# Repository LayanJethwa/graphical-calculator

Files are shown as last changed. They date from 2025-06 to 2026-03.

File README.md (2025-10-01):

## Graphical calculator ##

This design is for a graphical calculator that I am making, which will be able to plot graphs on a screen provided in human-readable infix notation.

I decided to make this as a fun maths-based project for my Computer Science NEA.

## Introduction ##

Graphical calculators and software are widely used in advanced mathematics. They are an easy way to visualise and analyse graphs and are useful in a classroom setting as well as to verify solutions to problems. Free digital softwares such as Desmos and Geogebra are used extensively, but they work best on computers, and it is not desirable to have them on phones either in a lesson. Physical graphical calculators are therefore used, created by companies such as Casio and Texas Instruments.

However, these physical calculators are very expensive. The Casio fx-CG50, one of the leading devices in the field, costs £140 from the manufacturer. These calculators are very good, with a multitude of features, but a lot of these features are very rarely used, adding to the price point unnecessarily. Additionally, these calculators function as scientific calculators as well, but people that own them generally also own a scientific calculator anyway that they use mainly for calculations.

I aim to create a physical calculator that is only for plotting graphs. This will be less costly to build and produce, and I will be able to tailor it to the end user. The hardware will be specialised, having a screen with a higher resolution than the CG50, and I will 3D print parts specifically for ergonomics.

## Features ##

- Explicitly defined graphs
    - Polynomials
    - Radicals
    - Exponentials
    - Reciprocals
    - Logarithmic graphs
    - Trigonometric graphs (sin, cos, tan and reciprocals)
    - Parametric graphs
    - Differential equations
    - Indefinite integrals
    - Combinations of the above
    - x = f(y) graphs
- Implicitly defined graphs
    - Circles
    - Ellipses
    - Parabolas
    - Horizontal parabolas
    - Hyperbolas
    - Multiple graphs simultaneously
- Graph manipulation
    - Pan
    - Zoom
    - View window
        - Axis bounds
        - Axis scaling
    - Graph colouring
- Buttons
    - Golden button
    - Degrees-radians ~~rocker switch~~ toggle switch
    - Zoom ~~momentary toggle switch~~ tactile switches
- Other features
    - Auto power-off

## Demo ##

You can see a software demo at the website: https://layanjethwa.github.io/graphical-calculator/code/build/web/

Currently it is not complete and I have only implemented methods for a few functions. As they will be triggered by physical switches on the calculator, they are triggered by keys currently:

| Keyboard key |  Calculator function  |
|:-----|---:|
| SHIFT + =  | + (addition) |
| SHIFT + 9 |  ( (left bracket)  |
| SHIFT + 0 | ) (right bracket) |
| SHIFT + 8 | * (multiplication) |
| q | squared |
| w | cubed |
| x | variable letter x |
| / | divide |
| p | pi |
| l | log |
| s | sin |
| c | cos |
| t | tan |
| r | csc |
| y | sec |
| u | cot |

The syntax of the log function is [base]log([value]), e.g. 2log(x) means log base 2 of x. Implicit multiplication is not currently defined for all functions.

You can use the arrow keys to pan around the graph, n to zoom in, and m to zoom out. When you enter the function, press enter to confirm, and then enter again to go to the graph page. You can also use the arrow keys on the input page to add more graphs to the display.

## Hardware ##

The PCB will be shaped like the calculator, and the switches for the buttons will be mounted to it directly. It will have connectors for the screen, CPU, and battery as well. 

The CPU I will be using is the Raspberry Pi Zero 2 W. It is 65mm x 30mm, so fairly small and will fit nicely in the calculator. It has 512 MB of RAM, and a clock speed of 1GHz, so it will not be able to handle more intensive computations. It has WiFi and Bluetooth connectivity, although I am not planning to use them, as well as a USB 2.0 port, a microSD card slot, a mini HDMI port, and a 40 pin I/O header. I will have to install an operating system on it, probably Raspbian, to run Python code.

The screen I have decided to use is a 3.5 inch LCD screen, intended for a display for a Raspberry Pi. It has a 320x480 pixel resolution, and also features resistive touch control, though I probably will not be utilizing that feature of it. The resolution is higher than the Casio fx-CG50, one of the leading graphical calculators, so it should be more than enough for my purposes. The screen is £24 directly from the manufacturer. The screen connects via ~~HDMI~~ TFT, and is powered by a micro USB connection.

I have decided to use tactile switches with attached shafts, which, as mentioned, will be soldered directly to the PCB. I plan on using the Omron B3F-1050 switches, which I can get from DigiKey, at around 12.5p each for the number I will require. They have dimensions of 6 x 6 mm with a height of 7.3 mm, which should be suitable for my purposes. I can buy keycaps for these switches, or 3D print them myself. I found many sites selling caps - there are some round ones on AliExpress for £2.79 per 100 caps, and also some square ones for £2.47 per 50 caps. I also found a model that I can 3D print, although this is for the larger 12x12x7.3 mm switches, but I can scale it down.

## Pictures ##

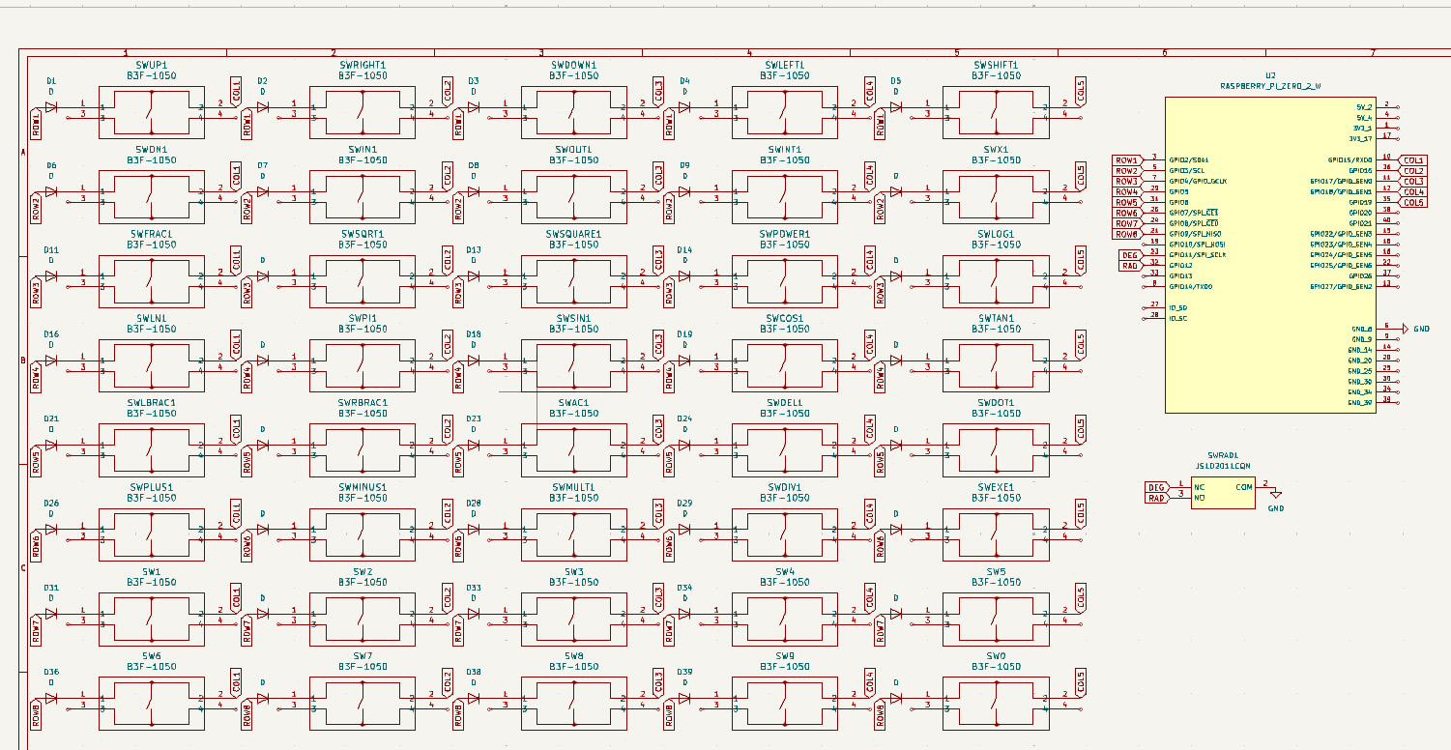
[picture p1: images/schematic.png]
Schematic

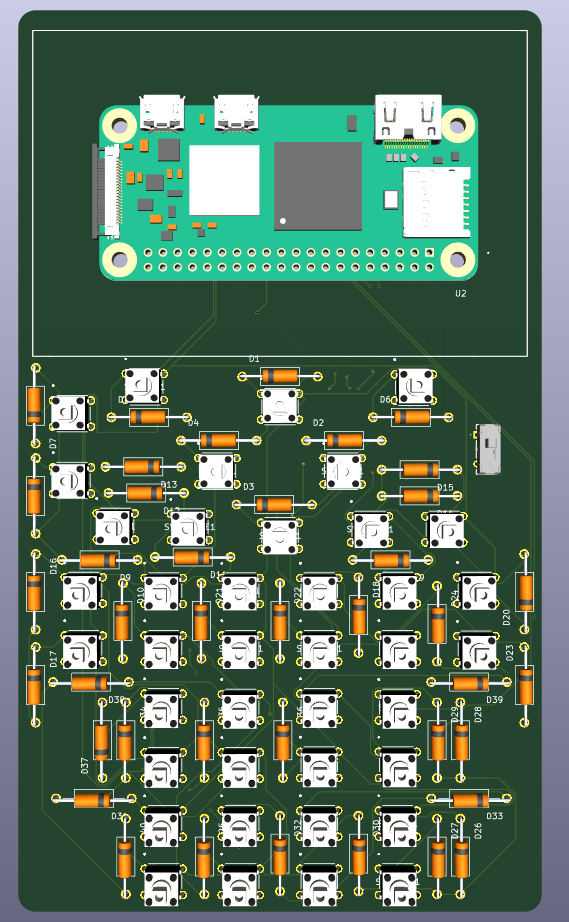
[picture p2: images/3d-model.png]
3D model

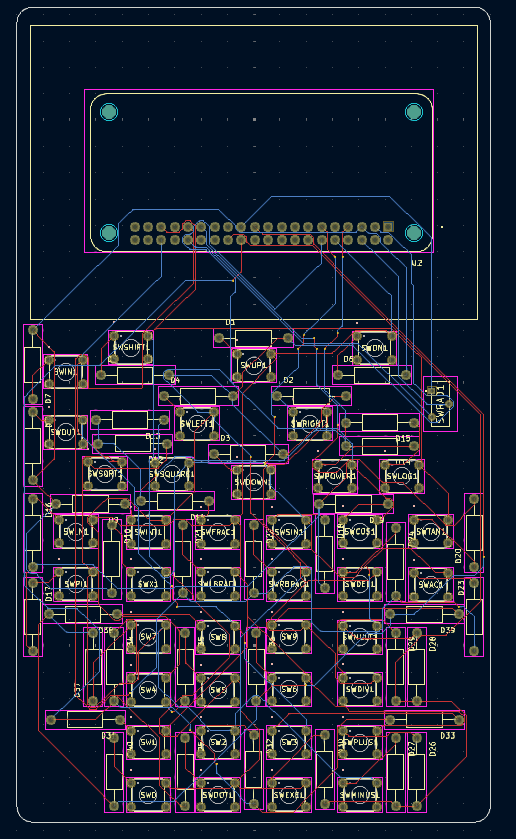
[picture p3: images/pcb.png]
PCB

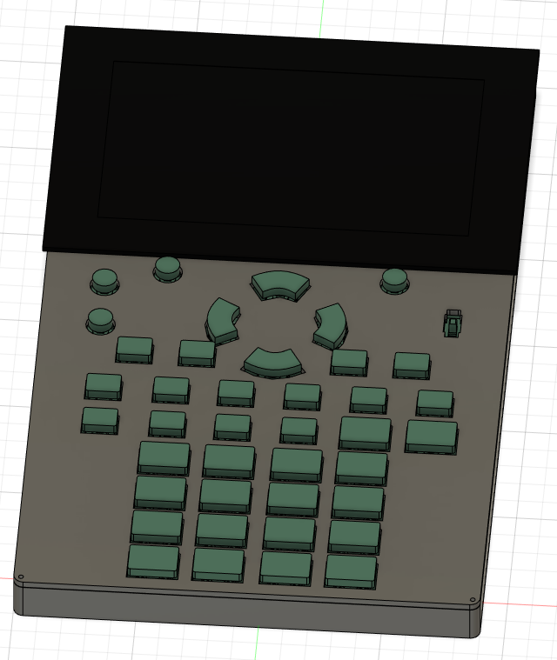
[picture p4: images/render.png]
CAD case


## BOM ##

|Part name|Quantity needed|Lot|Price|Link|
|-|-|-|-|-|
|PCB|1|5|$16.77|https://cart.jlcpcb.com/shopcart/cart/	|
|Raspberry Pi Zero 2W|1|1|$16.25|https://www.aliexpress.com/item/1005008147614202.html|
|Osoyoo 3.5in TFT LCD screen|1|1|$33.32|https://www.aliexpress.com/i/1005006494047405.html	|
|LiPo flat battery 5V 9000mAh|1|1|$11.52|https://www.aliexpress.com/item/1005005621203243.html|
|Omron B3F-1050|40|100|$16.95|https://www.aliexpress.com/item/4000012348941.html|
|JS2011CQN|1|1|$16.77|https://www.mouser.co.uk/ProductDetail/611-JS102011CQN|
|DO-35 1N4148|40|100|$1.02|https://www.aliexpress.com/item/1005004103990376.html|

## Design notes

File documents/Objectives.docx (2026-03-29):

Objectives

1. Create a parser for arbitrary polynomials
  a. Pre-processing
    i. Handle implicit multiplication (regex)
    ii. Write powers with exponentiation operator
  b. Conversion from infix to postfix notation
2. Generate a list of points for the graph
  a. Define interval
  b. Decide frequency of points
  c. Calculate x values through postfix stack
3. Create a mock-up display for testing purposes
  a. Create Pygame display compatible with screen (320x480px)
  b. Draw axes with defined interval
  c. Plot points
  d. Interpolate between points
4. Add translation functions
  a. Add zoom function
    i. Scale axes by factor centred on middle of screen
    ii. Recalculate points with new interval
    iii. Replot and interpolate points
  b. Add move function
    i. Change interval and recalculate points
    ii. Add reset button
5. Extend parser to other Cartesian equations
  a. Radical equations
    i. Parse roots with exponentiation operator
  b. Exponential equations
    i. Define constants (e, pi)
  c. Reciprocal graphs
    i. Parse fractions as division operator
    ii. Handle asymptotes
      1. Draw dashed line OR approximate continuously
  d. Logarithmic equations
    i. Parse logarithms as single character, allow for bases
  e. Trigonometric equations
    i. Parse main functions
      1. Handle tan asymptote
    ii. Parse reciprocal functions
      1. Handle asymptotes
6. Extend parser to parametric equations
  a. Allow for inputs of explicit y(t) and x(t)
  b. Determine bounds for t for given interval
  c. Parse each as Cartesian equations
7. Extend parser to calculus
  a. Differentiation
    i. Calculate x values for interval
    ii. Approximate central difference
    iii. Handle asymptotes (high gradient)
  b. Integration
    i. Calculate x values for interval
    ii. Use trapezium rule to get area of slices
    iii. Divide by strip width to plot y values
    iv. Handle asymptotes (high area)
8. Add support for multiple equations
  a. Add multiple input option with colour key
  b. Plot both graphs (different colours)
9. Testing
  a. Check basic test cases for all types of equation
  b. Check test cases for multiple types combined
  c. Test cases where calculus doesn’t work well
10. Design physical calculator
  a. Make list of buttons from what I was able to implement
  b. Arrange buttons in a layout
  c. Design electronics
    i. Create schematic with battery connected to raspberry pi
    ii. Connect buttons to raspberry pi in schematic
    iii. Connect rotary encoder for zoom OR use touchscreen
      1. Order screen to test code
    iv. Arrange components on PCB
    v. Add solar panel
      1. Connect to solar power manager and rechargeable battery
    vi. Route and wire PCB
  d. CAD design
    i. Design case
    ii. Design buttons
11. Build physical calculator
  a. Create BOM
  b. Order PCB
  c. Order other electronics
  d. 3D print CAD parts
  e. Solder remaining components to PCB
  f. Run program on raspberry pi
    i. Check power supply
    ii. Load and run on boot
    iii. Scale Pygame for the screen
    iv. Change code for touchscreen if required
  g. Assemble the calculator

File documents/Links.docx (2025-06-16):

http://www.lcdwiki.com/3.5inch_RPi_Display

3.5 inch display, touchscreen, 320x480px

https://www.digikey.co.uk/en/products/detail/omron-electronics-inc-emc-div/B3F-1050/11889

Tactile switches

https://www.printables.com/model/367373-tactile-switch-push-button-cap-12x12

Switch keycap round 3d print

https://hackaday.io/project/186263-finch-thumb-keyboard

Someone else’s keyboard, with BOM

https://stfn.pl/blog/09-pico-solar-panels/

Powering rpi pico with solar panel

https://thepihut.com/products/semi-flexible-polycrystalline-silicon-solar-panel-18v-10w

Small solar panel

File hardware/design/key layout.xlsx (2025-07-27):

zoom | shift | arrows |  | on | angle | shift |  | up |  | on
 |  |  |  |  |  |  | left |  | right
 | root | square | power | log
ln | integral | frac | sin | cos | tan
pi | x | ( | ) | del | ac
 | 7 | 8 | 9 | multiply
 | 4 | 5 | 6 | divide
 | 1 | 2 | 3 | plus
 | 0 | dot | exe | minus

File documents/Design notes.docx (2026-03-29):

Design notes for NEA

- High-level overview
  - How system interconnects
  - Flowchart/Hierarchy chart/Data flow diagram/Class or state diagram
  - Include notes explaining diagram
- External API design
  - Explore in detail
    - Example calls
    - Expected responses
    - Data pipeline
    - Error handling
- Key algorithm explanation
  - Choose 2-3 important algorithms to explain
    - Core functionality
    - Unique features
    - Pseudocode/flowchart
    - Trace with example input/output
    - Explain why chosen and how it meets the objective
- Data dictionary
  - Simple table summarizing variables or data fields
    - Name, type, example value, purpose
    - Only do for key algorithms, not for whole code
- Data structures explanation
  - Explain main structures used and why
- File structures and organization explanations
  - Show how code and assets are organized
  - Diagrams
    - Table/chart/screenshot of directory
    - Detailed explanations
- Validation
  - Discuss validation and error handling
  - Focus on user inputs, detailing how data is validated when entered or between functions and models
- UI explanation
  - Show main screens/menus with labels and explanations
    - Explain colour choices/layout
    - Mention how design meets end-user needs
  - Human-computer interaction principles
    - Visibility
    - Affordance - buttons look pressable
    - Feedback
    - Memory load - drop-downs/auto-fill
    - Natural language
    - Consistency
  - Justify against end-user
- Hardware explanation
  - Justify use of hardware and use and integration into product
- Design justifications
  - Link each major choice to user requirements
  - Explain alternatives considered and why rejected
  - Connect to objectives from analysis

To-do:

- Explain files
  - Graph display
  - Helpers incl. launcher.sh
  - Constants
- Data structures/key algorithms/data dictionaries
  - Expression tree
    - UML class diagram
    - Evaluate full flowchart
    - Render algorithm
    - Explanations
    - Go through comments
  - Evaluator
    - Data dictionaries for variables
    - Data structures explanation
  - Parser
    - Data dictionaries for variables
    - Data structures explanation
- File structure
- UI
  - Colour choices, layout
  - End-user needs
  - HCI principles
    - Visibility
    - Affordance - buttons look pressable
    - Feedback
    - Memory load - drop downs/auto fill
    - Natural language
    - Consistency
- Hardware
  - Justify use and integration
- Go through and justify

Technical skills

FULL COMMENTED CODE - comment reasonable amount, explain how each function works, comment to explain why not what

Copy and paste code as appendices

Attribute code for AI gen, borrowed code, etc. - citation method and percentage estimate

Coding style table - simple table explaining skill/technique (validation, OOP etc.), then reference code line numbers/screenshots for proof - follow AQA checklist in spec/firefly

Technical skills table, also list other skills that you are proud of at the bottom if desired

Testing

Clear evidence demonstrating robustness and requirements of solution

Test table - objectives, then prove/disprove rigorously

Normal, boundary and erroneous data

Destructive tests

Comment expected and actual outcome, then thus pass/fail

If fails, fix with suitable evidence where possible

Screen recording of system working, one compiled video, commentary, 2-3 mins, validate outputs

Full evaluation

Consider how well the outcome meets all requirements, fully detailed

How outcome could be improved - detailed consideration

Independent feedback that is useful and realistic, evaluate and discuss

Honest reflection on project success, comparing final product to initial vision, acknowledging strengths and weaknesses

Focus on initial objectives, analysis on how well they were met, reference testing section and user feedback, discuss quality of implementation and note partial achievements (can do in testing and user feedback and just summarize if desired)

How it could be improved - following user feedback - realistic and specific

Feedback obtained and analyzed by 3rd parties

Acting on user feedback - give evidence

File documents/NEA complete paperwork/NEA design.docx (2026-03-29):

Overview

The project uses modularisation and functional decomposition to split the different tasks required. The main areas are the frontend, which involves the display, UI, and handling of user input; and the backend, which involves calculating and plotting the graphs, and processing the user input. The program runs from the file main.py, which mainly handles user input, and then utilizes other modules to link to the backend of the program and build the user interface.

Below is a list of all the different modules used in the program, with the highlighted ones being ones that I have coded myself:

Name | Type | Function | Details
pygame | library | display | Provides display, geometries and text rendering for UI
RPi.GPIO | package | hardware | Interfaces between Raspberry Pi pins and software
os | module | hardware | Used to send the shutdown command through the system shell
time | module | hardware | Used to provide buffer between button presses to avoid CPU stress
traceback | module | backend | Logs error messages
main | module | all | Handles user input and links other modules together
evaluator | module | backend | Creates lambda function from postfix expression and evaluates at given points
parser | module | backend | Creates postfix expression from tokenized infix
expression_tree | module | backend | Implements OOP system for inputting, rendering and evaluating maths expressions
math | module | tools | Provides mathematical functions
constants | module | tools | Stores commonly used variables and values
helpers | module | tools | Provides useful functions not project-specific
input_display | module | display | Handles rendering and moving in input mode
graph_display | module | display | Handles rendering and moving in graph mode

The modules are all generally interconnected, as can be seen by the below diagram (ovals are external libraries/packages and rectangles are part of the project)

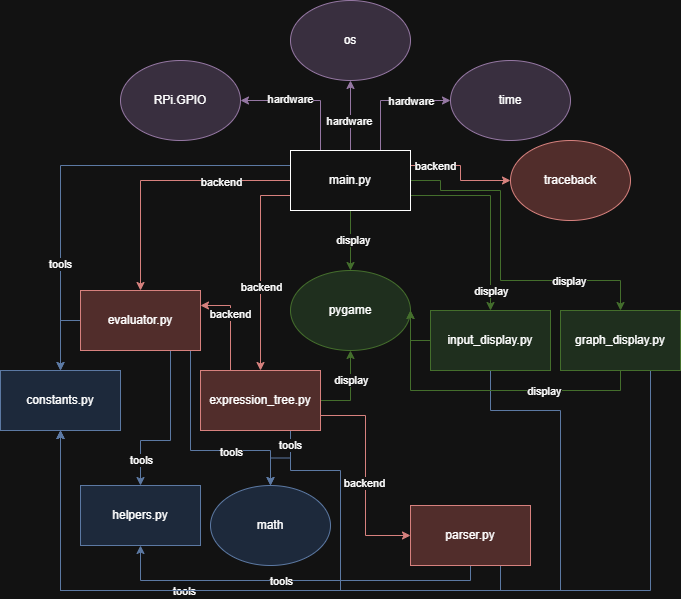
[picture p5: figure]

Main file (main.py)

The main file of the calculator runs based on a game loop of 60 Hz. The operations executed in each loop are triggered whenever the user presses a button, which causes the program to run through a series of conditionals to determine what to do next.

The calculator has two modes - input mode, which allows the user to enter equations to be plotted; and graph mode, which plots the graphs on a set of axes. I will explain each mode in greater detail further on.

At the start of the main file, there is a procedure reset() which initialises the program and is also called in case of an error so that the user can continue to use the calculator even if there is some bug. This is done through a try/except block wrapping the contents of the main loop and is helpful for avoiding the need to validate equations entered - if the parser cannot handle it, it will simply throw an error which will be caught by the block. This means that validation is only necessary once, as opposed to using it in every module. If an error is caught, it is written to a file logs.txt, which is helpful for later debugging.

The main variables initialised are shown below:

Name | Type | Values taken | Purpose
display_mode | String | “input” or “graph” | Sets the mode for which screen to display
functions | List of Expression objects (custom class) | Expression object | Holds objects for each of the 7 functions that can be inputted by the user
cursors | List of Cursor objects (custom class) | Cursor object with parent as corresponding function | Holds cursor objects for each of the 7 functions that can be inputted by the user
view_window | List of strings | String representation of a number | Holds the values for each of the 4 view window options that can be inputted (min and max for x and y)
selected | Integer | Integer between 0 and 10 | Currently selected function or view window field
cursor_active | Boolean | True or False | Whether the cursor is currently active (user is inside field)
shift_mode | Boolean | True or False | Whether the shift modifier is currently active
angle_mode | String | “RAD” or “DEG” | Which unit to use for measuring angles (when plotting trig functions)

The main file also contains a procedure render_graphs(), which, as the name suggests, renders the entered functions as graphs. This is called when switching to graph mode and can be thought of as the link to the “backend” of the program. Below is a high-level flowchart of the procedure:

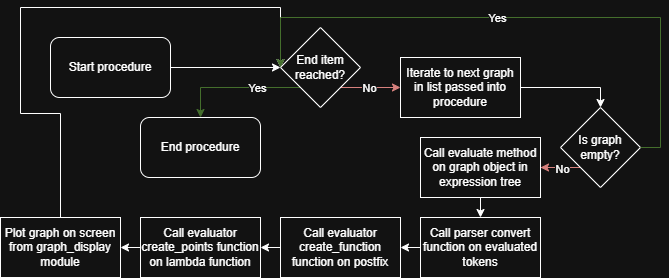
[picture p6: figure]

From the flowchart, we can see how this procedure links together most of the files in the program, effectively abstracting the actual calculations away from the user for the computer to render the inputted graphs.

Below is a flowchart of the workings of the main file:

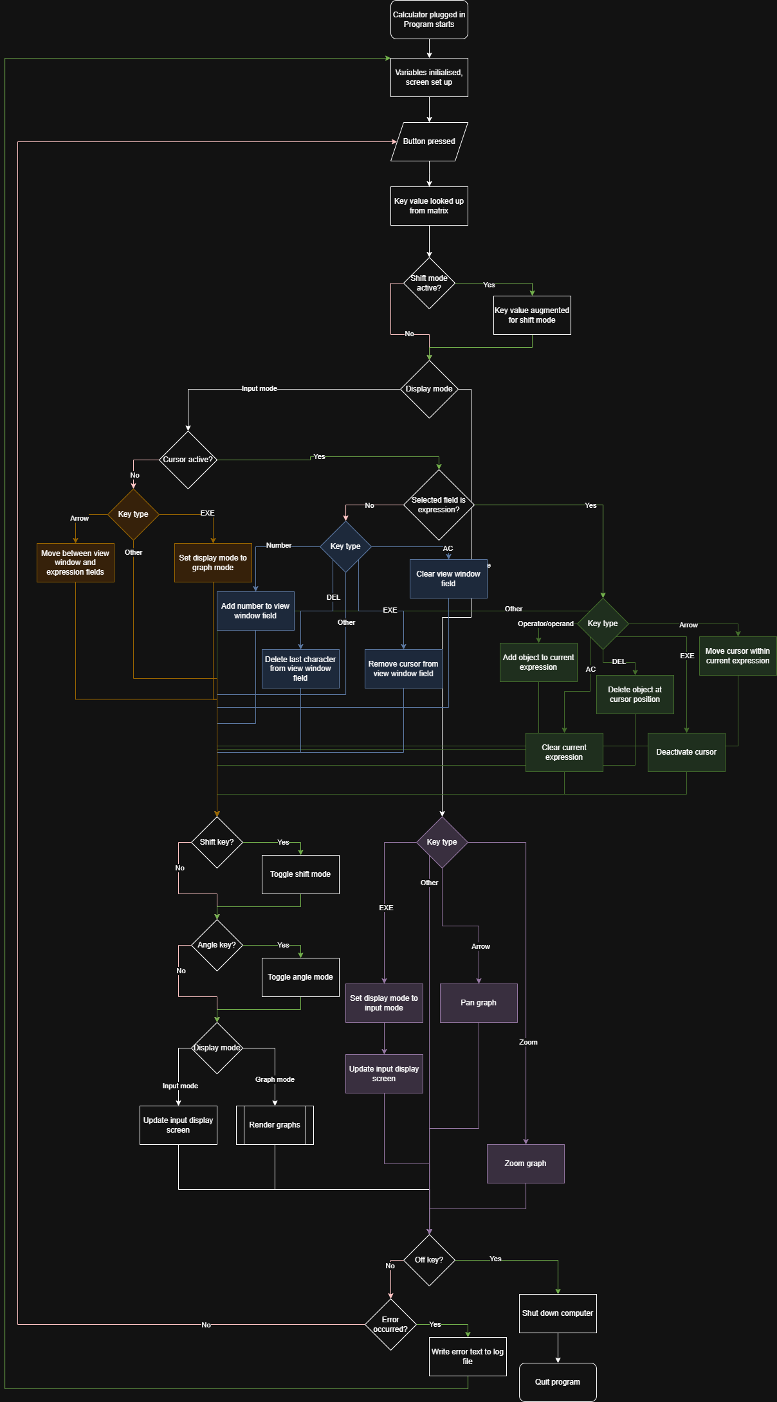
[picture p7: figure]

It can be seen that the program works from a series of conditionals testing the initialised variables to determine the mode of the user, and, if in input mode, whether the cursor is active or not, and then whether the selected field (if there is one) is one of the fields in the view window, or an expression field.

The distinction between the view window fields and the expression fields are primarily due to the difference in the way that they are stored - the view window, being just a number, is simply stored as text, with the cursor represented by a pipe character appended to the end of it. The expression fields were also initially represented in this way, but I have now refactored them to use a custom-built expression tree, allowing for more robust parsing and rendering, as well as allowing things such as nested radicals or fractions.

Next, I will talk briefly about the two modules that help with the actual display of the frontend for both the graph and input modes.

Input display (input_display.py)

The input display module has two functions - update_screen and move. These handle the Pygame rendering of the backend data and are called by the main file periodically to update the display.

The update_screen procedure takes arguments screen, functions, selected, view_window, cursors, cursor_active, shift_mode and angle_mode, and renders each of the functions onto the screen by calling their render method within the expression tree. The procedure also draws the boxes and fields for the data that will be rendered, as well as other graphics such as the colours for each function, and the shift and angle modes.

The move function handles the selection of fields and updates the passed in selected value as well as handling the cursor and appending it to the view window strings if necessary. The model that is used throughout the code is that the main file contains all the variables necessary, and these are then passed through each of the other files as needed.

I have mentioned the view window a few times - this is a set of 4 fields for minimum and maximum x and y values, and the user can input values in them to change the bounds of the axes that the graphs are plotted on.

Graph display (graph_display.py)

The graph display module similarly has functions update_screen and move, but additionally has plot_graph and zoom. The update_screen function simply draws the axes for the graph onto the screen, along with labels for the bounds of the axes.

The move and zoom functions work according to the same concept - the user input changes the bounds of the graph based on what they have done, and then the graph itself is recalculated and plotted with the new bounds. Both functions modify the variables for bounds found in the constants.py module, which also stores things such as the zoom scale factor and the width and height of the screen.

The plot_graph function works by taking the provided mathematical function, which is defined using lambda calculus (a system of functional abstraction defined in many programming languages, which essentially allows functions to be stored in a way similar to variables, allowing manipulation that is not possible with the usual way of defining functions). A list of points is generated at fixed intervals based on a frequency set in the constants.py file, which are x values, and are then fed into the function to give the corresponding y value. If a value cannot be generated (undefined mathematically for example), a None value is created instead. When the points are then plotted on the axes, a line is drawn between the previous and the current point if both are defined, which provides a system of linear interpolation to plot the graphs.

I had previously considered using other types of interpolation, but linear interpolation works well for my needs as it is quick and easy to calculate, and the frequency of points calculated is high enough that linear interpolation gives an approximation of the graph that is near-perfect. As the graph is recalculated at different zoom levels, the interpolation stays with the same frequency, which gives a consistent rendering of each graph.

One barrier I found was that at very high zoom levels, the numbers cannot be stored in binary as floating-point numbers without losing accuracy, as they become incredibly small, and this also puts a lot more strain on the CPU when storing the numbers as well. Unfortunately, there is no viable fix for this to allow infinite zoom levels as the computer simply is not capable of storing numbers with infinite precision. I have therefore capped the maximum zoom in, and similarly the maximum zoom out (again as the numbers get larger more bits are needed to store them which impacts the speed of the program). Additionally, the calculations take more processing power and thus time to do when the numbers become extremely small or large, which also impacts the speed of the program.

Helper files (helpers.py and launcher.sh)

I also have some lightweight helper files which provide key functionality for ease of coding. The helpers.py file firstly contains a function frange, which is a custom implementation of the range function but for floating point numbers, so that instead of having to manually scale the range to the bounds of the graph, I can call this function with the bounds and the frequency I want to generate the list of x values to plot.

The file also contains a class SafeList, which inherits from list, and simply returns a default value if the index is not found. This is helpful for my implementation of a queue and a stack for the parser, as I don’t have to handle edge cases in the parser itself. By moving input validation a layer down to the actual data structure, I don’t have to worry about handling it at the user level, which effectively abstracts it away whilst I am coding.

The launcher.sh file is a shell script that runs on the Raspberry Pi when the system boots up, and simply navigates to the folder which the program is stored in and then runs the main.py file, so that the program starts as soon as the user turns on the calculator. It does take a couple of minutes to boot up the system, but this is unavoidable with the current hardware, and it is unfeasible to keep the Raspberry Pi on all the time as I want the calculator to run off battery power, so leaving it on would drain the battery.

Constants file (constants.py)

The constants file, as referenced previously, contains lots of different constants and variables that need to be accessed by lots of different files within the codebase. It is helpful to have these all in a separate file as it means that nothing is hardcoded, so values such as the frequency of the graph sampling can be changed easily in only one place, which also eliminates redundancies. There are 3 main sections to this file - parsing, graph rendering, and input. I have kept a consistent style in this file with each variable being in all caps, which VS Code formats differently, which helps with readability and ease of development.

The parsing section contains lists that help the parser reference certain types of functions and manages order of operations. There is one list for right-associative operators, which are operators that evaluate from the rightmost one if chained together, such as the exponentiation operator. The only operator in this list currently is negation, as all of the main functions are now evaluated within the expression tree rather than by the parser, but the concept still holds. There is also a list for precedences, which contains the basic operators, and tells the parser which order they should be evaluated in. This comes with an associated procedure to convert the list into a dictionary so that each operator is given a number for precedence.

The graph rendering section contains a series of variables which define the bounds and other associated values for the axes that the graphs are plotted on, as shown below:

Name | Type | Default value | Purpose
DEFAULT_FREQUENCY | Integer | 300 | Number of samples of the function to take
WIDTH | Integer | 480 | Width of the screen in pixels
HEIGHT | Integer | 320 | Height of the screen in pixels
XMIN | Integer (can be float) | -15 | Minimum x bound
XMAX | Integer (can be float) | 15 | Maximum x bound
YMIN | Integer (can be float) | -10 | Minimum y bound
YMAX | Integer (can be float) | 10 | Maximum y bound
XDIFF | Integer (can be float) | 30 | Length of x-axis (XMAX-XMIN)
YDIFF | Integer (can be float) | 20 | Length of y-axis (YMAX-YMIN)
SCALEX | Float | 16.0 | Scales x values to pixels (WIDTH/XDIFF)
SCALEY | Float | 16.0 | Scales y values to pixels (HEIGHT/YDIFF)
X0 | Float | 240.0 | Where x=0 is on the pixel grid (-(XMIN*SCALEX))
Y0 | Float | 160.0 | Where y=0 is on the pixel grid (HEIGHT + (YMIN*SCALEY)
AXIS_LABEL_LENGTH | Integer | 3 | Size of axis labels
ZOOM_SCALE_FACTOR | Integer | 2 | How much to scale the axis by when zoomed
WSCALE | Float | 5/3 | Width scale for hardware screen (screen larger than expected)
HSCALE | Float | 3/2 | Height scale for hardware screen

These variables can all be edited as required to ensure a smooth display on the hardware screen, and are referenced primarily in the graph_display.py file when rendering the graphs. There is a procedure update_bounds which recalculates all of the above variables that are dependent on the bounds variables, so that any updates to the bounds are reflected in the other variables.

The input section of the file contains lists of each of the different types of inputs (unary/binary operators, numbers, symbols, variables, arrows, zoom, trig functions, brackets), which are used in the conditional logic in the main.py file to determine what to do with the user’s input.

It also contains a key matrix for each of the buttons. On the physical hardware, the buttons are implemented in a matrix, so both a row and column have to be triggered for each button (I will explain this in more detail in the hardware section). The constants file therefore contains pin numbers for each of the rows and columns, and then a matrix of values corresponding to each row and column, which is referenced whenever a button press is detected. When testing on my laptop, I instead have a dictionary of keys, which maps Unicode characters from keyboard presses to the key values, so that I can simulate pressing a button on the calculator.

In addition to these 3 sections, I also have defined some RGB tuples for colours used in the rendering, and the mathematical constants e and pi. There is also a list EDIT_TEXT which contains characters that are rendered next to the text in the view window as part of the UI (pipe for cursor and ellipsis).

Expression tree (expression_tree.py)

The main backend of the program is in the object-oriented expression tree. The tree implements every operator and operand that the user can enter, as well as methods to render and evaluate expressions, which are then passed through to the relevant modules, as I will show.

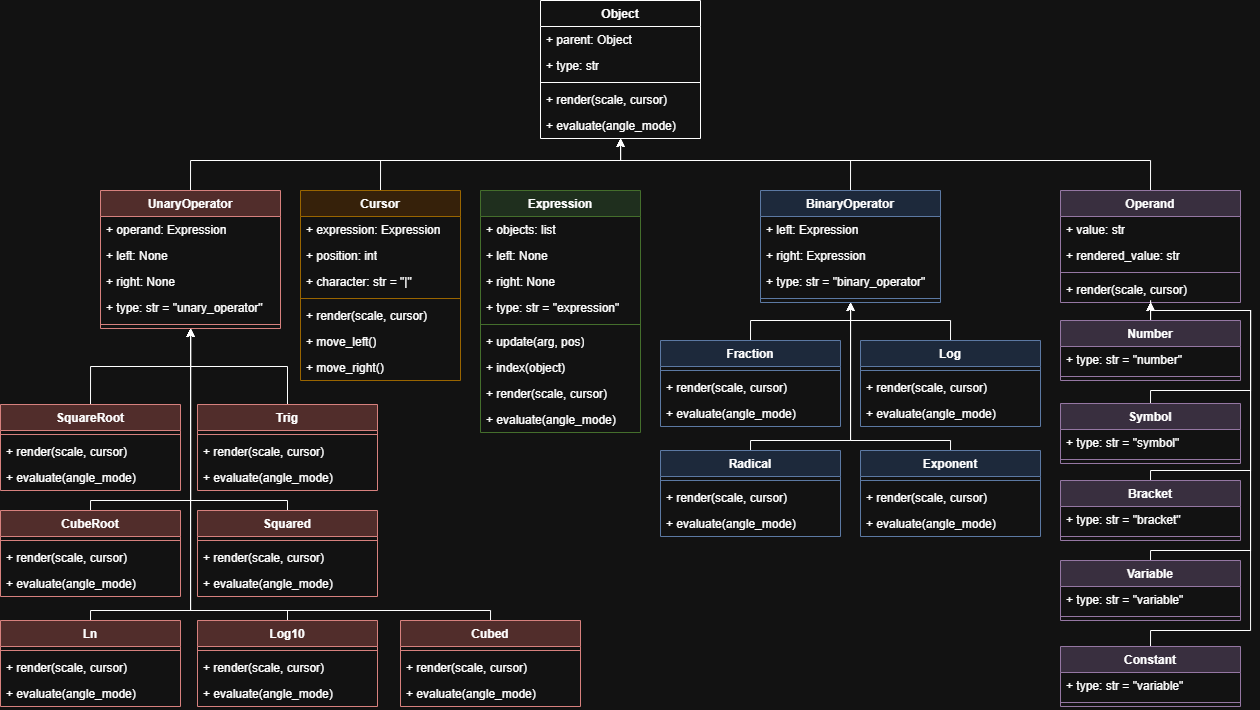
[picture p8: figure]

Below is a UML class diagram for the full expression tree:

It can be seen that the tree is rooted at the object node, which implements the parent and type attributes, and shells for the render and evaluate methods. Other subclasses are then grouped based on type, and the methods are implemented for each of them. Of note are the ways in which operands of functions are represented - every operand is an Expression object (which is in practice just a list of other objects). Binary operators have a left and right attribute, for the two operands which they contain, whereas unary operators have a single operand attribute.

The left and right attributes are implemented but defined as None for unary operators and expressions so that the program can modify the attribute if it exists, but access it regardless - this means that validation is not necessary for operators as the program can tell whether it is a binary operator or not by whether the left attribute is None.

The evaluate and render methods are defined for each object in the tree so that they can be called recursively. I handle the main operation of each method in the Expression class, and call the method recursively for each object in the expression.

Below is a flowchart for the evaluate method as implemented in the expression tree:

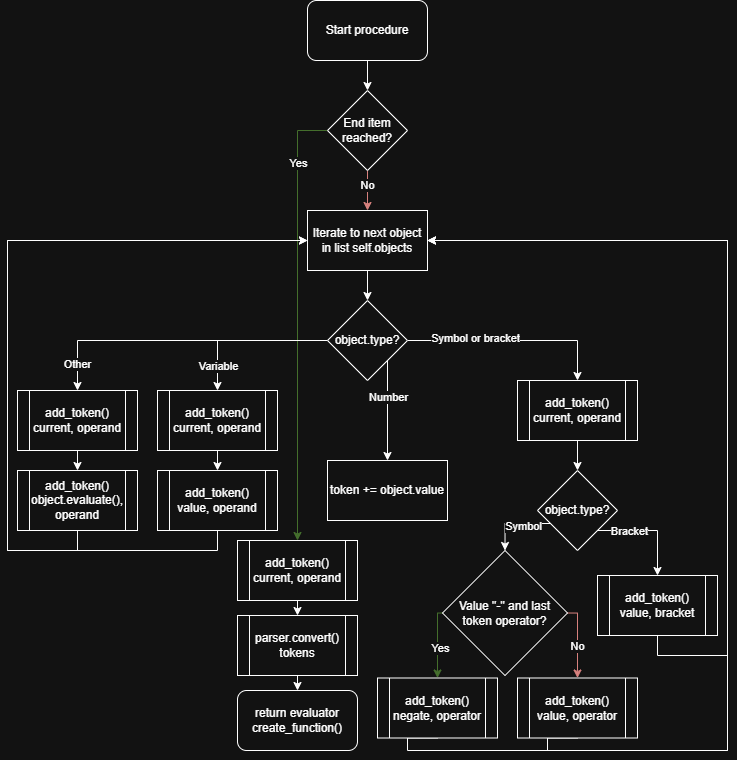
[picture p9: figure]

The add_token() procedure handles implicit multiplication and tags the tokens as they are added, so that in the parsing stage they can be more easily identified. Implicit multiplication is handled by considering each of 3 cases - an operand followed by a left bracket, an operand followed by a variable, or an operand followed by a lambda function (which is the result of calling the evaluate method on a unary or binary operator; essentially where a function would have been written in infix notation). For the purposes of this algorithm, a left bracket is treated as an operator and a right bracket as an operand, and the mathematical constants e and pi are treated as variables.

Unary negation is also handled by the evaluation algorithm, which adds it as a separate operator when tokenising rather than having to determine the type of operator a minus sign is at the parsing stage. This evaluation algorithm outputs a list of tokens, which are then converted by the parser from infix notation to postfix notation, and then evaluated by the evaluator module, which returns a lambda function. Because each component object also returns a lambda function when evaluated, the result of recursively calling the evaluate method is a single lambda function, which different x values can then be inputted into to get the corresponding y values.

The values returned by the functions (unary and binary operators) are mainly using the math module, or mathematical operators, and packed into a lambda function defined in terms of x. I experienced one problem when defining the calculations for radicals - a root of degree n will have n solutions by definition, however some of them may be on the complex plane, which is not useful for plotting real values. The roots are calculated by exponentiating the operand to the power of 1/n, which returns the principal value for each root - this can be a complex number. The solution I found for this is to take the absolute value of the operand in the calculations, and then change the sign afterwards - for example, the cube root of -8 gives 1 ± i√3 and -2, of which -2 is the only one we want, but one of the other two is the principal value - by instead taking the cube root of 8, which gives us the principal value of 2, and then negating it, we can get just the real-valued answer.

The rendering algorithm is less complex, but works recursively as well in a similar way. The render method for each object takes a cursor as a default argument so that if the expression is selected, the cursor can be passed through the function calls and rendered as necessary. The algorithm returns a single Pygame surface, which can then be rendered onto the screen in the correct field. Each object in the expression is rendered onto a new surface, which is then scaled to whatever size it needs to be, which is determined by the scale argument. This means that, for example, if an exponent operator needs rendering, the child expression for the exponent (which is the right child) can be rendered with scale 0.7, and it is then scaled down to match the surface.

Some problems with this approach are if nested objects such as powers or roots become too small on the screen - I have chosen not to fix this problem as it would require either capping the number of nests, which would not be a robust solution, or capping the scaling down at some point and adding a scroll mechanism so that the user can access all parts of the expression, which would not integrate very well with the current screen, and also would be a fair bit of work to implement.

There is a similar problem with the idea of scaling the expressions down, as they inevitably lose resolution in the scaling. I have introduced a dynamic font size for text that is rendered directly with Pygame, which helps to combat this issue, but for characters such as radicals, which I am drawing with Pygame’s geometry, it works better to scale down the object at the small cost of some sharpness than to attempt to draw the geometry as parametrized based on the scale of the object. Additionally, fixing this would require each object to know the overall size relative to the entire expression, not just the parent object, which is an extra variable to track and pass through the function calls and would make the code a lot messier.

Parser (parser.py)

The parser module has a single function, convert(), which takes a tokenized expression in infix notation, and, using the shunting-yard algorithm, converts it to postfix form. As the expression tree handles complex functions, this algorithm only needs to worry about the basic operators. Implicit multiplication and unary negation were also handled previously by inserting operators into the tokenized form where needed, so we do not need to detect these in the parser either. Each token consists of a value and tag pair, which tells the parser the actual value of the token, and what type it is for easy conditional checking.

The shunting-yard algorithm uses a stack to keep the operators on, and a queue to push the operands and operators to, which is returned when the algorithm terminates.

Name | Type | Purpose
out_queue | queue implemented as helpers.SafeList | Objects are pushed to it to create the postfix notation
operator_stack | stack implemented as helpers.SafeList | Operators are pushed and popped to it to move them so that the infix notation can be converted to postfix

We want the expression to be in postfix notation as order of operations is encoded, so it simply has to be evaluated from left to right, with operands stored on a stack and then popped whenever an operator is encountered. This also eliminates the need for brackets, which greatly simplifies the evaluation process.

The algorithm is called from the parser module on the tokens from the evaluate method of the Expression objects in the operator tree, and the result is then passed to the evaluator to return the lambda function that can be plotted on the axes.

Below is a flowchart of my implementation of the algorithm:

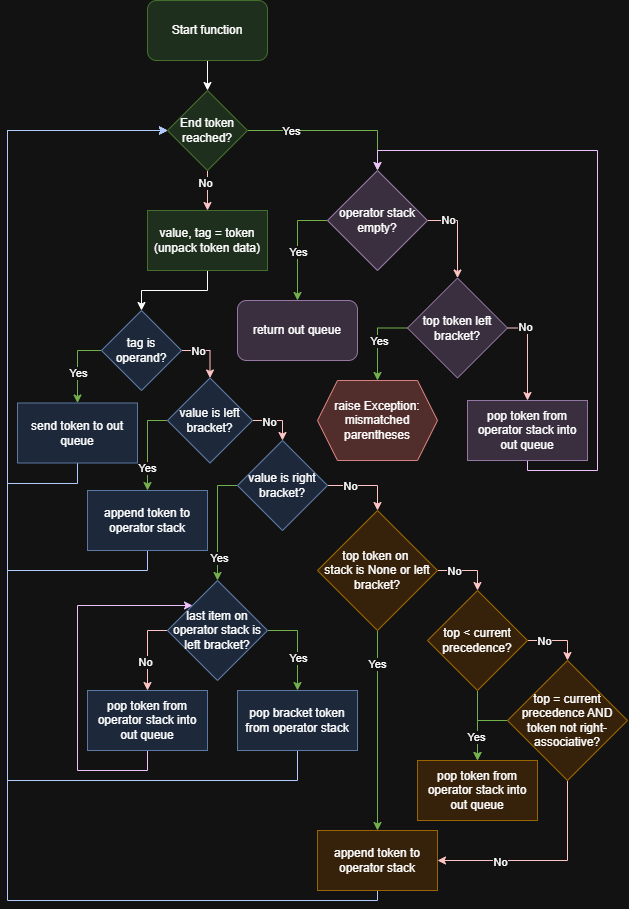
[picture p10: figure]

The module previously included a processing function, which took the expression as a raw string of text, and made heavy use of regular expressions to tokenise it: this was however a solution that was quite difficult to iterate upon and not very readable, and as a result there were numerous bugs and edge cases, and it was not robust. As I later created the expression tree, the need for this pre-processing no longer exists, because operators and operands are stored as objects, and they are tokenised where necessary in the actual expression tree before being passed through to the parser.

Previous versions of the convert() function also included checks for unary and binary functions, and brackets as part of function calls - as the expression tree holds functions as their own objects, they are evaluated previously, so are just treated as operands at the parsing stage.

Evaluator (evaluator.py)

The evaluator module is called directly after the parser, and takes the list of tokens in postfix notation, firstly creating a lambda function from them in create_function(), and then creating a list of (x, y) tuples which are plotted to the screen in create_points().

The evaluator (and expression tree evaluation) utilizes the concept of functional programming, by using first-class functions, whereby functions can be treated as other variables would be. In Python, this is done using lambda calculus. As functions are treated as variables, they can be passed into other functions: for example, if there was a function a(x): return x+2, I could then define a function b(x): return a(x)**2 - this would return whatever the value for a(x) is squared, so it is equivalent to b(x): return (x+2)**2. This is very powerful in my recursive method, as it means that functions can be created individually for each object, and then passed into larger functions to combine the entire expression into one function in the end.

The create_function() method works by iterating through each token, and pushing it to a stack if it is an operand. If it is an operator, it pops the last value (last 2 for binary functions) off the stack, and creates a lambda function with the operation applied to the operand, which is then pushed back onto the stack. This process continues until (if all goes well), the stack contains only 1 item, which is a single lambda function encompassing the entire expression. All the lambda functions are defined in terms of x - I would like to add implicit functions and parametric functions at some point, but I did not have time to add them to the main project.

A stack is useful for this algorithm as the postfix notation works by doing the operation on the previous operand(s), and a stack is a last-in-first-out data structure, so the previous operand will always be the first to be popped from the stack.

Previous versions of this algorithm implemented trigonometric and logarithmic functions as well, but as I have now created the expression tree, these are evaluated before reaching this stage, so there is no need to include them in this module.

After the lambda function is obtained, the create_points() function is called - this firstly generates a list of x-values using the helpers.frange() function, and then calls the function for each x-value, and appends the tuple of (x, y) to a list of points, which is then returned, to be passed through to the graph_display.py module, which will render them on the screen.

File structure

The project is broken down into 2 main folders - code and hardware. The code folder contains all of the software that I have written, as well as some font files as assets. There are slightly different versions of the code files in my actual project folder due to the difference between testing the program on my laptop and running it on the actual hardware, though the changes are minimal and so not useful to look at in detail.

The hardware folder contains 5 main sub-folders - assets, cad, design, pcb and production. These folders contain the files needed for the design of the PCB and the 3D models. The assets folder contains symbols downloaded from the Internet, which allow me to import the specific hardware I am using into the EDA software. The cad folder contains 3D models for the case that I have created myself, and the design folder has a rough layout for the buttons on the calculator. The pcb folder contains the files that the pcb is saved as from the EDA software, and the production folder contains the files needed for the PCB to be fabricated.

Below is a diagram of the file structure - I have coloured folders in orange, assets downloaded from the Internet in red, my code in green, and the hardware files that I have created myself in blue:

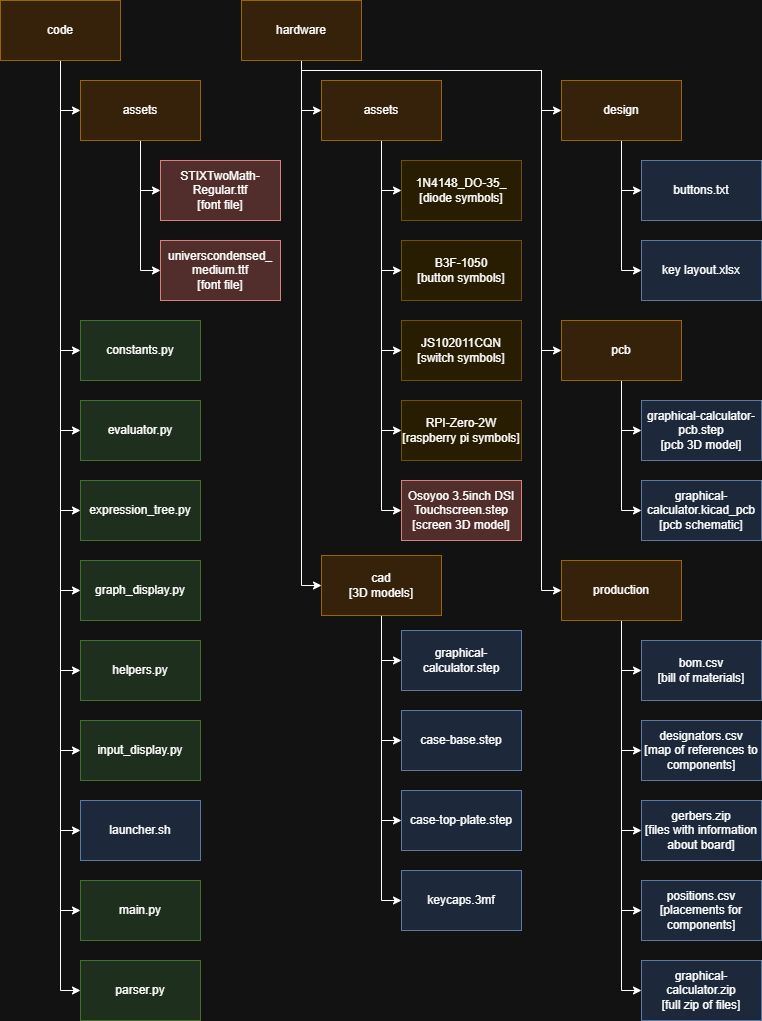
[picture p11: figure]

User interface

The user interface is designed to be quite simple, and easily understandable by the user. I have modelled it off similar interfaces on other graphical calculators, mainly the Casio fx-CG50, as I discussed in my initial analysis. As mentioned above, there are two screens - the input display and the graph display.

Below is a screenshot of the input display:

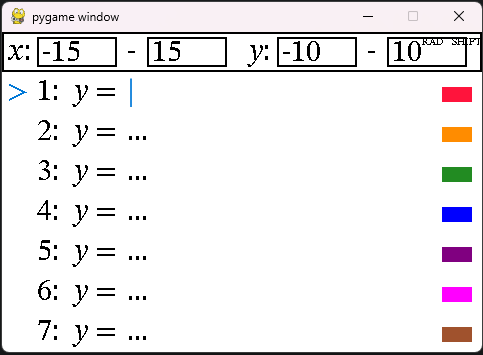
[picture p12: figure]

The angle mode and shift buttons are slightly overlapping with the input fields, but this is only with the resolution on my laptop - on the hardware they both look fine. I have chosen the colours specifically so that they show up well on the physical screen, and they are sufficiently different from each other, so they do not get confused. You can see above there is an indicator for the currently selected line, as well as the cursor. The view window is at the top of the screen, and the aim is that it is fairly intuitive as to what it does.

Due to the indicator and labels for the fields, it should be quite easy for the user to see what to do. The buttons are on the physical hardware, so very little input validation is needed, and as they are physical buttons it should be obvious to the user that they can press them. There is ample feedback when the user presses buttons, with the field updating with the mathematical expression, and the angle mode and shift indicators changing based on the user input. No memory load is needed for the user, as they are only restricted by the physical buttons that can be pressed - otherwise they have freedom to enter whatever expression they want, and it is validated at the evaluation stage.

There are no text prompts for the user, but the language used for labels is standard mathematical language which should be easily understandable to an A-level maths student, my end user. The display is also consistent in styling and input - the same screen is returned to from the graph display mode, and the inputting for the view window and the expressions is the same.

The end user needs to be able to easily input mathematical expressions, and the position and layout of the physical buttons allows for this, as I have tried to make them as similar to already existing calculators as possible.

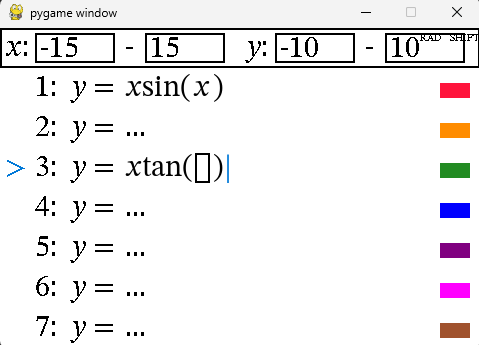
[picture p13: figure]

You can see above how the expressions inputted show an empty box for fields that have not yet been inputted by the user, and how the user can navigate between the different fields. Within each expression, the user can use the left and right buttons, and in the main screen, they can use the up and down buttons, and enter to select - this should hopefully be fairly intuitive.

The graph display screen can be seen below:

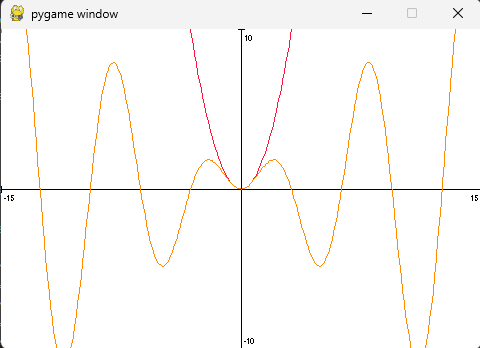
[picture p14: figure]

It is a fairly simplistic minimal design, and allows multiple graphs to be plotted on it at the same time. There are axis labels for the bounds, and the axis is drawn in - apart from that, it is empty, so as to not confuse the user or clutter the screen.

A-level maths students, the end users, will be familiar with graphs, so this screen should make sense to them, and the colours being consistent with the input display screen helps with this. The EXE button can be pressed to return to the input display screen - as the user has already had to press this to plot the graph, which logically makes sense, it should be easy for them to realise that they have to press it again to return. This screen should therefore be easily understandable by the user.

Validation

As discussed, as the calculator is a physical device, the only inputs that the user can enter are the physical buttons, so they are quite heavily constrained. Because of this, the need for input validation is highly reduced.

The main input validation that I have is a try/except block covering the entire game loop, which logs any errors to a text file before resetting the program. This is sufficient to handle the majority of errors that may be encountered. I also have a try/except block around the view window bounds calculations, to catch things such as 0 width ranges resulting in a division by zero error.

In my helpers file, I have a class Safelist, which returns a default value if a value is indexed that does not exist in the list, so I do not have to handle errors for the algorithms that implement this for queues and stacks.

Again, as the user is severely restricted in how they interact with the program, there is no need for further validation.

Hardware

The hardware I have used is primarily a Raspberry Pi Zero 2W, as discussed in my initial analysis. I have found that it works well for my needs, as I have loaded the Raspbian OS on, in which I am able to run Python and Pygame programs. I can SSH into the device to put the code onto it, and I have created a shell script (launcher.sh) to auto-start the program on boot. The buttons are the Omron B3F-1050 switches as discussed in the analysis, which have good tactile feedback and work well. I have 3D printed keycaps for the buttons - a problem here is that the size of the buttons and thus the keycaps means that the text printed on them is quite small, however I believe it is still readable, and I always have the option to write the text out on paper and affix it to the keycap for maximum readability.

I have 3D printed a case, which is not perfect, but I will be iterating on it to enable the design to be more compact. Some challenges I came up against were measuring the calculator for the case, as it is not a perfectly cuboidal object, and also when soldering the board, I initially soldered all 40 switches 90 degrees perpendicular to where they should have been, as, unbeknownst to me, the model for the switch in KiCad had accidentally been turned round by 90 degrees. Thankfully, I had enough extra components to resolder the whole board - I decided to do this on another board rather than attempt to desolder components first as this would have taken longer.

To create the PCB, I had to firstly create a wiring schematic, as seen below:


This involved finding symbols for each of the components on the internet and then connecting them in the program.

After this, I created the PCB model, where I had to arrange the components on the board and then put in the wiring, as below:


Finally, I created a 3D render of the completed PCB, which I then imported into Fusion360 to create a 3D model of the case around it, as well as the keycaps and top plate.


I could then 3D print the case and keycaps to build onto the full calculator.

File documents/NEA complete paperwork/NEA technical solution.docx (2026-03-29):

Coding style table

Below is a table explaining the different coding techniques that I have used in the project:

Skill/technique | Example | Code reference
Meaningful identifier names | Used throughout code, examples in constants file | All but see constants.py for example
Annotation used effectively | Used throughout code, examples in evaluator file | All but see evaluator.py for example
Consistent style throughout | Uses of whitespace consistent with new lines, spaces around operators, function and class naming consistent largely following PEP-8 | All but see expression_tree.py for example
Self-documenting code | All functions and most variables named so as to be easily understandable without much need for comments, especially with class names in expression tree | All but see expression_tree.py for example
Appropriate indentation | Forced by Python | All
Use of constants | Constants file contains mathematical constants and dimensions for the rendering, as well as basics such as colours and key names | constants.py
Managed casting of types | Numbers passed into expression tree as strings, so data is not lost (leading zeroes later rectified, for example), then cast to floats at the evaluate stage | main.py 117-118, evaluator.py 22-25
Minimal use of global variables | Used only in helper functions when variables are not already passed through as parameters in the surrounding code - reset function for error handling in main file and update bounds function for recalculating variable results | main.py 25-42, constants.py 34-44
Good use of local variables | Used throughout code in procedures and functions, with external variables passed in where necessary - see expression tree for recursive function calls which pass variables through the entire call stack | All but see expression_tree.py for example
Modularisation of code | Code is broken down into 8 main files which all interact with each other as per the high-level overview diagrams in the design section | N/A
Well-designed user interface | Input and graph displays, with highlighting around selections and colour changes to make intuitive UI, minimalist look with only necessary detail shown | See input_display.py and graph_display.py
Good exception handling | Generally not needed due to severe restriction on user input by the physical hardware, but all exceptions are caught by the main loop, logged, and the program is then reset | main.py 216-225
Defensive programming | All bad inputs caught by above exception handling, and exceptions raised at a few different points for logging and easy traceback | parser.py 43-47, main.py 216-225, evaluator.py 22-25
Modules (collections of subroutines) - subroutines with common purpose grouped | All code modularised based on function - all functions called at evaluate stage in evaluator.py for example, and helpers.py contains useful tools | All but see evaluator.py, helpers.py for example
Cohesive modules (subroutines) - module code does just one thing | Each module handles a separate part of the program - input_display.py just handles the input display, parser.py just handles the parse stage, etc. | All but see input_display.py, parser.py for example
Loosely coupled module (subroutines) - module code interacts with other parts of the program through its interface only | Each module consists of functions which are called by other modules and return values as necessary, so other modules just pass parameters through | All
Modules (subroutines) with appropriate interfaces | Functions used in each module that can be called by other modules, see specifically expression tree for consistent interface with parse and render functions defined with polymorphism, allowing recursive calls | All but see expression_tree.py for example

Technical skills table

Below is a table outlining the different models and algorithms that I have used in the technical skills of the project:

Model | Algorithm | Example | Code reference
Appropriate choice of simple data types | Simple mathematical operations | Evaluator calculating basic operators using floats | evaluator.py 31-41
Single-dimensional arrays | Linear search | Cursor class move functions searching for parent expression index within grandparent to update position value | expression_tree.py 44-68
Simple control model | Range, list class extension | Helpers file containing self-defined basic tools that aid with control of graph plotting | helpers.py
File structure | Writing to file | Main writes to log file if any errors occur so that I can debug later with full traceback | main.py 216-225
Dictionary | Simple key-value lookup | Precedences are stored in dictionary so that precedence for each operator can be quickly looked up at parse stage | constants.py 3-9
Multi-dimensional array | Key matrix lookup and mapping | Key names stored in 2D array to be consistent with hardware wiring of buttons in key matrix | constants.py 88-95
Complex use of OOP | Dynamic object generation, rendering and parsing | Expression tree stores mathematical expressions as objects, which can be rendered and parsed recursively meaning it is highly robust. Polymorphism and inheritance is widely used. | expression_tree.py
Complex mathematical control model | Recursive algorithms | Recursive parsing and rendering algorithms throughout expression tree class inherited from parent and redefined as necessary | expression_tree.py
Complex control model | Recursive tokenisation algorithm | Expression class in expression tree has a larger implementation for evaluate function which tokenises the expression into a form that can be converted to postfix easily | expression_tree.py, 108-165
Stack and queue | Shunting-yard algorithm to convert infix to postfix | Convert function in parser file uses my own stripped-back implementation of Dijkstra’s shunting-yard algorithm | parser.py
Stack | Postfix evaluator | Evaluator creates lambda function by evaluating postfix expression using a stack | evaluator.py 7-43

Code appendix

Below is my full program code. There are two versions - the one that runs on the physical hardware, which is commented fully, and the one that runs on my laptop for testing purposes, which only has minor changes but still is useful to include for comparison. Any changes have been commented with explanations. I will also include the file button_matrix.py, which is a testing file to check that the hardware is working, and launcher.sh, a small file which runs on startup to boot the program.

Hardware versions

button_matrix_test.py

import RPi.GPIO as GPIO # type: ignore

import time

R1 = 2 # row and column pin numbers

R2 = 3

R3 = 4

R4 = 5

R5 = 6

R6 = 7

R7 = 8

R8 = 9

rows = [R1,R2,R3,R4,R5,R6,R7,R8]

C1 = 15

C2 = 16

C3 = 17

C4 = 18

C5 = 19

cols = [C1,C2,C3,C4,C5]

DEG = 11

RAD = 12

GPIO.cleanup()

GPIO.setwarnings(False)

GPIO.setmode(GPIO.BCM)

for r in rows: # sets up pins to be able to output signals

GPIO.setup(r, GPIO.OUT)

GPIO.output(r, GPIO.LOW)

for c in cols: # buttons in matrix so both row and col are activated for each button press

GPIO.setup(c, GPIO.IN, pull_up_down=GPIO.PUD_DOWN)

GPIO.setup(DEG, GPIO.IN, pull_up_down=GPIO.PUD_UP)

GPIO.setup(RAD, GPIO.IN, pull_up_down=GPIO.PUD_UP)

def detectRow(row, chars): # checks for button presses

for r in rows:

GPIO.output(r, GPIO.LOW)

GPIO.output(row, GPIO.HIGH)

time.sleep(0.01)

for c in range(len(cols)):

if GPIO.input(cols[c]) == GPIO.HIGH:

print(chars[c])

time.sleep(0.2)

GPIO.output(row, GPIO.LOW)

while True: # check whether all the buttons are working

detectRow(R1, ["up", "right", "down", "left", "shift"])

detectRow(R2, ["on", "zoom in", "zoom out", "integral", "x"])

detectRow(R3, ["fraction", "sqrt", "square", "power", "log"])

detectRow(R4, ["ln", "pi", "sin", "cos", "tan"])

detectRow(R5, ["(", ")", "AC", "DEL", "."])

detectRow(R6, ["+", "-", "*", "/", "EXE"])

detectRow(R7, [1,2,3,4,5])

detectRow(R8, [6,7,8,9,0])

print(GPIO.input(DEG) == GPIO.LOW)

constants.py

RIGHT_ASSOCIATIVE = ['NEG'] # right-associative operators for precedence in parsing

PRECEDENCES_LIST = [['NEG'],['/','*'],['+','-']] # list of precedence (BIDMAS) for parsing

PRECEDENCES = {None:100000}

def precedences_setup(): # converts precedences list into a dictionary

for index in range(len(PRECEDENCES_LIST)):

for operator in PRECEDENCES_LIST[index]:

PRECEDENCES[operator] = index

DEFAULT_FREQUENCY = 300

WIDTH = 800

HEIGHT = 480

WSCALE = 5/3 # multipliers from 480x320, specifically for hardware scaling - screen bigger than expected

HSCALE = 3/2

XMIN = -15 # screen bounds - variable

XMAX = 15

YMIN = -10

YMAX = 10

XDIFF = XMAX-XMIN # helpful calculation results for placement of objects on the screen

YDIFF = YMAX-YMIN

SCALEX = WIDTH/(XDIFF)

SCALEY = HEIGHT/(YDIFF)

X0 = -(XMIN*SCALEX)

Y0 = HEIGHT + (YMIN*SCALEY)

def update_bounds():

global XDIFF, YDIFF, SCALEX, SCALEY, X0, Y0

XDIFF = XMAX-XMIN

YDIFF = YMAX-YMIN

SCALEX = WIDTH/(XDIFF)

SCALEY = HEIGHT/(YDIFF)

X0 = -(XMIN*SCALEX)

Y0 = HEIGHT + (YMIN*SCALEY)

AXIS_LABEL_LENGTH = 3

ZOOM_SCALE_FACTOR = 2

BLACK = (0,0,0)

WHITE = (255,255,255)

BLUE = (0,120,215)

COLOURS = [(255,20,60), #red

(255,140,0), #orange

(34,139,34), #green

(0,0,255), #blue

(128,0,128), #purple

(255,0,255), #magenta

(160,82,45)] #brown

EDIT_TEXT = ['...','|'] # which to display in front of view window text (ellipsis if empty, cursor if selected)

E = 2.718281828459045235360287471352

PI = 3.141592653589793238462643383279

R1 = 2 # rows and columns for hardware pins

R2 = 3

R3 = 4

R4 = 5

R5 = 6

R6 = 7

R7 = 8

R8 = 9

ROWS = [R1,R2,R3,R4,R5,R6,R7,R8]

C1 = 15

C2 = 16

C3 = 17

C4 = 18

C5 = 19

COLS = [C1,C2,C3,C4,C5]

KEY_MATRIX = [["UP", "RIGHT", "DOWN", "LEFT", "SHIFT"], # integral is the only key not implemented

["ANGLE", "ZOOM_IN", "ZOOM_OUT", "integral", "x"], # matrix maps to rows and columns of hardware pins

["FRACTION", ["SQRT", "CBRT"], ["SQUARED", "CUBED"], ["EXPONENT", "RADICAL"], "LOG"], # sub array gives normal and shift key

[["LN", "LOG10"], ["PI", "E"], ["SIN", "CSC"], ["COS", "SEC"], ["TAN", "COT"]],

["(", ")", ["AC", "OFF"], "DEL", "."],

["+", "-", "*", "/", "EXE"],

['1','2','3','4','5'],

['6','7','8','9','0']]

BINARY_OPERATORS = ['RADICAL', 'FRACTION', 'LOG', 'EXPONENT'] # for deciding which object to create when a key is input

UNARY_OPERATORS = ['SQRT', 'CBRT', 'SIN', 'COS', 'TAN', 'CSC', 'SEC', 'COT', 'LN', 'LOG10', 'SQUARED', 'CUBED']

NUMBERS = '0123456789.'

SYMBOLS = "+-*/"

VARIABLES = ['x', 'PI', 'E']

ARROWS = ['LEFT', 'RIGHT', 'UP', 'DOWN']

ZOOM = ['ZOOM_IN', 'ZOOM_OUT']

TRIG = ['SIN', 'COS', 'TAN', 'CSC', 'SEC', 'COT']

BRACKETS = ['(', ')']

evaluator.py

import constants

import helpers

import math

def create_function(postfix): # creates lambda function from postfix representation of expression

stack = []

for token in postfix:

value, tag = token

if tag == "operand": # push all operands directly to the stack

if value == 'x':

stack.append(lambda x: x)

elif value == "PI":

stack.append(lambda x: math.pi)

elif value == "E":

stack.append(lambda x: math.e)

elif callable(value):

stack.append(value)

else:

try:

stack.append(lambda x, v=float(value): v)

except:

raise Exception("Invalid string for a number")

elif value == "NEG": # only unary function (others are handled by expression tree)

a = stack.pop()

stack.append(lambda x, a=a: -a(x))

else: # binary functions - pops top two values from stack to operate on and pushes result back to stack

b = stack.pop()

a = stack.pop()

if token[0] == '+':

stack.append(lambda x, a=a, b=b: a(x) + b(x))

elif token[0] == '-':

stack.append(lambda x, a=a, b=b: a(x) - b(x))

elif token[0] == '*':

stack.append(lambda x, a=a, b=b: a(x) * b(x))

elif token[0] == '/':

stack.append(lambda x, a=a, b=b: a(x) / b(x))

return stack[0]

def create_points(function, frequency=constants.DEFAULT_FREQUENCY): # creates list of (x, y) coordinates by evaluating the expression at evenly spaced x values

points = []

for x in helpers.frange(constants.XMIN*frequency, (constants.XMAX*frequency)+frequency, constants.XDIFF):

try:

if isinstance(function(x/frequency), complex):

points.append((x/frequency, None))

else:

points.append((x/frequency, function(x/frequency)))

except:

points.append((x/frequency, None))

return points

def evaluate(postfix, frequency=constants.DEFAULT_FREQUENCY): # packages both functions together

return create_points(create_function(postfix), frequency)

expression_tree.py

import pygame

pygame.init()

fonts = {30: pygame.font.Font('/home/lrsje/graphical-calculator/assets/STIXTwoMath-Regular.ttf', 30)}

def get_font(size): # dynamic font sizing for better resolution with scaling

size = int(size)

if fonts.get(size):

return fonts.get(size)

else:

fonts[size] = pygame.font.Font('/home/lrsje/graphical-calculator/assets/STIXTwoMath-Regular.ttf', size)

return fonts[size]

import math

import constants

import evaluator

import parser

class Object: # base object class, implements shell methods with polymorphism

def __init__(self):

self.parent = None

self.type = None

def render(self, scale=1, cursor=None):

pass

def evaluate(self, angle_mode="RAD"):

pass

class Cursor(Object): # represents cursor as an object referencing parent and position within parent

def __init__(self, parent):

super().__init__()

self.expression = parent # parent will always be an Expression

self.position = 0

self.character = "|"

def render(self, scale=1, cursor=None):

pixel_size = 30*scale

surface = get_font(pixel_size).render(self.character, True, constants.BLUE)

return pygame.transform.smoothscale(surface, tuple(i*scale for i in surface.get_size()))

def move_left(self): # handles cursor moving

if self.position > 0: # three possibilities - cursor moving within expression, cursor moving to other expression of a binary operator, or cursor moving up a level

self.position -= 1

elif self.expression == self.expression.parent.right: # all operators have right and left attributes so no error handling needed but unary operators implement as None

self.expression = self.expression.parent.left

self.position = 0

else:

try:

self.position = self.expression.parent.parent.index(self.expression.parent)

except:

self.position = 0 # literal edge case

self.expression = self.expression.parent.parent

def move_right(self):

if self.position < len(self.expression.objects):

self.position += 1

elif self.expression == self.expression.parent.left:

self.expression = self.expression.parent.right

self.position = 0

else:

try:

self.position = self.expression.parent.parent.index(self.expression.parent) + 1

except:

self.position = 0 # wrap cursor

self.expression = self.expression.parent.parent

class Expression(Object): # main class - list of objects

def __init__(self, parent=None):

super().__init__()

self.objects = []

self.parent = parent

self.left = None

self.right = None

self.type = "expression"

def update(self, arg, pos=-1): # to add or remove objects

if arg == "DEL":

if pos != 0:

self.objects.pop(pos-1)

else:

self.objects.insert(pos, arg)

arg.parent = self

def index(self, object):

return self.objects.index(object)

def render(self, scale=1, cursor=Cursor(None)): # recursively render each object within with scaling and cursor passed through

surface = pygame.Surface((0,0), pygame.SRCALPHA)

render_objects = self.objects.copy()

if cursor.expression == self:

render_objects.insert(cursor.position, cursor)

for object in render_objects:

rendered = object.render(scale=scale, cursor=cursor)

new_surface = pygame.Surface((surface.get_width() + rendered.get_width(), max(surface.get_height(), rendered.get_height())), pygame.SRCALPHA)

new_surface.blit(surface, (0,0))

new_surface.blit(rendered, (surface.get_width(),(new_surface.get_height()-rendered.get_height())/2))

surface = new_surface

if surface.get_size() == (0,0):

surface = pygame.Surface((15,30), pygame.SRCALPHA)

pygame.draw.rect(surface, constants.BLACK, pygame.Rect(0,0,15,30), 2)

return pygame.transform.smoothscale(surface, tuple(i*scale for i in surface.get_size()))

def evaluate(self, angle_mode="RAD"): # recursively create list of infix tokens, passing through angle mode for trig functions

tokens = []

last_type = "operator"

token = ""

def add_token(value, tag): # stores current token in list

nonlocal last_type # references last_type variable in parent function without making it global

if last_type == "operand" and value == "(": # handles implicit multiplication - 3 cases

tokens.append(("*", "operator"))

elif last_type == "operand" and value in constants.VARIABLES:

tokens.append(("*", "operator"))

elif last_type == "operand" and callable(value):

tokens.append(("*", "operator"))

tokens.append((value, tag))

if value == "(": # brackets treated like this for parsing stage with unary negation

last_type = "operator"

elif value == ")":

last_type = "operand"

else:

last_type = tag

for object in self.objects:

if object.type == "number":

token += object.value

elif object.type == "symbol" or object.type == "bracket":

if token != "":

add_token(token, "operand")

token = ""

if object.type == "symbol":

if object.value == "-" and last_type == "operator":

add_token("NEG", "operator")

else:

add_token(object.value, "operator")

elif object.type == "bracket":

add_token(object.value, "bracket")

elif object.type == "variable":

if token != "":

add_token(token, "operand")

token = ""

add_token(object.value, "operand")

else:

if token != "":

add_token(token, "operand")

token = ""

add_token(object.evaluate(angle_mode), "operand")

if token != "":

add_token(token, "operand")

postfix = parser.convert(tokens) # converts to postfix

return evaluator.create_function(postfix) # returns lambda function

class BinaryOperator(Object): # binary operators - left and right expressions implemented

def __init__(self):

super().__init__()

self.left = Expression(parent=self)

self.right = Expression(parent=self)

self.type = "binary_operator"

class Fraction(BinaryOperator):

def __init__(self):

super().__init__()

def render(self, scale=1, cursor=Cursor(None)):

numerator = self.left.render(scale=0.7, cursor=cursor)

denominator = self.right.render(scale=0.7, cursor=cursor)

width = max(numerator.get_width(), denominator.get_width())+5

surface = pygame.Surface((width, numerator.get_height()+5+denominator.get_height()), pygame.SRCALPHA)

pygame.draw.line(surface, constants.BLACK, (0, surface.get_height()/2), (surface.get_width(), surface.get_height()/2))

surface.blit(numerator, (2.5+((width-numerator.get_width())/2), 0)) # centered

surface.blit(denominator, (2.5+((width-denominator.get_width())/2), 2.5+surface.get_height()/2))

return pygame.transform.smoothscale(surface, tuple(i*scale for i in surface.get_size()))

def evaluate(self, angle_mode="RAD"):

return lambda x, a=self.left.evaluate(angle_mode), b=self.right.evaluate(angle_mode): a(x) / b(x)

class Radical(BinaryOperator):

def __init__(self):

super().__init__()

def render(self, scale=1, cursor=Cursor(None)):

operator = self.left.render(scale=0.7, cursor=cursor)

operand = self.right.render(scale=0.95, cursor=cursor)

surface = pygame.Surface((operand.get_width()+10+operator.get_width(), operand.get_height()+10), pygame.SRCALPHA)

pygame.draw.lines(surface, constants.BLACK, False, [(operator.get_width()-5, surface.get_height()-10), (operator.get_width(), surface.get_height()), (operator.get_width()+5, 5), (surface.get_width(), 5)], width=2)

surface.blit(operand, (operator.get_width()+5, 10))

surface.blit(operator, (0, 0))

return pygame.transform.smoothscale(surface, tuple(i*scale for i in surface.get_size()))

def evaluate(self, angle_mode="RAD"):

return lambda x, a=self.left.evaluate(angle_mode), b=self.right.evaluate(angle_mode): math.copysign(abs(b(x)) ** (1/a(x)), b(x)) # problem with principal roots of negative numbers being complex - for non-integer powers, it takes the principal root of the positive which is always real, then negates it (e.g. cube root of 27 is 3, so we want -3 for cube root of -27, which is represented as -(27**(1/3)) otherwise we get a complex result

class Log(BinaryOperator):

def __init__(self):

super().__init__()

def render(self, scale=1, cursor=Cursor(None)):

base = self.left.render(scale=0.7, cursor=cursor)

base = pygame.transform.smoothscale(base, tuple(i*scale for i in base.get_size()))

operand = self.right.render(cursor=cursor)

operand = pygame.transform.smoothscale(operand, tuple(i*scale for i in operand.get_size()))

pixel_size = 30*scale

font = get_font(pixel_size)

text1 = font.render("log", True, constants.BLACK)

text2 = font.render("(", True, constants.BLACK)

text3 = font.render(")", True, constants.BLACK)

surface = pygame.Surface((text1.get_width()+base.get_width()+text2.get_width()+operand.get_width()+text3.get_width()+5, text1.get_height()+base.get_height()), pygame.SRCALPHA)

surface.blit(text1, (0, 0))

surface.blit(base, (text1.get_width(), text1.get_height()))

surface.blit(text2, (text1.get_width()+base.get_width(), 0))

surface.blit(operand, (text1.get_width()+base.get_width()+text2.get_width()+2.5, 0))

surface.blit(text3, (text1.get_width()+base.get_width()+text2.get_width()+operand.get_width()+5, 0))

return surface

def evaluate(self, angle_mode="RAD"):

return lambda x, a=self.left.evaluate(angle_mode), b=self.right.evaluate(angle_mode): math.log(b(x), a(x))

class Exponent(BinaryOperator):

def __init__(self):

super().__init__()

def render(self, scale=1, cursor=Cursor(None)):

operand = self.left.render(cursor=cursor)

operator = self.right.render(scale=0.7, cursor=cursor)

surface = pygame.Surface((operand.get_width()+operator.get_width(), operand.get_height()), pygame.SRCALPHA)

surface.blit(operand, (0, 2.5))

surface.blit(operator, (operand.get_width(), 0))

return pygame.transform.smoothscale(surface, tuple(i*scale for i in surface.get_size()))

def evaluate(self, angle_mode="RAD"):

return lambda x, a=self.left.evaluate(angle_mode), b=self.right.evaluate(angle_mode): a(x)**b(x)

class UnaryOperator(Object): # unary operators - left and right operators implemented as None

def __init__(self):

super().__init__()

self.operand = Expression(parent=self)

self.left = None

self.right = None

self.type = "unary_operator"

class SquareRoot(UnaryOperator):

def __init__(self):

super().__init__()

def render(self, scale=1, cursor=Cursor(None)):

operand = self.operand.render(scale=0.95, cursor=cursor)

surface = pygame.Surface((operand.get_width()+15, operand.get_height()+5), pygame.SRCALPHA)

pygame.draw.lines(surface, constants.BLACK, False, [(0, surface.get_height()-10), (5, surface.get_height()), (10, 0), (surface.get_width(), 0)], width=2)

surface.blit(operand, (10, 5))

return pygame.transform.smoothscale(surface, tuple(i*scale for i in surface.get_size()))

def evaluate(self, angle_mode="RAD"):

return lambda x, a=self.operand.evaluate(angle_mode): math.sqrt(a(x))

class CubeRoot(UnaryOperator):

def __init__(self):

super().__init__()

def render(self, scale=1, cursor=Cursor(None)):

operator = Number(3).render(scale=0.7, cursor=cursor)

operand = self.operand.render(scale=0.95, cursor=cursor)

surface = pygame.Surface((operand.get_width()+10+operator.get_width(), operand.get_height()+10), pygame.SRCALPHA)

pygame.draw.lines(surface, constants.BLACK, False, [(operator.get_width()-5, surface.get_height()-10), (operator.get_width(), surface.get_height()), (operator.get_width()+5, 5), (surface.get_width(), 5)], width=2)

surface.blit(operand, (operator.get_width()+5, 10))

surface.blit(operator, (0, 0))

return pygame.transform.smoothscale(surface, tuple(i*scale for i in surface.get_size()))

def evaluate(self, angle_mode="RAD"):

return lambda x, a=self.operand.evaluate(angle_mode): math.copysign(abs(a(x)) ** (1/3), a(x))

class Trig(UnaryOperator):

def __init__(self, function):

super().__init__()

self.type = function

def render(self, scale=1, cursor=Cursor(None)):

operand = self.operand.render(cursor=cursor)

operand = pygame.transform.smoothscale(operand, tuple(i*scale for i in operand.get_size()))

pixel_size = 30*scale

font = get_font(pixel_size)

text1 = font.render(f"{self.type.lower()}(", True, constants.BLACK)

text2 = font.render(")", True, constants.BLACK)

surface = pygame.Surface((text1.get_width()+5+text2.get_width()+operand.get_width(), max(operand.get_height(), text1.get_height())), pygame.SRCALPHA)

surface.blit(text1, (0, 0))

surface.blit(operand, (text1.get_width()+2.5, 0))

surface.blit(text2, (text1.get_width()+operand.get_width()+5, 0))

return surface

def evaluate(self, angle_mode="RAD"): # only evaluate call that uses angle mode but it still needs to be passed through the call stack

if angle_mode == "RAD":

if self.type == "SIN":

return lambda x, a=self.operand.evaluate(angle_mode): math.sin(a(x))

elif self.type == "COS":

return lambda x, a=self.operand.evaluate(angle_mode): math.cos(a(x))

elif self.type == "TAN":

return lambda x, a=self.operand.evaluate(angle_mode): math.tan(a(x))

elif self.type == "CSC":

return lambda x, a=self.operand.evaluate(angle_mode): 1/math.sin(a(x))

elif self.type == "SEC":

return lambda x, a=self.operand.evaluate(angle_mode): 1/math.cos(a(x))

elif self.type == "COT":

return lambda x, a=self.operand.evaluate(angle_mode): 1/math.tan(a(x))

elif angle_mode == "DEG":

if self.type == "SIN":

return lambda x, a=self.operand.evaluate(angle_mode): math.sin(math.radians(a(x)))

elif self.type == "COS":

return lambda x, a=self.operand.evaluate(angle_mode): math.cos(math.radians(a(x)))

elif self.type == "TAN":

return lambda x, a=self.operand.evaluate(angle_mode): math.tan(math.radians(a(x)))

elif self.type == "CSC":

return lambda x, a=self.operand.evaluate(angle_mode): 1/math.sin(math.radians(a(x)))

elif self.type == "SEC":

return lambda x, a=self.operand.evaluate(angle_mode): 1/math.cos(math.radians(a(x)))

elif self.type == "COT":

return lambda x, a=self.operand.evaluate(angle_mode): 1/math.tan(math.radians(a(x)))

class Ln(UnaryOperator):

def __init__(self):

super().__init__()

def render(self, scale=1, cursor=Cursor(None)):

operand = self.operand.render(cursor=cursor)

operand = pygame.transform.smoothscale(operand, tuple(i*scale for i in operand.get_size()))

pixel_size = 30*scale

font = get_font(pixel_size)

text1 = font.render("ln(", True, constants.BLACK)

text2 = font.render(")", True, constants.BLACK)

surface = pygame.Surface((text1.get_width()+5+text2.get_width()+operand.get_width(), max(operand.get_height(), text1.get_height())), pygame.SRCALPHA)

surface.blit(text1, (0, 0))

surface.blit(operand, (text1.get_width()+2.5, 0))

surface.blit(text2, (text1.get_width()+operand.get_width()+5, 0))

return surface

def evaluate(self, angle_mode="RAD"):

return lambda x, a=self.operand.evaluate(angle_mode): math.log(a(x))

class Log10(UnaryOperator):

def __init__(self):

super().__init__()

def render(self, scale=1, cursor=Cursor(None)):

operand = self.operand.render(cursor=cursor)

operand = pygame.transform.smoothscale(operand, tuple(i*scale for i in operand.get_size()))

pixel_size = 30*scale

font = get_font(pixel_size)

text1 = font.render("log(", True, constants.BLACK)

text2 = font.render(")", True, constants.BLACK)

surface = pygame.Surface((text1.get_width()+5+text2.get_width()+operand.get_width(), max(operand.get_height(), text1.get_height())), pygame.SRCALPHA)

surface.blit(text1, (0, 0))

surface.blit(operand, (text1.get_width()+2.5, 0))

surface.blit(text2, (text1.get_width()+operand.get_width()+5, 0))

return surface

def evaluate(self, angle_mode="RAD"):

return lambda x, a=self.operand.evaluate(angle_mode): math.log10(a(x))

class Squared(UnaryOperator):

def __init__(self):

super().__init__()

def render(self, scale=1, cursor=Cursor(None)):

operand = self.operand.render(cursor=cursor)

operator = Number(2).render(scale=0.7, cursor=cursor)

surface = pygame.Surface((operand.get_width()+operator.get_width(), operand.get_height()), pygame.SRCALPHA)

surface.blit(operand, (0, 2.5)) # slight offset

surface.blit(operator, (operand.get_width(), 0))

return pygame.transform.smoothscale(surface, tuple(i*scale for i in surface.get_size()))

def evaluate(self, angle_mode="RAD"):

return lambda x, a=self.operand.evaluate(angle_mode): a(x) ** 2

class Cubed(UnaryOperator):

def __init__(self):

super().__init__()

def render(self, scale=1, cursor=Cursor(None)):

operand = self.operand.render(cursor=cursor)

operator = Number(3).render(scale=0.7, cursor=cursor)

surface = pygame.Surface((operand.get_width()+operator.get_width(), operand.get_height()), pygame.SRCALPHA)

surface.blit(operand, (0, 2.5))

surface.blit(operator, (operand.get_width(), 0))

return pygame.transform.smoothscale(surface, tuple(i*scale for i in surface.get_size()))

def evaluate(self, angle_mode="RAD"):

return lambda x, a=self.operand.evaluate(angle_mode): a(x) ** 3

class Operand(Object): # not just operands, also includes single character operators

def __init__(self, value):

super().__init__()

self.value = str(value)

self.rendered_value = self.value

def render(self, scale=1, cursor=Cursor(None)): # cursor default arg so that it can be passed through all the render operations without distinguishing type

pixel_size = 30*scale # dynamic font size instead of smoothscale after gives better resolution

font = get_font(pixel_size)

surface = font.render(self.rendered_value, True, constants.BLACK)

return surface

class Number(Operand):

def __init__(self, value):

super().__init__(value)

self.type = "number"

class Symbol(Operand):

def __init__(self, value):

super().__init__(value)

self.type = "symbol"

if self.value == "*": # rendered value is what is shown on the screen, but the value in the parser is kept as the actual value

self.rendered_value = "x"

elif self.value == "/":

self.rendered_value = "÷"

class Bracket(Operand):

def __init__(self, value):

super().__init__(value)

self.type = "bracket"

class Variable(Operand):

def __init__(self, value):

super().__init__(value)

self.type = "variable"

if self.value == "x":

self.rendered_value = "x"

class Constant(Operand):

def __init__(self, value):

super().__init__(value)

self.type = "variable" # treated as variables by evaluator

if self.value == "PI":

self.rendered_value = "π"

elif self.value == "E":

self.rendered_value = "e"

graph_display.py

import pygame

import constants

label_font = pygame.font.Font('/home/lrsje/graphical-calculator/assets/universcondensed_medium.ttf', constants.AXIS_LABEL_LENGTH*3)

def update_screen(screen):

screen.fill(constants.WHITE)

pygame.draw.line(screen, constants.BLACK, (0,constants.Y0), (constants.WIDTH,constants.Y0))

pygame.draw.line(screen, constants.BLACK, (constants.X0,0), (constants.X0,constants.HEIGHT)) # draws axes

pygame.draw.line(screen, constants.BLACK, (0,constants.Y0-constants.AXIS_LABEL_LENGTH), (0,constants.Y0+constants.AXIS_LABEL_LENGTH)) # draws axis label ticks

pygame.draw.line(screen, constants.BLACK, (constants.WIDTH-1,constants.Y0-constants.AXIS_LABEL_LENGTH), (constants.WIDTH-1,constants.Y0+constants.AXIS_LABEL_LENGTH))

pygame.draw.line(screen, constants.BLACK, (constants.X0-constants.AXIS_LABEL_LENGTH,0), (constants.X0+constants.AXIS_LABEL_LENGTH,0))

pygame.draw.line(screen, constants.BLACK, (constants.X0-constants.AXIS_LABEL_LENGTH,constants.HEIGHT-1), (constants.X0+constants.AXIS_LABEL_LENGTH,constants.HEIGHT-1))

screen.blit(label_font.render(str(constants.XMIN), False, constants.BLACK), (constants.AXIS_LABEL_LENGTH,constants.Y0+constants.AXIS_LABEL_LENGTH)) # draws axis label numbers

screen.blit(label_font.render(str(constants.XMAX), False, constants.BLACK), (constants.WIDTH-label_font.size(str(constants.XMAX))[0]-constants.AXIS_LABEL_LENGTH,constants.Y0+constants.AXIS_LABEL_LENGTH))

screen.blit(label_font.render(str(constants.YMIN), False, constants.BLACK), (constants.X0+constants.AXIS_LABEL_LENGTH,constants.HEIGHT-label_font.size(str(constants.YMIN))[1]-constants.AXIS_LABEL_LENGTH))

screen.blit(label_font.render(str(constants.YMAX), False, constants.BLACK), (constants.X0+constants.AXIS_LABEL_LENGTH,constants.AXIS_LABEL_LENGTH))

def plot_graph(screen, points, colour): # plots points on screen and interpolates between them

previous_point = ()

for point in points:

if point[1] == None:

previous_point = None

else: # maths coordinates vs computer coordinates - (0,0) is top left for the computer and y direction is reversed, but origin can be anywhere on the screen or off due to the moving and view window so the graph needs to be transformed appropriately

current_point = ((point[0]*constants.SCALEX)-(constants.XMIN*constants.SCALEX),

constants.HEIGHT - ((point[1]*constants.SCALEY)-(constants.YMIN*constants.SCALEY)))

if previous_point:

pygame.draw.line(screen, colour, previous_point, current_point)

previous_point = current_point

def move(direction): # allows panning around graph, points updated and re-rendered according to new bounds each time

if direction == 'UP':

constants.YMAX += (constants.YDIFF/5)

constants.YMIN += (constants.YDIFF/5)

elif direction == 'DOWN':

constants.YMAX -= (constants.YDIFF/5)

constants.YMIN -= (constants.YDIFF/5)

elif direction == 'LEFT':

constants.XMAX -= (constants.XDIFF/5)

constants.XMIN -= (constants.XDIFF/5)

elif direction == 'RIGHT':

constants.XMAX += (constants.XDIFF/5)

constants.XMIN += (constants.XDIFF/5)

constants.update_bounds()

def zoom(direction): # allows zooming in and out of graph, centered on the center of the screen, points updated and re-rendered according to new bounds each time

if direction == 'IN' and constants.XMAX > 0.001: # bounds so that calculations do not get too intensive on CPU (for zooming out, eventually we would reach significant floating point errors so the graph would not render accurately anyway)

constants.XMAX /= constants.ZOOM_SCALE_FACTOR

constants.XMIN /= constants.ZOOM_SCALE_FACTOR

constants.YMAX /= constants.ZOOM_SCALE_FACTOR

constants.YMIN /= constants.ZOOM_SCALE_FACTOR

elif direction == 'OUT' and constants.XMAX < 1000000:

constants.XMAX *= constants.ZOOM_SCALE_FACTOR

constants.XMIN *= constants.ZOOM_SCALE_FACTOR

constants.YMAX *= constants.ZOOM_SCALE_FACTOR

constants.YMIN *= constants.ZOOM_SCALE_FACTOR

constants.update_bounds()

helpers.py

def frange(start, stop, step): # implements range for floating point numbers

res, n = start, 1

while res < stop:

yield res

res = start + n * step

n += 1

class SafeList(list): # extension of list data structure with default value for error handling

def get(self, index, default=None):

try:

return self[index]

except IndexError:

return default

input_display.py

import pygame

import constants

font = pygame.font.Font('/home/lrsje/graphical-calculator/assets/STIXTwoMath-Regular.ttf', 30)

small_font = pygame.font.Font('/home/lrsje/graphical-calculator/assets/STIXTwoMath-Regular.ttf', 10)

def update_screen(screen, functions, selected, view_window, cursors, cursor_active, shift_mode, angle_mode):

screen.fill(constants.WHITE) # render view window input fields

pygame.draw.rect(screen, constants.BLACK, pygame.Rect(0,0,constants.WIDTH, 40),2)

colour = constants.BLACK

screen.blit(font.render('x:', False, constants.BLACK), (5*constants.WSCALE,5))

if selected == 7:

colour = constants.BLUE

pygame.draw.rect(screen, colour, pygame.Rect(35*constants.WSCALE,5,80,30),2)

screen.blit(font.render(view_window[0], False, constants.BLACK), (40*constants.WSCALE,6))

colour = constants.BLACK

screen.blit(font.render('-', False, constants.BLACK), (35*constants.WSCALE+90,5))

if selected == 8:

colour = constants.BLUE

pygame.draw.rect(screen, colour, pygame.Rect(35*constants.WSCALE+110,5,80,30),2)

screen.blit(font.render(view_window[1], False, constants.BLACK), (35*constants.WSCALE+115,6))

colour = constants.BLACK

screen.blit(font.render('y:', False, constants.BLACK), (245*constants.WSCALE,5))

if selected == 9:

colour = constants.BLUE

pygame.draw.rect(screen, colour, pygame.Rect(275*constants.WSCALE,5,80,30),2)

screen.blit(font.render(view_window[2], False, constants.BLACK), (280*constants.WSCALE,6))

colour = constants.BLACK

screen.blit(font.render('-', False, constants.BLACK), (275*constants.WSCALE+90,5))

if selected == 10:

colour = constants.BLUE

pygame.draw.rect(screen, colour, pygame.Rect(275*constants.WSCALE+110,5,80,30),2)

screen.blit(font.render(view_window[3], False, constants.BLACK), (275*constants.WSCALE+115,6))

for line in range(7): # render each line

screen.blit(font.render(f'{line+1}: y =', False, constants.BLACK), (35*constants.WSCALE,45*constants.HSCALE+line*40*constants.HSCALE))

if selected == line:

screen.blit(font.render('>', False, constants.BLUE), (5*constants.WSCALE,45*constants.HSCALE+line*40*constants.HSCALE))

if cursor_active:

surface = functions[line].render(cursor=cursors[selected]) # calls render method in expression tree

else:

surface = functions[line].render()

surface = pygame.transform.smoothscale(surface, (surface.get_width()*constants.WSCALE, surface.get_height()*constants.HSCALE))

screen.blit(surface, (35*constants.WSCALE+90,45*constants.HSCALE+line*40*constants.HSCALE))

elif not functions[line].objects:

screen.blit(font.render('...', False, constants.BLACK), (35*constants.WSCALE+90,45*constants.HSCALE+line*40*constants.HSCALE))

else:

surface = functions[line].render()

surface = pygame.transform.smoothscale(surface, (surface.get_width()*constants.WSCALE, surface.get_height()*constants.HSCALE))

screen.blit(surface, (35*constants.WSCALE+90,45*constants.HSCALE+line*40*constants.HSCALE))

pygame.draw.rect(screen, constants.COLOURS[line], pygame.Rect(440*constants.WSCALE,55*constants.HSCALE+line*40*constants.HSCALE,30,15)) # colour indicators for each graph line

if shift_mode: # render indicators for shift and angle modes

screen.blit(small_font.render("SHIFT", False, constants.BLACK), (450*constants.WSCALE, 5))

screen.blit(small_font.render(angle_mode, False, constants.BLACK), (420*constants.WSCALE, 5))

def move(direction, functions, cursors, selected, cursor_active, view_window): # move within input display screen

if direction == 'UP':

if selected == 0:

selected = 7

view_window[selected-7] += '|'

cursor_active = True

elif 0 < selected < 7:

selected -= 1

cursors[selected].expression = functions[selected]

cursors[selected].position = len(functions[selected].objects)

cursor_active = True

elif direction == 'DOWN':

if selected < 7:

selected += 1

cursors[selected].expression = functions[selected]

cursors[selected].position = len(functions[selected].objects)

cursor_active = True

elif selected >= 7:

selected = 0

cursors[selected].expression = functions[selected]

cursors[selected].position = len(functions[selected].objects)

cursor_active = True

elif direction == 'LEFT':

if selected > 7:

selected -= 1

view_window[selected-7] += '|'

cursor_active = True

elif direction == 'RIGHT':

if 7 <= selected < 10:

selected += 1

view_window[selected-7] += '|'

cursor_active = True

return selected, cursor_active, view_window

launcher.sh

cd / # move to directory and run file on boot

cd home/lrsje/graphical-calculator

sudo python main.py

unclutter -idle 0.01

cd /

main.py

import pygame

import RPi.GPIO as GPIO # type: ignore

import time

import os

import traceback

import constants

import evaluator

import expression_tree

constants.precedences_setup()

GPIO.cleanup() # set up button matrix pins

GPIO.setwarnings(False)

GPIO.setmode(GPIO.BCM)

for r in constants.ROWS:

GPIO.setup(r, GPIO.OUT)

GPIO.output(r, GPIO.LOW)

for c in constants.COLS:

GPIO.setup(c, GPIO.IN, pull_up_down=GPIO.PUD_DOWN)

def reset(): # handles exceptions on hardware so it doesnt just shut down

global display_mode, functions, cursors, view_window, selected, cursor_active, shift_mode, angle_mode

display_mode = "input"

functions = [expression_tree.Expression() for _ in range(7)]

for function in functions:

function.parent = function

cursors = [expression_tree.Cursor(functions[_]) for _ in range(7)]

view_window = [str(i) for i in [constants.XMIN, constants.XMAX, constants.YMIN, constants.YMAX]]

selected = 0

cursor_active = True

shift_mode = False

angle_mode = "RAD"

for r in constants.ROWS:

GPIO.output(r, GPIO.LOW)

reset()

pygame.init()

screen = pygame.display.set_mode((constants.WIDTH, constants.HEIGHT), pygame.FULLSCREEN) # fullscreen for hardware

running = True

clock = pygame.time.Clock() # reduces stress on hardware by capping framerate at 60 FPS

import input_display

import graph_display

def render_graphs(graphs): # evaluates each graph in the list and plots on axes

for index in range(len(graphs)):

graph = graphs[index]

if graph.objects:

evaluated = graph.evaluate(angle_mode)

points = evaluator.create_points(evaluated)

graph_display.plot_graph(screen, points, constants.COLOURS[index])

input_display.update_screen(screen, functions, selected, view_window, cursors, cursor_active, shift_mode, angle_mode)

pygame.display.update()

while running:

try: # handle exceptions

for event in pygame.event.get():

if event.type == pygame.QUIT or (event.type == pygame.KEYDOWN and event.key == pygame.K_TAB): # keyboard override for testing

running = False

pygame.quit()

for r in range(len(constants.ROWS)): # detect button presses

GPIO.output(constants.ROWS[r], GPIO.HIGH)

for c in range(len(constants.COLS)):

if GPIO.input(constants.COLS[c]) == GPIO.HIGH:

key = constants.KEY_MATRIX[r][c]

if type(key) == list:

key = key[shift_mode]

if key != "SHIFT":

shift_mode = False

if display_mode == "input": # handle inputs - creates objects based on inputted key

if cursor_active == True:

if selected < 7:

if key in constants.BINARY_OPERATORS:

if key == "RADICAL":

operator = expression_tree.Radical()

elif key == "FRACTION":

operator = expression_tree.Fraction()

elif key == "LOG":

operator = expression_tree.Log()

elif key == "EXPONENT":

operator = expression_tree.Exponent()

cursors[selected].expression.update(operator, cursors[selected].position)

cursors[selected].expression = operator.left

cursors[selected].position = 0

elif key in constants.UNARY_OPERATORS:

if key == "SQRT":

operator = expression_tree.SquareRoot()

elif key == "CBRT":

operator = expression_tree.CubeRoot()

elif key in constants.TRIG:

operator = expression_tree.Trig(key)

elif key == "LN":

operator = expression_tree.Ln()

elif key == "LOG10":

operator = expression_tree.Log10()

elif key == "SQUARED":

operator = expression_tree.Squared()

elif key == "CUBED":

operator = expression_tree.Cubed()

cursors[selected].expression.update(operator, cursors[selected].position)

cursors[selected].expression = operator.operand

cursors[selected].position = 0

elif key in constants.NUMBERS:

cursors[selected].expression.update(expression_tree.Number(key), cursors[selected].position)

cursors[selected].position += 1

elif key in constants.SYMBOLS:

cursors[selected].expression.update(expression_tree.Symbol(key), cursors[selected].position)

cursors[selected].position += 1

elif key in constants.VARIABLES:

if key == "x":

cursors[selected].expression.update(expression_tree.Variable(key), cursors[selected].position)

else:

cursors[selected].expression.update(expression_tree.Constant(key), cursors[selected].position)

cursors[selected].position += 1

elif key in constants.BRACKETS:

cursors[selected].expression.update(expression_tree.Bracket(key), cursors[selected].position)

cursors[selected].position += 1

elif key in constants.ARROWS:

if key == "LEFT":

cursors[selected].move_left()

elif key == "RIGHT":

cursors[selected].move_right()

elif key == "DEL":

if cursors[selected].position > 0:

cursors[selected].expression.update("DEL", cursors[selected].position)

cursors[selected].position -= 1

elif key == "EXE":

cursor_active = False

elif key == "AC":

function = expression_tree.Expression()

function.parent = function

functions[selected] = function

cursors[selected] = expression_tree.Cursor(function)

else: # handles input for view window

if key in constants.NUMBERS:

view_window[selected-7] = view_window[selected-7].replace('|',key+'|')

elif key == "DEL":

view_window[selected-7] = view_window[selected-7][0:-2]+'|'

elif key == "EXE":

view_window[selected-7] = view_window[selected-7][0:-1]

constants.XMIN, constants.XMAX, constants.YMIN, constants.YMAX = [float(i) for i in view_window]

constants.update_bounds()

cursor_active = False

elif key == "AC":

view_window[selected-7] = '|'

elif cursor_active == False: # move within input display or switch to graph mode

if key in constants.ARROWS:

selected, cursor_active, view_window = input_display.move(key, functions, cursors, selected, cursor_active, view_window)

elif key == 'EXE':

display_mode = "graph"

if key == 'SHIFT':

shift_mode = not shift_mode

if key == "ANGLE":

if angle_mode == "RAD":

angle_mode = "DEG"

else:

angle_mode = "RAD"

if display_mode == 'input': # updates screen

input_display.update_screen(screen, functions, selected, view_window, cursors, cursor_active, shift_mode, angle_mode)

pygame.display.update()

elif display_mode == 'graph':

graph_display.update_screen(screen)

render_graphs(functions)

pygame.display.update()

elif display_mode == "graph": # handles pan, zoom and return to input mode when in graph mode

if key == 'EXE':

display_mode = 'input'

input_display.update_screen(screen, functions, selected, view_window, cursors, cursor_active, shift_mode, angle_mode)

pygame.display.update()

elif key in constants.ARROWS or key in constants.ZOOM:

if key in constants.ARROWS:

graph_display.move(key)

elif key == "ZOOM_IN":

graph_display.zoom('IN')

elif key == "ZOOM_OUT":

graph_display.zoom('OUT')

graph_display.update_screen(screen)

render_graphs(functions)

pygame.display.update()

if key == "OFF": # end program for hardware and shut down raspberry pi

os.system("sudo shutdown -h now")

GPIO.cleanup()

running = False

pygame.quit()

time.sleep(0.2) # so key matrix doesn't put heavy stress on CPU

GPIO.output(constants.ROWS[r], GPIO.LOW)

except Exception as e: # handle exceptions with logfile as can't see terminal output on hardware

error_text = traceback.format_exc()

print(error_text)

with open("logs.txt", "a") as logfile:

logfile.write(error_text)

logfile.write("\n")

logfile.close()

reset()

input_display.update_screen(screen, functions, selected, view_window, cursors, cursor_active, shift_mode, angle_mode)

pygame.display.update()

clock.tick(60)

parser.py

import constants

import helpers

def convert(processed_infix): # converts tokenized infix expression to postfix (RPN) so it can be evaluated using a stack-based system

out_queue = helpers.SafeList()

operator_stack = helpers.SafeList()

def send(): # uses shunting yard algorithm

out_queue.append(operator_stack.pop())

for token in processed_infix:

value, tag = token

if tag == "operand":

out_queue.append(token)

elif value == "(":

operator_stack.append(token)

elif value == ")":

while operator_stack.get(-1)[0] != "(":

send()

operator_stack.pop()

else:

while True:

top = operator_stack.get(-1)

if top is None:

break

elif top[0] == "(":

break

top_prec = constants.PRECEDENCES.get(top[0], 0)

cur_prec = constants.PRECEDENCES.get(value, 0)

if (top_prec < cur_prec) or (top_prec == cur_prec and value not in constants.RIGHT_ASSOCIATIVE):

send()

else:

break

operator_stack.append(token)

while len(operator_stack) != 0:

if operator_stack[-1][0] == '(':

raise Exception("Mismatched parentheses") # logged and program reset upon erroring - useful for testing

else:

send()

return out_queue

Laptop versions

constants.py

from collections import defaultdict

RIGHT_ASSOCIATIVE = ['NEG']

PRECEDENCES_LIST = [['NEG'],['/','*'],['+','-']]

PRECEDENCES = {None:100000}

def precedences_setup():

for index in range(len(PRECEDENCES_LIST)):

for operator in PRECEDENCES_LIST[index]:

PRECEDENCES[operator] = index

DEFAULT_FREQUENCY = 300

WIDTH = 480

HEIGHT = 320

XMIN = -15

XMAX = 15

YMIN = -10

YMAX = 10

XDIFF = XMAX-XMIN

YDIFF = YMAX-YMIN

SCALEX = WIDTH/(XDIFF)

SCALEY = HEIGHT/(YDIFF)

X0 = -(XMIN*SCALEX)

Y0 = HEIGHT + (YMIN*SCALEY)

def update_bounds():

global XDIFF, YDIFF, SCALEX, SCALEY, X0, Y0

XDIFF = XMAX-XMIN

YDIFF = YMAX-YMIN

SCALEX = WIDTH/(XDIFF)

SCALEY = HEIGHT/(YDIFF)

X0 = -(XMIN*SCALEX)

Y0 = HEIGHT + (YMIN*SCALEY)

AXIS_LABEL_LENGTH = 3

ZOOM_SCALE_FACTOR = 2

BLACK = (0,0,0)

WHITE = (255,255,255)

BLUE = (0,120,215)

COLOURS = [(255,20,60), #red

(255,140,0), #orange

(34,139,34), #green

(0,0,255), #blue

(128,0,128), #purple

(255,0,255), #magenta

(160,82,45)] #brown

EDIT_TEXT = ['...','|']

E = 2.718281828459045235360287471352

PI = 3.141592653589793238462643383279
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

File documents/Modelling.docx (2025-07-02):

Modelling

To create a graphical calculator, the focus will be the software. I will be coding it in Python, relying very little on external libraries (such as NumPy, SciPy etc.). The project needs three general algorithms, as well as some more specific ones for computing the different mathematical functions. The main algorithms needed are explained below.

The aim of the project is to be able to plot graphs of explicit (defined in terms of a single variable):

- Polynomials
- Radicals
- Exponentials
- Reciprocals
- Logarithmic graphs
- Trigonometric graphs (sin, cos, tan and reciprocals)
- Parametric graphs
- Differential equations
- Indefinite integrals
- Combinations of the above

Firstly, I need to create a parser.

The parser needs to be able to take an input of a human-readable function (with some constraints - all functions will be explicitly defined, that is, in terms of a single variable, and correct mathematical syntax is required)

The algorithm I will use will convert the entered function from infix to postfix notation, having pre-processed some operators and implicit multiplication using regular expressions. Infix notation is the regular notation in which calculations are generally written by humans, following the rules of BIDMAS to determine order of operation. [1]

Postfix notation, which is also referred to as Reverse Polish notation, is where operators follow the operands, rather than when they precede the operands as in infix notation. Due to this, it allows the expression to be evaluated left to right, rather than having to consider the order of operations. This is done using a stack, which is useful for processing expressions automatically. It also removes the need for parentheses. [2]

To convert from infix to postfix notation, I will use an algorithm developed by Dijkstra, known as the shunting yard algorithm. The way this algorithm works is that the expression is iterated through from left to right. There is an output queue and an operator stack, where tokens in the expression are added to when encountered, following set rules. [3]

Associativity is also a factor in the algorithm. Left-associative operators, such as the multiply operator, are where operations can be grouped from left to right. This is in contrast with right-associative operators, such as exponentiation, where operations are grouped from right to left.

Whenever a number is encountered, it is pushed to an output queue. If a function, such as the sine function, is encountered, it is pushed to the operator stack. If an operator (x) is encountered, the algorithm iterates through each operator currently in the stack (y). If y is not a left parenthesis and has greater precedence than x or has the same precedence with x being left-associative, then y is popped from the stack to the output. When y is not popped, the iteration stops, and x is then pushed onto the stack.

There are more detailed rules based on functions that take multiple inputs, and parentheses that comprise functions, but these are not important to the base parsing function that I will implement. Once there are no tokens left to iterate through, all the operators on the stack are popped to the output queue.

Below is a graphical illustration of the shunting yard algorithm for basic operators: [4]

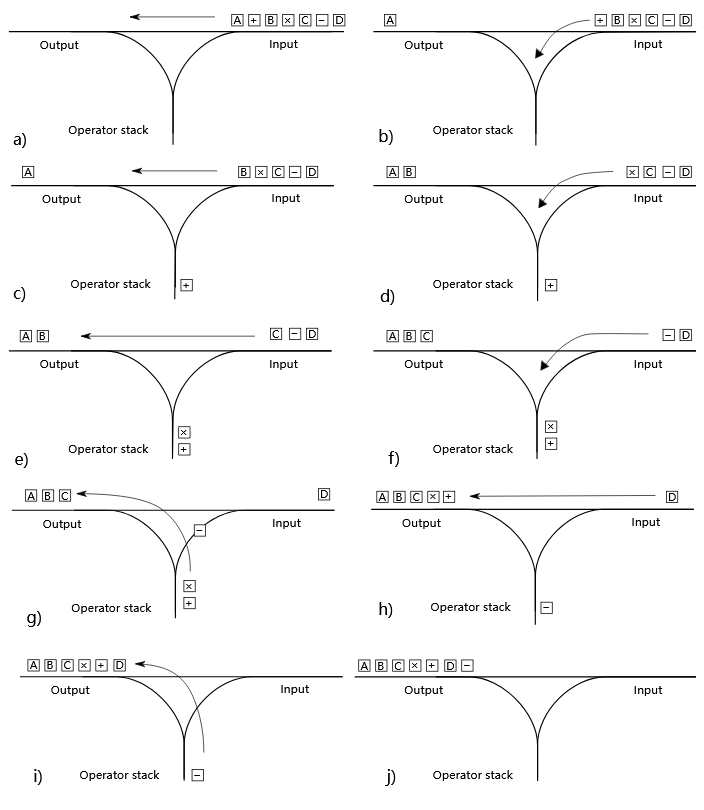
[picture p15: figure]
Shunting-Yard Algorithm | Encyclopedia MDPI

We can see how the tokens are processed from left to right, and the operators are pushed and popped from the stack as needed. In this example, the letters represent numbers, so are pushed to the output when encountered. The other operators are treated according to the BIDMAS order of operations. An explanation of this example is as follows:

  a. The number A is pushed to the output.
  b. The operator + is pushed to the stack.
  c. The number B is pushed to the output.
  d. The operator x is pushed to the stack. As the + operator has lower precedence, it is not popped from the stack.
  e. The number C is pushed to the output.
  f. The operator - is pushed to the stack. The x operator has a higher precedence so is popped to the output. The + operator has the same precedence and the - operator is left-associative, so it too is popped from the stack.
  g. The number D is pushed to the output.
  h. The operator - is popped from the stack to the output as there are no more tokens to process.

I also need to do some pre-processing as mentioned above to convert the inputted expression into a form suitable for processing with this algorithm. Firstly, I will need to write out operators explicitly. For some operators, such as exponentiation, it will only render a superscript on the user interface, but in the backend, it will use the carat operator, so I will not need to process it further. The main operation to process is implicit multiplication, that is, AB as opposed to A*B or AxB. I will do this using regular expressions (regex). I can search for valid combinations of two letters next to each other, or a number to the immediate left of a letter and appropriately insert the multiplication operator.

Next, I will need to create a plotter.

The plotter algorithm will firstly define a set interval for the function to be evaluated across, and then it will evaluate the function at specific points. It will then use a method of interpolation to join up the curve between the evaluated points, hopefully producing a smooth render, thus converting the vector graphics of the curve into a bitmap format for pixel display in Pygame.

I have done some research on how best to define the interval. I was initially thinking to calculate a number of turning points of the function, and to define the interval so all the turning points lie within it, and also thought to scale the axes appropriately, for example, the sine function in degrees would need to have a larger scale on the x axis. However, after my research into current systems, which I talked about earlier, I realised that this was unnecessary. The majority of graphical calculators, both online and physical devices, have fixed axes, that every graph is plotted to, with features for users to pan and zoom the graph themselves. As I am intending to include these features anyway, it would be a waste of time to try and create an elaborate algorithm to automatically scale the graphs, given the number of edge cases I would have to consider.

As I will discuss later in the hardware section, I have decided on a screen that is 320x480 pixels. I will therefore evaluate points appropriately, at a frequency of x values that will produce a smooth curve through interpolation. I will test out various methods of interpolation with different amounts of values until I find a sweet spot that minimizes computational intensity whilst maximising the smoothness of the function.

I have researched a few different interpolation methods [5] and decided that I will firstly try linear interpolation [6]. This is where each point is joined to the next by a straight-line segment. This method draws a line between the two points, by finding the gradient between the points and then drawing the line. Pygame has a line draw function, which takes a start and end point, so I will use this for my implementation.

There are other types of interpolation [7], such as polynomial [8] and spline [9] interpolation. These will produce a smoother curve, but at the cost of processing power, and will take longer to implement. For this reason, I am intending to compute more points on the curve and then use linear interpolation, rather than computing less points but using a different type of interpolation. Hopefully, this should produce an adequately smooth curve [10].

Next, I will need a translator.

This will be a set of functions that can pan and zoom the graph on the screen. I will have a set of 4 arrow buttons on the calculator, as well as either two zoom buttons or a two-way rocker switch with the same function. I will decide which one to use based on the available space on the calculator. There will also be some sort of home button, which will reset the pan and zoom to the defaults. I will describe these buttons in more detail in the hardware section.
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

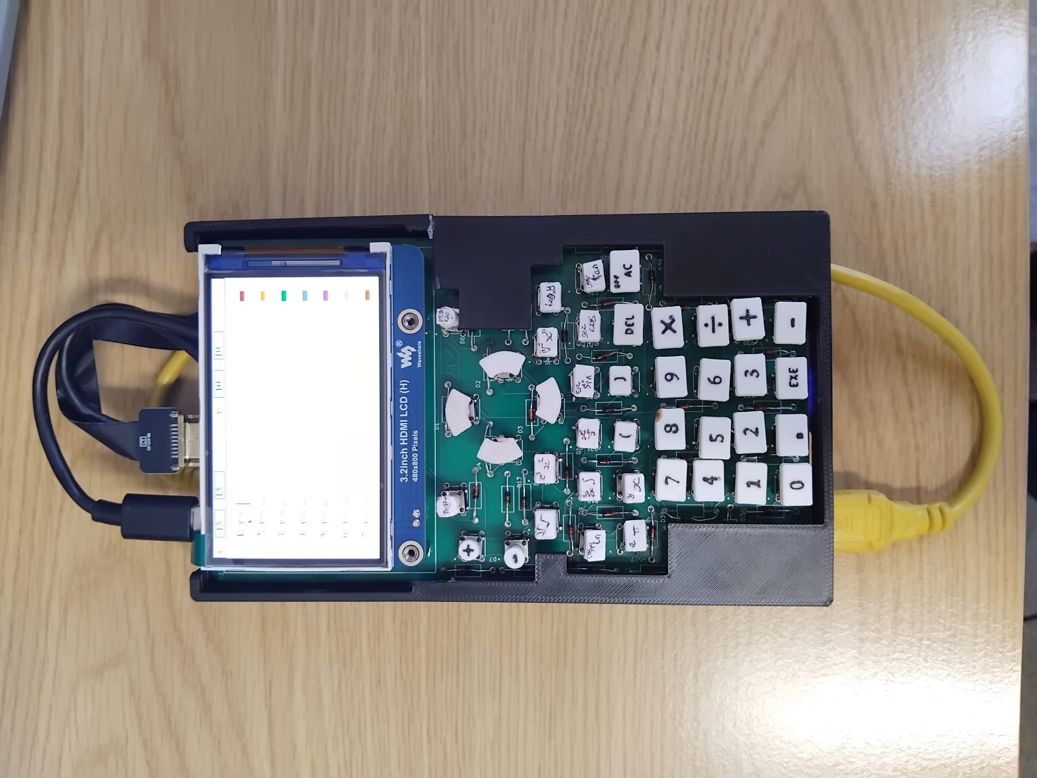
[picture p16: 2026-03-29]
documents/Media/Full hardware.jpeg

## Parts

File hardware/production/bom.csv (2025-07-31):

Designator | Footprint | Quantity | Value | LCSC Part #
D1, D10, D11, D12, D13, D14, D15, D16, D17, D18, D19, D2, D20, D21, D22, D23, D24, D25, D26, D27, D28, D29, D3, D30, D31, D32, D33, D34, D35, D36, D37, D38, D39, D4, D40, D5, D6, D7, D8, D9 | DIOAD1300W80L670D310 | 40 | D
SW0, SW1, SW2, SW3, SW4, SW5, SW6, SW7, SW8, SW9, SWAC1, SWCOS1, SWDEL1, SWDIV1, SWDOT1, SWDOWN1, SWEXE1, SWFRAC1, SWIN1, SWINT1, SWLBRAC1, SWLEFT1, SWLN1, SWLOG1, SWMINUS1, SWMULT1, SWON1, SWOUT1, SWPI1, SWPLUS1, SWPOWER1, SWRBRAC1, SWRIGHT1, SWSHIFT1, SWSIN1, SWSQRT1, SWSQUARE1, SWTAN1, SWUP1, SWX1 | SW_B3F-1050_OMR | 40 | B3F-1050
SWRAD1 | JS102011CQN | 1 | JS102011CQN
U2 | MODULE_RASPBERRY_PI_ZERO_2_W | 1 | RASPBERRY_PI_ZERO_2_W

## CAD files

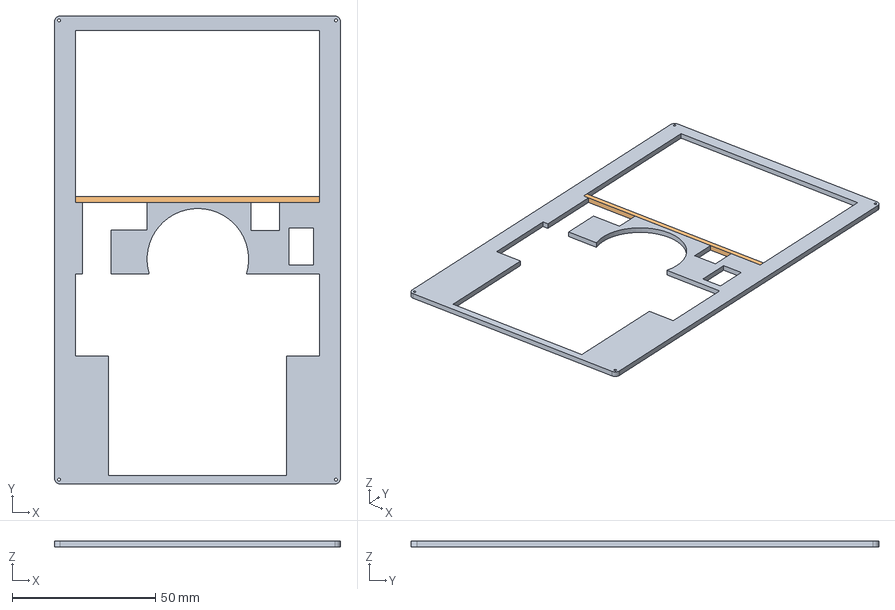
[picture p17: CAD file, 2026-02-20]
hardware/cad/to print/top-plate-full-gaps.step
99.8 x 163.2 x 2.00 mm

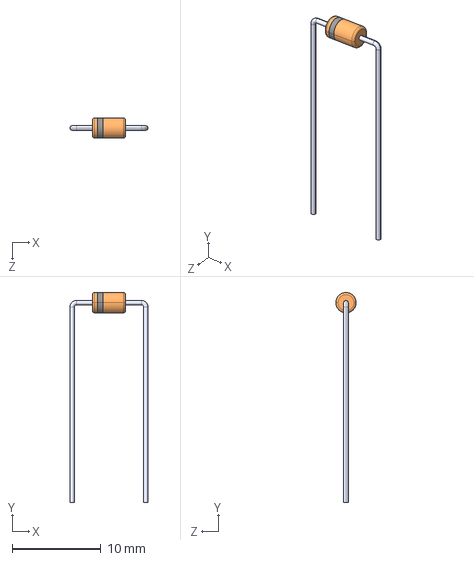
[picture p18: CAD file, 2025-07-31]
hardware/assets/1N4148 _DO-35_/1N4148 _DO-35_.step
8.80 x 23.6 x 2.29 mm

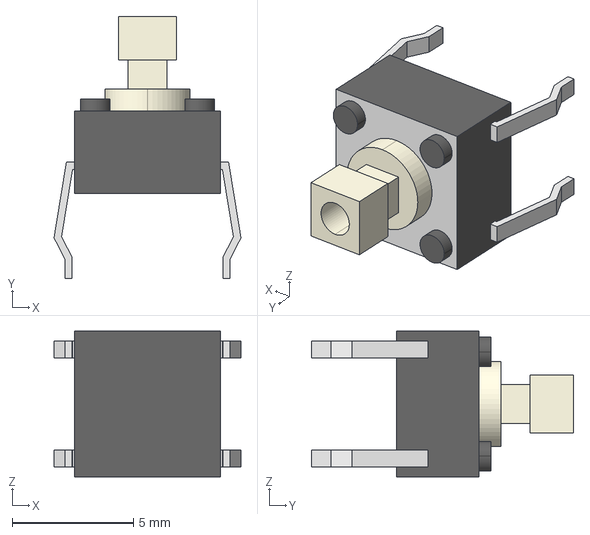
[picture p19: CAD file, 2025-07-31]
hardware/assets/B3F-1050/b3f-1050.stp
7.70 x 10.8 x 6.00 mm

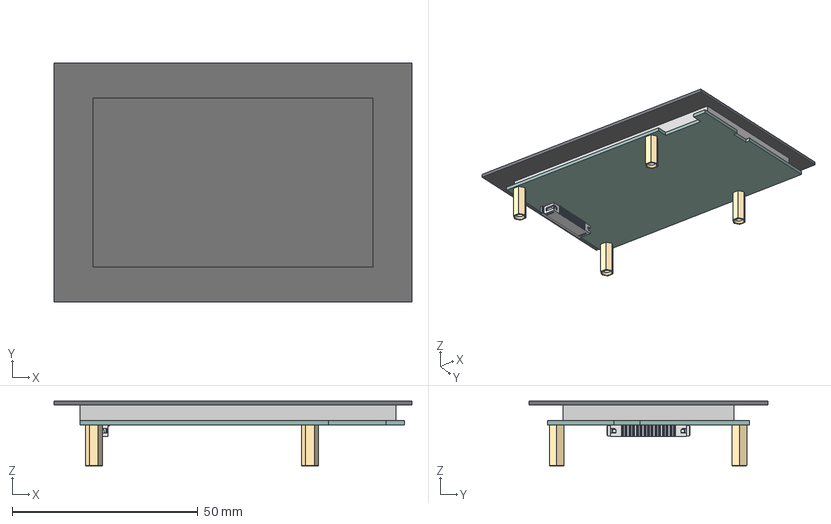
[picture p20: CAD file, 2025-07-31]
hardware/assets/Osoyoo 3.5inch DSI Touchscreen.step
96.5 x 64.5 x 17.5 mm
DSI connector
Glas
PCB
Display
Spacer x 4

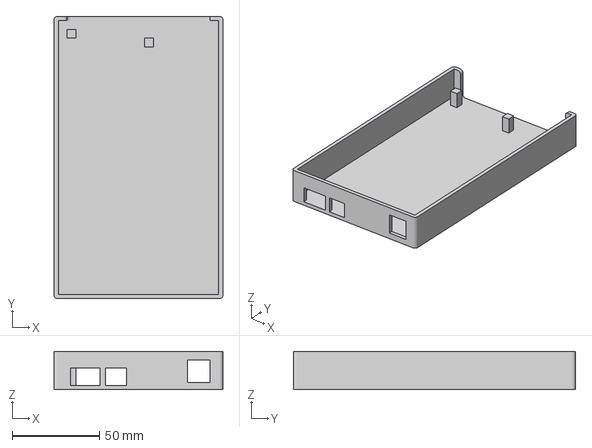
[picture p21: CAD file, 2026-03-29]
hardware/cad/to print/case-new.3mf
97.0 x 162.0 x 22.0 mm

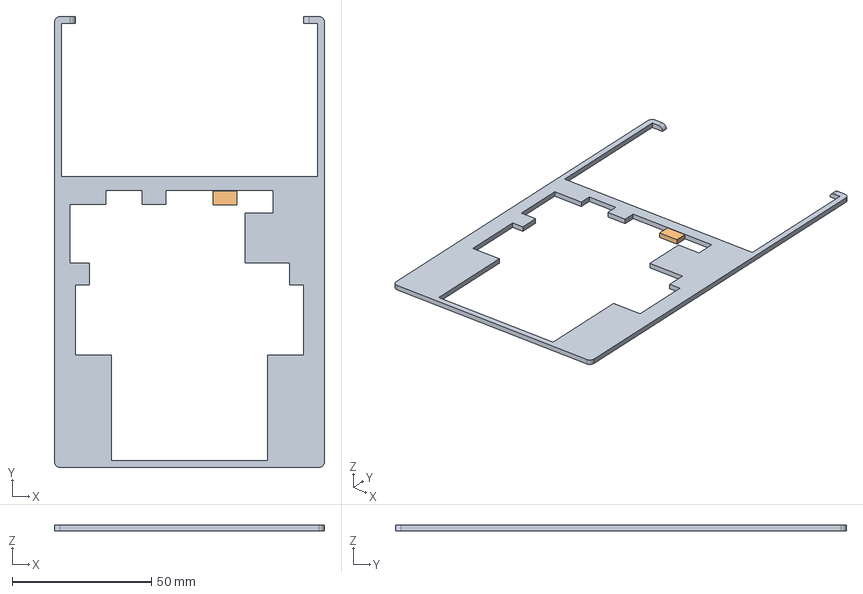
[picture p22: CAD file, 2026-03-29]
hardware/cad/to print/case-top-plate-new-new.step
97.0 x 162.0 x 2.00 mm

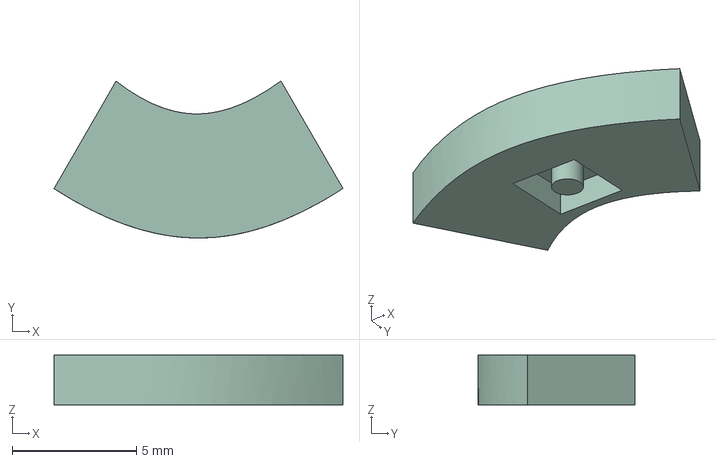
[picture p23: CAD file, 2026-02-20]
hardware/cad/to print/curved-0.2.step
11.6 x 6.33 x 2.00 mm

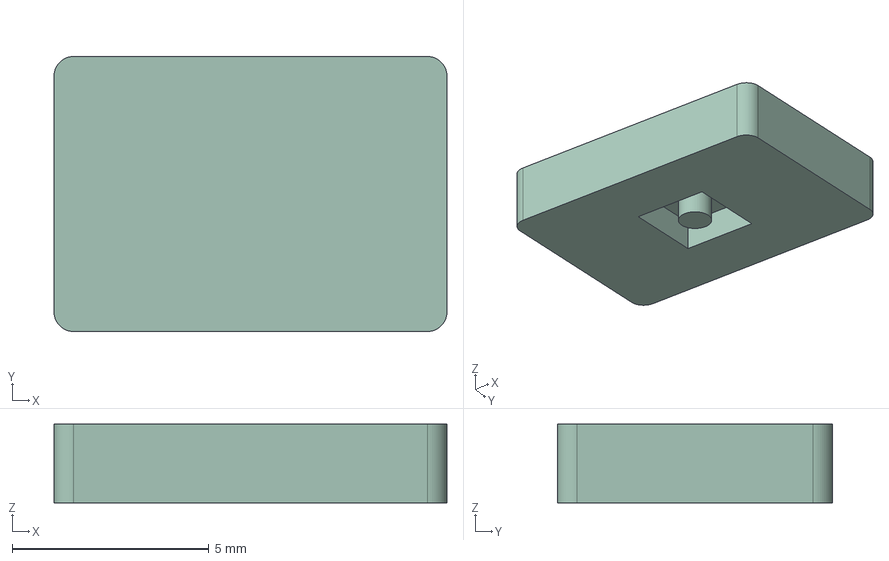
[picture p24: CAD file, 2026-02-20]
hardware/cad/to print/0.2.step
10.0 x 7.00 x 2.00 mm

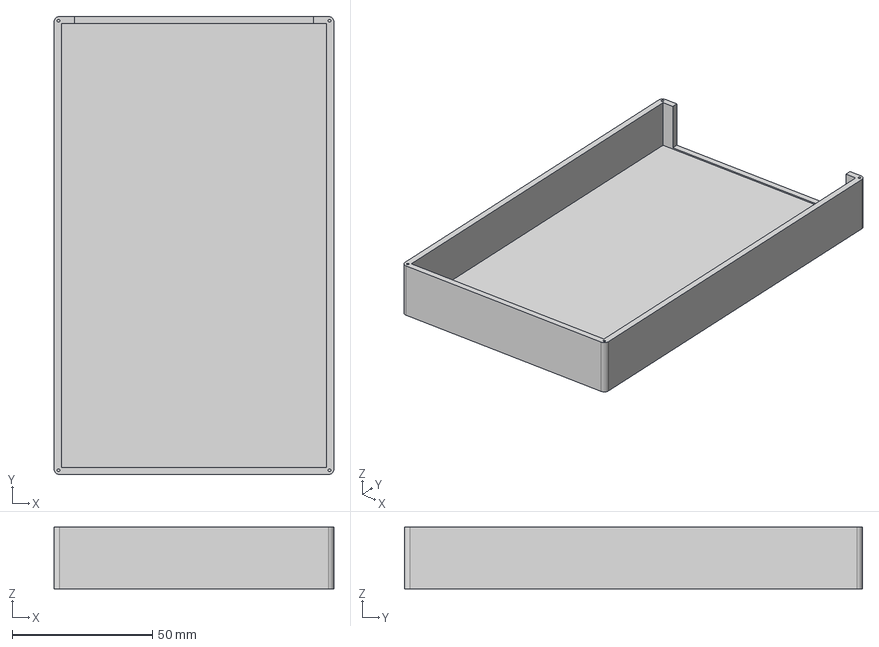
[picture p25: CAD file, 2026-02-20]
hardware/cad/to print/base-medium.step
99.8 x 163.2 x 22.0 mm

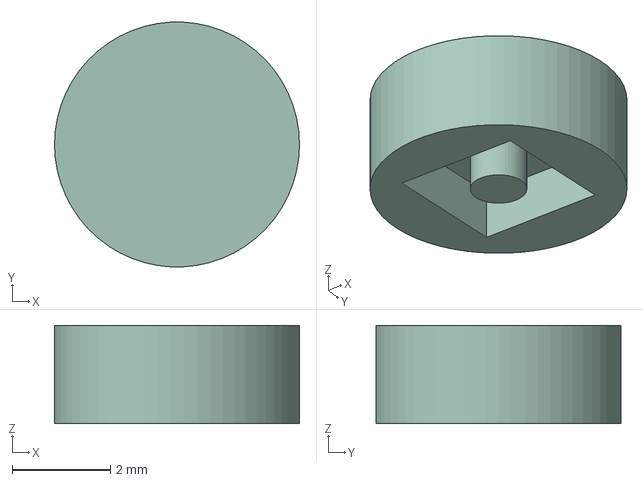
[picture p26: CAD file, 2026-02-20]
hardware/cad/to print/circle-0.2.step
5.00 x 4.99 x 2.00 mm

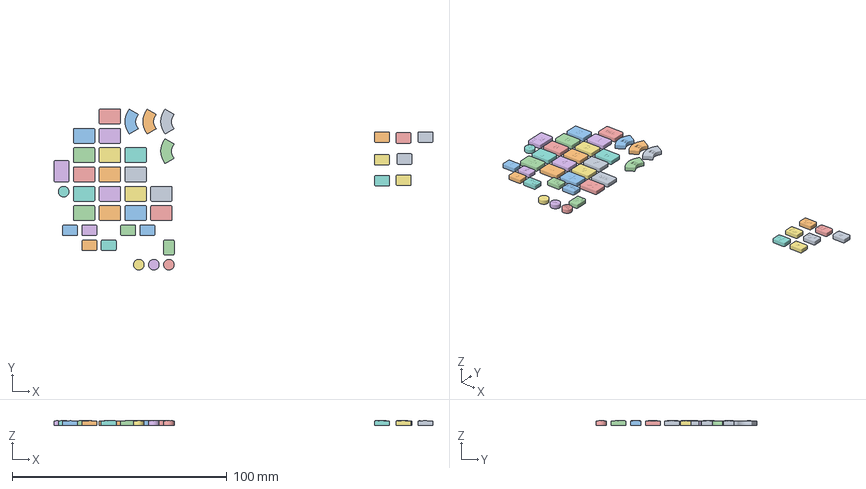
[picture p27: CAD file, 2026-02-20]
hardware/cad/to print/keycaps.3mf
176.4 x 75.0 x 2.19 mm
curved-0.2.step x 4
large-0.2.step x 18
small-0.2.step x 14
circle-0.2.step x 4

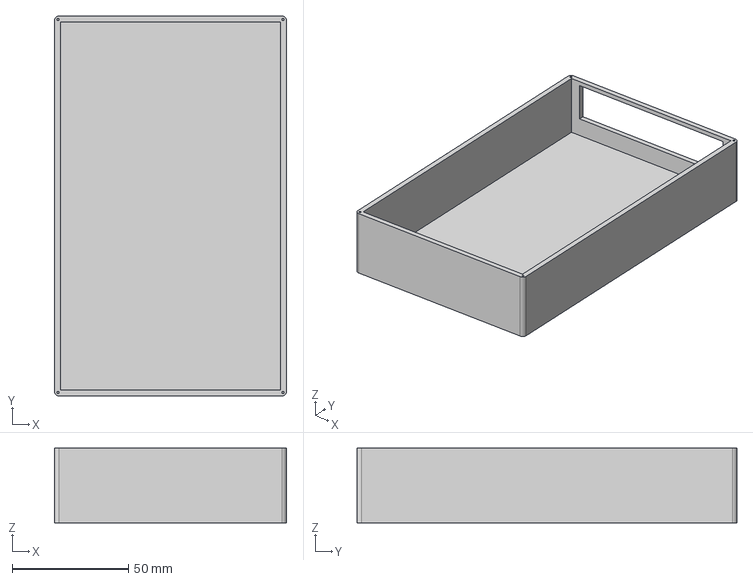
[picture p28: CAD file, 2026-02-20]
hardware/cad/to print/base-large.step
99.8 x 163.2 x 32.0 mm

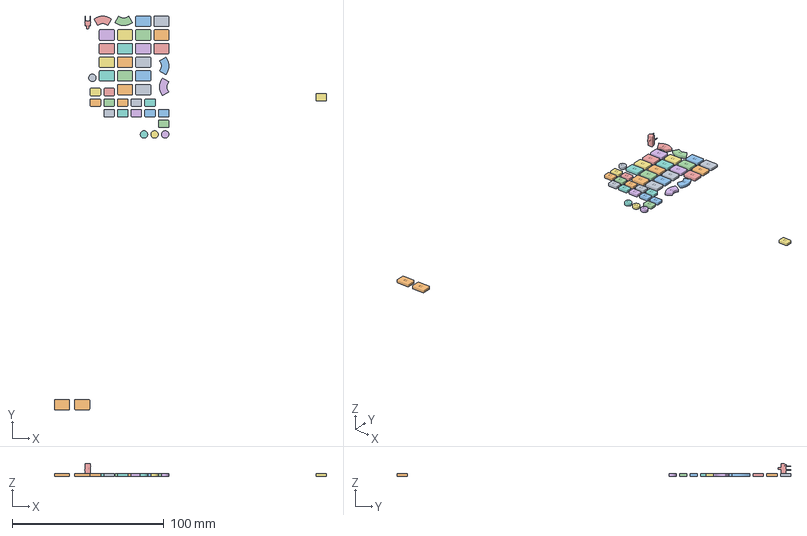
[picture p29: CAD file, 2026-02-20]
hardware/cad/to print/graphical-calculator-keycaps v1.3mf
179.4 x 259.8 x 8.50 mm

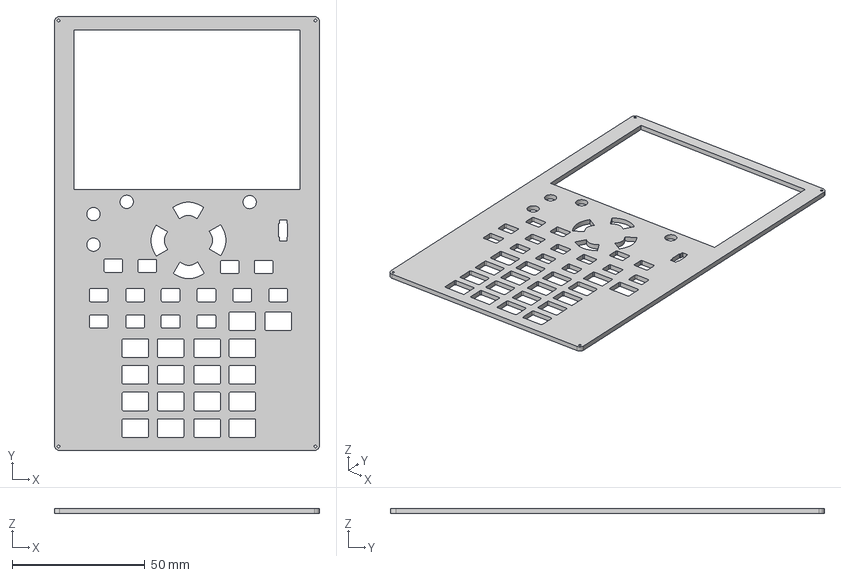
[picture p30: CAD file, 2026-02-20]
hardware/cad/to print/case-top-plate.step
99.8 x 163.2 x 2.00 mm

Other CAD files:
hardware/cad/to print/case-top-plate-new-new-new.3mf
hardware/cad/to print/large-0.2.step
hardware/cad/to print/0.1.step
hardware/cad/to print/small-0.2.step
hardware/assets/JS102011CQN/JS102011CQN.stp
hardware/cad/to print/base-large.3mf
hardware/cad/to print/base-medium.3mf
hardware/cad/to print/case-base.3mf
hardware/cad/to print/case-base.step
hardware/cad/to print/case-top-plate-large-holes.3mf
hardware/cad/to print/case-top-plate-large-holes.step
hardware/cad/to print/case-top-plate.3mf
hardware/cad/to print/top-plate-full-gaps.3mf

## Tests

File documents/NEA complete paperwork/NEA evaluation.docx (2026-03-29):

Overall evaluation

Overall, I think this project has been quite successful. It is the first time I have ever made a proper hardware project without following a tutorial or similar, and I have certainly learnt a lot on the way. The software came together with few issues, and I am especially proud of my expression tree, which is a very robust solution for both rendering text, parsing, and evaluating. There are some things that I planned to do which I have not been able to, including calculus and parametric equations - I severely underestimated the time this project would take, especially on the hardware side (it took around 10 hours straight with only a break for lunch to even get a working prototype). It functions well as a graphing calculator, but has some weaknesses in some areas, specifically the ease of input for some users. I have tried to model it off existing solutions, so it is fairly intuitive, but could be better if I had invested some more time into considering the user input. The hardware itself does not look the most polished, but I am very proud of it and what I have managed to achieve. I have learnt a lot of new skills through this project, and I am glad to have taken it on.

Evaluation of objectives

My first objective was to create a parser for arbitrary polynomials, and I have done this quite effectively. My first prototype used Regex, and this was what I had planned to use for pre-processing before the parsing stage, however now that I have implemented the more robust solution of an expression tree, Regex is no longer needed. Implicit multiplication is now implemented at the tokenisation stage in the expression tree, and I have managed to reduce it to 3 cases, which works very well. The parser itself uses the shunting yard algorithm to convert the infix representation of the expression, which is output after the tokenisation stage, to postfix notation, which can then be evaluated. I only need to use a stripped-down version of the shunting yard algorithm as complex operators and functions are all handled directly by the expression tree. This objective has thus been met satisfactorily.

My second objective was to generate a list of points for the graph. I use my evaluator module for this, which takes the postfix notation previously generated and firstly parses it using a stack, to create a single lambda function defined in terms of x. This is quite an elegant solution, as the principles of functional programming allow me to pass the evaluated function through other functions as a variable. I then generate a list of evenly spaced x values for the points using a custom range function that works with floating point numbers, and calculate the y values by function calls to the lambda function. This works very well, and can generate points for all the expressions entered by the user.

My third objective was to create a mock-up display for testing purposes with Pygame, which plots the graph on a screen. I have done this, and this mock-up display has been iterated upon to serve as the actual user interface for the calculator, as it works by running the Python program on a Raspberry Pi connected to an LCD screen. The interpolation behaviour at asymptotes means that a straight line is drawn, but I am fine with this as it is quite tricky to calculate exact values for asymptotes numerically.

My fourth objective was to add translation functions for the graph display screen - zoom and pan. These both work as intended, and I have some variables for the bounds in the constants file which are updated as necessary for the translation to work properly.

My fifth objective was to extend the parser to other Cartesian equations - specifically radicals, exponentials, reciprocals, logarithms and trigonometric equations. Due to my expression tree, this was quite simple to implement as all the underlying framework was already there in the way that I have built the program. All these equations therefore work very well, and I am happy with the implementation.

My sixth and seventh objectives were to extend the parser to parametric equations and calculus (derivatives and antiderivatives). Unfortunately, due to underestimating the scale of the project, I was not able to implement these two, but the calculator has buttons spare for them, so in the future, I could implement them.

My eighth objective was to add support for multiple equations, which I have done satisfactorily, including different colours for plotting them on the same screen. The calculator has support for up to 7 equations, which I think is more than sufficient.

My ninth objective was to test the software, which I have done at various points throughout development, and I am happy with the full software now.

My tenth objective was to design the physical calculator, and I have done this now. I had to create a schematic for the calculator first, then make it into a PCB design which needed to be routed and wired. I finally had to design a case using CAD software, which I could then 3D print. I have iterated upon the case quite a few times, and I am now happy with the final design. Designing the hardware was not too tricky as there are a wealth of resources available online which helped me, however it took quite a while to do.

My eleventh and final objective was to build the physical calculator. I firstly ordered the PCB that I had created, and then had the task of soldering 240 joints for the buttons and diodes. Upon completion of this, I realized that, due to a mistake with the schematic, I had soldered all the buttons on the wrong way round. Thankfully, the minimum order for the boards was 5, and I had bought components in bulk, so I had enough to completely redo it, which didn’t take too long as I had got the hang of soldering by then. I then had to install the Raspbian OS onto the Raspberry Pi, which involved a lot of fiddling with SD card formatting, and then load the program onto it, which I did using SSH from my laptop. With all of this done, I finally plugged the Raspberry Pi into the screen, and after tweaking a few settings, I got it to work. I then created a script to run the program on boot, and the calculator was then working! Finally, I assembled the calculator into the case, and I had to re-design the case a few times when I measured how the soldering actually came out on the PCB. Due to the buttons having to be turned round, they are not exact with the placements, so the top plate cannot have lines between each of the buttons, but it still functions alright. Overall I am very happy with the hardware, as this is my first time putting together a full hardware project, and even though there are some problems and it could be more polished, it functions fine.

Improvements

Some things that I could improve in future versions of the project are the features, the user experience, and the hardware.

Firstly the features - as mentioned, I would like to add support for parametric equations and calculus. I would also like to add support for implicitly defined functions, and functions of the type x=. I would do this by having a selector for function type when the user inputs something. x= functions would be simple to parse as it would just mean swapping the x and y axes when plotting. For parametric equations, I could evaluate as before but in terms of the parameter, but this would not fit the screen size very well, as some points that are evaluated will be outside the bounds. A better way to do this, which would work for implicit functions as well, is the marching squares method, whereby I divide the screen into quadrants and check each one for the presence of a sign change, indicating that the function passes through it, and then recursively check sub quadrants to a certain resolution. This means that only squares where the function exists will be calculated.

For calculus, I would like to implement derivatives and anti-derivatives. I would use numerical methods for both - for derivatives I could use Euler’s method, where it approximates the gradient of the curve at points with very small intervals between them to provide an accurate representation of the derivative. For antiderivatives, I would use the trapezium rule, where the area beneath the curve is approximated as a series of trapezia, which approximate the section of the curve exactly as the number of trapezia tends to infinity.

The user experience could be improved, particularly on the input screen, as some people in user feedback have reported being somewhat confused about the methods to select different functions with the arrow keys, and the role of the EXE button. I would probably add further visual cues to the user, such as small arrows as hints, and also some physical visual cues for the hardware, such as changing the colour of the EXE button.

The hardware itself could be more polished, and I would do this by remaking the schematic with the symbols for the switches having the correct orientation, which would enable them to sit perfectly into the holes on the board. This would then allow a top plate to be put in that covers all the buttons, as the buttons would have regular spacing. I would find a better way to fix the keycaps to the buttons, as superglue had a few problems with accidentally sticking some of the buttons down and restricting their movement. I would then redesign the case to be a bit smaller, and probably slim the board down slightly as well, and then change the battery for the Raspberry Pi to be smaller also. I would re-orient the Raspberry Pi so that the wiring can sit inside the case rather than having to stick out, which is another problem that users pointed out in feedback, and put holes in the PCB for physical wiring to make the board look cleaner and the wiring less bulky. I would utilise the toggle switch properly, as I had attempted to make it an off switch after realising it was wired incorrectly for user input, but accidentally broke one of the pins so it was unusable. I would just redesign the PCB so it is wired correctly and would work properly. I would also make the case use screws rather superglue to hold together, which would allow easier access to the components and make it look nicer, and I would make the case shell more rounded. I would also replace the switches with membrane switches to make them nicer to press, and then the keycaps could be printed for a snug fit rather than superglue again.

User feedback

I asked multiple people who filled in the initial user feedback form for my project analysis to review the completed calculator (the hardware version), and give feedback. I asked 5 open-ended questions to see what people’s thoughts were on the calculator, and provided minimal interference with their exploration of the features.

Firstly, I asked them to comment on the ease of use of the input screen. Most people said that it was easy to understand and use, specifically citing the clear inputs, minimalism of the display and quick feedback. One person said that the cursor behaviour was slightly tricky to work out initially, but due to the responsiveness of the design and a brief explanation, it became easy to use.

As discussed above, I would like to improve the input screen on a future iteration of the design, but I am nonetheless mostly happy with the current design of the screen.

Next, I asked people to comment on the ease of use of the graph screen. People said that it worked well and was very cool to see their graphs plotted in real time on a physical device. They liked that there were no unnecessary details on the display, and the zoom function was specifically noted as excellent and easier to use than on a standard graphical calculator. One person noted a bug with the zoom function - that it does not keep the centre of the screen in the same place.

I have fixed the bug in the testing section, and now the centre of the screen stays constant when zooming.

I then asked people to comment on the intuitiveness of the controls. People generally said that they were very intuitive, as the buttons are a good representation of their inputs, and the control scheme is easy to understand. A few people noted that as the buttons were generally in familiar places, following the design of other Casio calculators, they felt familiar and intuitive. A couple of problems flagged were that the writing on the buttons was not super clear to read, and some of the functions had to be inputted in a different way to a usual calculator.

The writing on the buttons is tricky to read due to the small size of the keycaps, which cannot really be helped. Some of the buttons have text 3D printed on them, which is legible and stands out easily, while others that have more complex text have stickers on them, on which I have hand-written the text. In the future, I could make this better by printing text onto the stickers. The functions referred to that had to be inputted in a different way to a usual calculator are the power functions, which I have now changed (as seen in testing) to work like a normal calculator - when pressed, the previous object is taken into the base of the exponent.

I then asked for any problems with the calculator, and the main problem flagged was that some of the keys didn’t press properly or were trickier to press than others. Someone pointed out that the keys were not exactly aligned, and someone said that asymptotes were drawn in as vertical lines. Additionally, a couple of people said that the physical device did not look the most polished, and was somewhat bulky.

The problem with the keys was that I superglued the keycaps to the buttons, and some of the glue accidentally got into the switches, so a few don’t press properly. This is unfortunate, but I prefer it to the previous solution, which was sticking the keycaps on with Blu-Tack. In the future, I will find a better way to put the keycaps on, or maybe put them on in a way that ensures the glue cannot get onto the switch mechanism. The keys are not exactly aligned due to the problem discussed where the switches had to be turned 90 degrees - there is no way to fix this without re-ordering the PCB and re-soldering everything so I have not done that, but if I iterate upon it in the future, I will do that. The asymptotes are drawn in as vertical lines due to the interpolation between points, and as previously discussed, it is quite tricky to analytically determine the exact position of asymptotes, so I have decided that this solution is good enough and still easily understandable to the user. The device is bulky as it has to fit all the hardware - there is no way around this with the current hardware that I have, but in the future I do want to try and slim it down more.

I asked if anyone wanted to see any more features added, and I got a variety of responses. People asked for factorials, local minima and maxima, root finding, hyperbolic functions, implicit functions, a panel to better hide the wiring, a slimmer design, the calculus to be implemented, and a full case.

Local minima and maxima and root finding are quite difficult to do, and they take a lot of processing power to do numerically, so I decided not to implement these when I was designing the calculator, but they are something that I would explore doing in the future. I can fairly easily add hyperbolic functions in the software, but with the hardware, there is not really enough space on the buttons to add them. I do not want to add a shift mode for the number keys, nor an extra menu screen, so I made the conscious decision at the design stage not to include them, and to include reciprocal trigonometric functions instead (this is also why I have not implemented inverse trigonometric functions). Factorials have the same issue, but there is space to add them as only 1 slot on the keys is needed, so I may add these in the future. Implicit functions and calculus, as I have discussed, were planned to be added, but I unfortunately did not have time to implement them. I will explore doing these in the future as well though. Finally the physical design of the case to cover the wiring and PCB between the buttons - the top plate has to go around the buttons as they are not exactly aligned, so in the future, if I got a new PCB with aligned buttons, I would redesign the top plate to fit around all of the buttons. I also would move components around to allow the wiring to sit inside the case rather than having to poke out.

I finally asked for any other comments, and the only ones I got were that the calculator was incredibly impressive and it was a great project.

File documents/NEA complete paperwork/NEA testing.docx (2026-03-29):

Testing

Below is a test table for a variety of different tests to the calculator. All the tests were run on the physical hardware, but I have taken screenshots of the version of the program that runs on my computer for ease - there is no difference between the workings of them for testing purposes. I have highlighted results in green where the tests have passed, yellow where they have passed but perhaps not entirely as intended, and red where they have failed.

Objective | Input | Expected | Actual
Test how not filled functions work | sin() | Returns some form of error message | Puts a box where I did not enter anything
Functions that are undefined at certain ranges | x^x | Doesn’t show anything there | No values appear where the function is undefined (x<0)

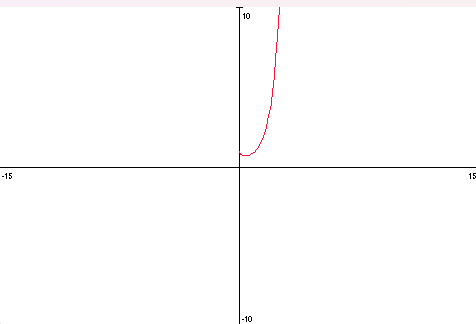
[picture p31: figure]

Adding things that should move the cursor does | x^2 | When you press the button “x^n”, the cursor moves to be in the power | The cursor stays in the original number rather than moving to the superscript.
Functions that are undefined everywhere | x/0 | When you press “exe” either an error is sent or nothing is displayed. | An empty grid is displayed.
Entering a negative range | x: 10 - 0 | An error message is displayed | Axes are flipped, but graphs are not plotted

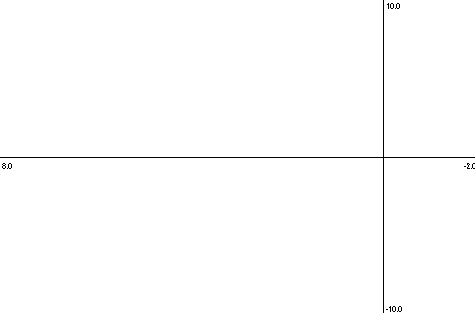
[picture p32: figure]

Entering negative values for rows | x: -100 - -20 | The graph has an x-range from -100 to -20 | You cannot enter negative numbers in the range
Putting a range of 0 | x: 0 - 0 | An error message is displayed | The program crashes
Putting a very large range | x: 0 - 999,999,999,999 u: 0 - 999,999,999,999 y = x | The program might run or might return an error message | The box for the range does not expand with the number, so it goes outside the box. The numbers can also overlap with each other and go off the screen.

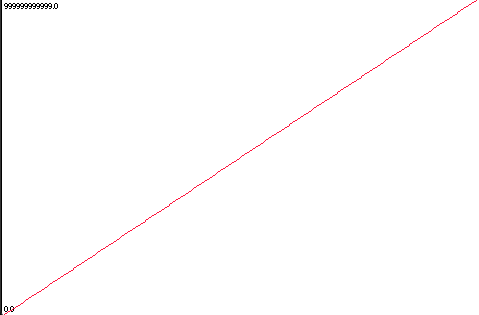
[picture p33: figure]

Entering multiple decimal points in a number in a function | y=1.0.1 | An error message is displayed | The function disappears
Entering multiple decimal points in a number in the range | x: 0.0.1 - 3.0.5 | An error message is displayed | The range is reset to the default
Entering a function that is invalid | y = x.sin(x) | An error message is displayed | The function disappears
Entering a variable in the range | x: x - 2x | An error message is displayed, or you are not allowed to enter that key | You are not allowed to enter that key
Trying to move to a function below function 7 | Down key when function 7 is selected | Reveals more functions or loops back to the top | Loops back to the top
Derivatives and integrals | Press integral/derivative button | Makes a derivative or integral when pressed | Nothing happens
Pressing the move keys moves the centre of the screen in that respective direction | Press right, then up, then left, then down keys | Moves the screen to be centred on something to the right of the current position, then up, then left, then down. | Moves the screen to be centred on something to the right of the current position, then up, then left, then down.
Zoom in or out | Press zoom in/zoom out | The screen zooms in/out, keeping centre of the screen at the centre | The function zooms in to show a smaller region of the graph or out to show more, but when it is not centred on 0, the centre moves around
Zooming into a function that has a pole (a point where a function is undefined) | y = 1/x and x/x -1 and y = x ln (abs(x)) zoom into the middle | It zooms in to the centre of the screen, and displays the right value at the pole | It still zooms properly, and it seems to converge to a pole (e.g. 0 for x/x-1, but the value close to the pole isn’t displayed.
Pressing the off button | Pressing the off button in the function entering menu and the graph menu | The device turns off | The device turns off when in the entering menu, but not when in the graph menu.
Pressing numbers does as expected | Enter 0,1,2,3,4,5,6,7,8,9, ”.” | That number is entered into the selected box | That number is entered into the selected box
Pressing lots of divisions | Enter 1/1/1/1/1/1/1/… | It either keeps going or reaches a limit and stops letting you divide | You can keep entering more divisions, but the fractions keep getting smaller until you can’t see them.
Pressing lots of roots | Enter sqrt(sqrt(sqrt(…) | The square roots keep going and maybe reaches a limit | You can keep entering square roots, but the lines fade and get very small.

Objectives testing

Below is a test table specifically for the objectives created in the analysis section. Results have been highlighted following the same colour scheme as above, and for cases of plotting graphs, I have used Desmos to provide a representation of what the graph should look like.

Objective | Input | Expected | Actual

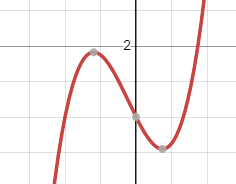
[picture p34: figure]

Create a parser for arbitrary polynomials (1); generate a list of points for the graph (2); create a mock display for testing (3) | 3x^3+x^2-2x+1 | | Plots the graph as below

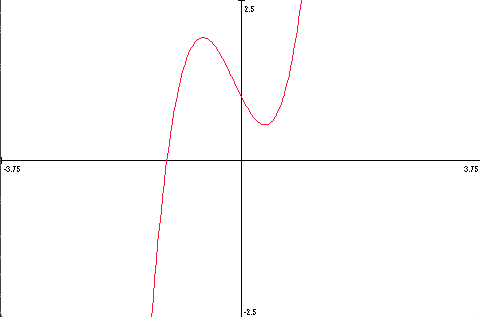
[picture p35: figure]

Add zoom function (4a) | 3x^3+x^2-2x+1, zoom in | Graph zooms in | Graph zooms in

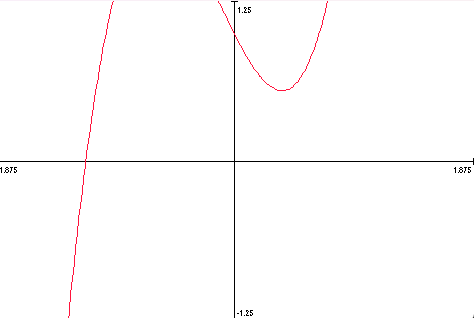
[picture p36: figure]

Add move function (4b) | 3x^3+x^2-2x+1, left key | Centre moves left (graph moves right) | Centre moves left (graph moves right)

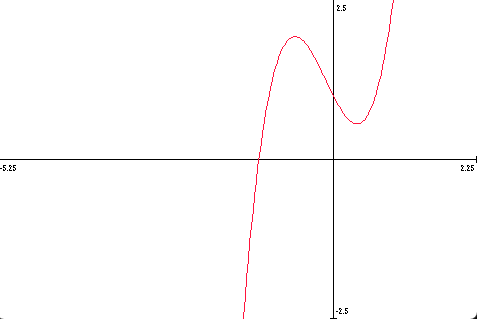
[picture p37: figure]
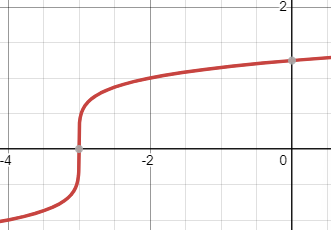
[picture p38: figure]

Radical equations (5a) | 5th root of (x+3) | | Plots the graph as below

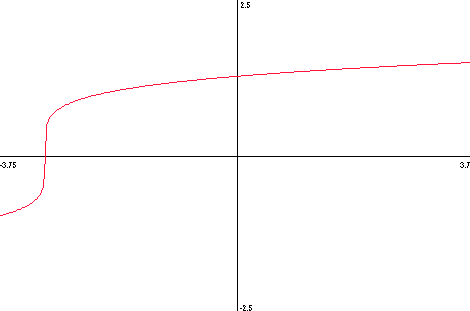
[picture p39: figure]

Exponential equations (5b) | e^x | | Plots the graph as below

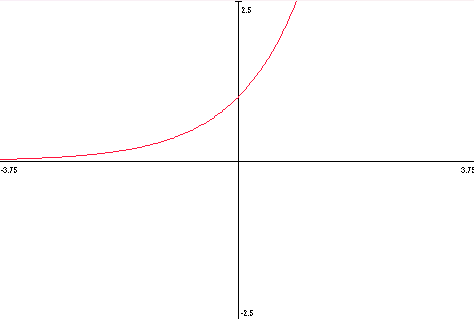
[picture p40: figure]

Reciprocal graphs (5c) | 2/x | | Plots the graph as below


Logarithmic equations (5d) | Log base 5 of x | | Plots the graph as below


Main trigonometric functions (5ei) | tan(x) | | Plots the graph as below but asymptotes plot as straight lines


Reciprocal trigonometric functions (5eii) | csc(x) | | Plots the graph as below but asymptotes plot as straight lines


Parametric equations (6) | N/A | Parametric equation plotted | Not implemented yet
Calculus (7) | N/A | Derivative/antiderivative plotted | Not implemented yet
Multiple equations (8) | csc(x), sqrt(x), x^2, cos(x) | | Graphs plotted as below


Design physical calculator (10), build physical calculator (11) | N/A | Calculator works as a portable device | Calculator works as a portable device - see below


Fixes

Most of the tests passed, as can be seen, but some failed, and some work but not quite as intended. Below I will detail the problems with each of the tests which did not go as expected, and how they could be fixed. I will implement the fixes for the ones that can be easily fixed as well.

One of the problems is that when an exponent is inputted, the cursor stays in the base rather than moving to the superscript, because the user has to input the base after the exponent. In most calculators, entering an exponent automatically puts the previous token into the base. I had not implemented this for my calculator as I only tokenise the inputs at the parsing stage, so the only way to do it would be to use the previous object, and this would lead to problems such as 25^2 being parsed as 2*5^2. However, I have realised that generally for graphing purposes, the user will only be putting a function or a variable to an exponent, which is only represented as one object, so I have implemented this as seen below:


Now the previous character is automatically made into the base of the exponent, and the cursor moves to the exponent when necessary.

Another problem was that the user could enter a negative range, such as 10-0, in the view window. This should not be allowed, so I have added input validation for the view window:


As can be seen, I have made it so that when the graph screen loads and the bounds are updated, it checks then whether the bounds are valid or not, and if not, resets them.

Another problem was that negative numbers cannot be inputted into the view window: this was a quick fix as it was just something I missed in input validation.

I have also added a try except block to catch any errors pertaining to the negative numbers without resetting the entire program, such as if the user types a negative sign not at the start of a number - when triggered, the view window is just reset to the default.

This also fixes the problem about the view window having a zero range and crashing the program - as it is validated this no longer happens.

When entering a very large number in the view window, the number goes off the screen and out of the box. I have thought about this but decided to not fix it, as I believe it is more helpful to the user to let arbitrarily large view window values be input than to make the inputs look aesthetically pleasing and thus cap them at a certain point. A scroll feature would be more confusing to the user I think, especially on a small screen with just the move buttons for controls.

Derivatives and integrals are not implemented, so they do not work - in the future I would like to add them but I have not had time to, what with the scale of the project being larger than expected. Similarly, I have not yet implemented parametric equations.

Zooming in and out on the graph display screen did not work properly when the centre was not (0,0), and I have now fixed this. Previously it simply halved or doubled the bounds, which doesn’t keep the centre the same - now it takes into account the distance between the centre and the bounds.


Zooming into a pole does not show values directly round the pole - this is because they get so big or so small that they are not plotted, and is expected behaviour, although does make the graph look discontinuous at points other than the pole.

The device does not turn off in the graph screen - I have decided to keep this as the shift button does not give graphical updates to the user when in the graph screen, and is only defined for the input screen, so I feel it is best not to implement it for the graph screen to avoid cluttering the screen and making it more confusing to the user.

Pressing lots of nested fractions and nested square roots makes them so small that they cannot be seen - there is not really a way around this other than capping them, which I do not want to do as it reduces the amount of freedom that the user has. I could try to implement some scrolling mechanism but, similarly to with the view window, I feel that it would be quite clunky with just the arrow buttons for the user to move and would clutter the screen more and make it more confusing.

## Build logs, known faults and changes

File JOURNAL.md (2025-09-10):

---
title: "Graphical calculator"
author: "Layan Jethwa"
description: "A custom-built graphical calculator with implementation from scratch"
created_at: "2025-06-09"
total_time_spent: "39 hours"
---
# June 9th: Began to create a list of goals for the project

I created a list of 10 objectives, and began to create subcategories under them after a bit of research into parsing methods.

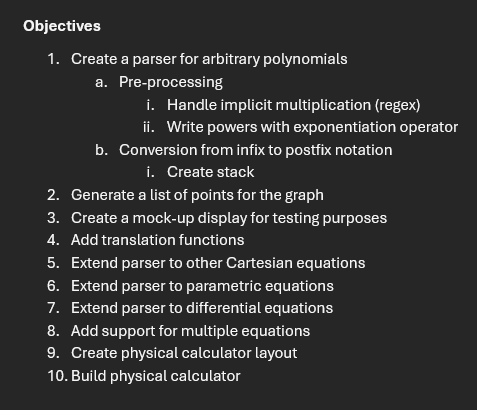
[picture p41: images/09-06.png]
Objectives


**Total time spent: 1h**

# June 16th: Completed breakdown of objectives

I completed all the subcategories for the breakdown of my different objectives, and did research into the algorithms and maths needed, and the hardware components needed. I have uploaded my complete objectives breakdown and current list of links to this repository.

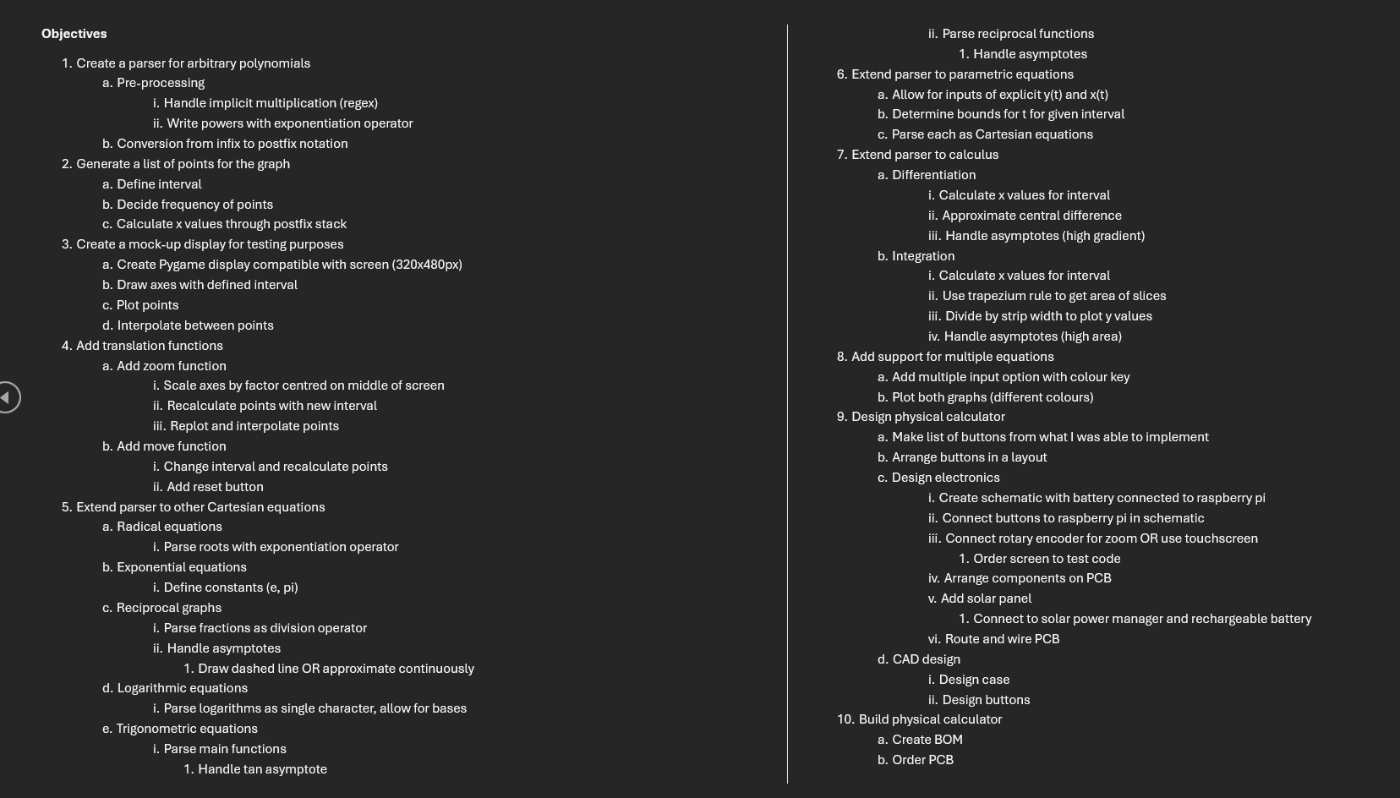
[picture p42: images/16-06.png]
Completed objectives


**Total time spent: 3h**

# June 23rd: Started modelling algorithms needed, and created a form for requirements gathering

I created a list of algorithms to explain, and started to create a plan for them. I also created a Microsoft Form asking people about their experiences with calculators, in order to get ideas and see what people wanted.

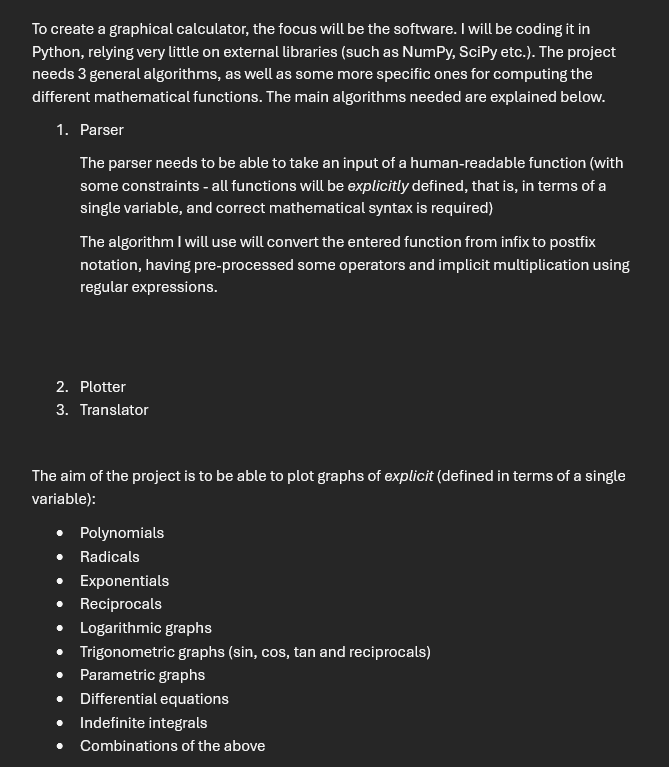
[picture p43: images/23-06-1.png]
Modelling algorithms

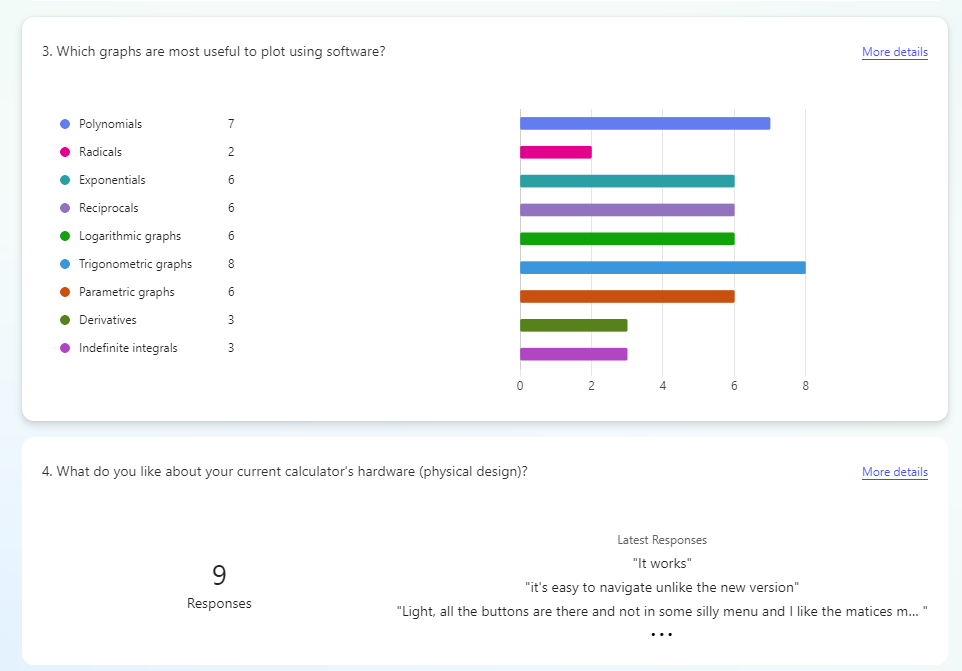
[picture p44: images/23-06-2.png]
Microsoft Form


**Total time spent: 2h**

# June 30th: Started modelling the algorithms used in the project

I did some research into the shunting yard algorithm, and created an explanation of the modelling with diagrams. I also started work on an explanation of my plotter function.

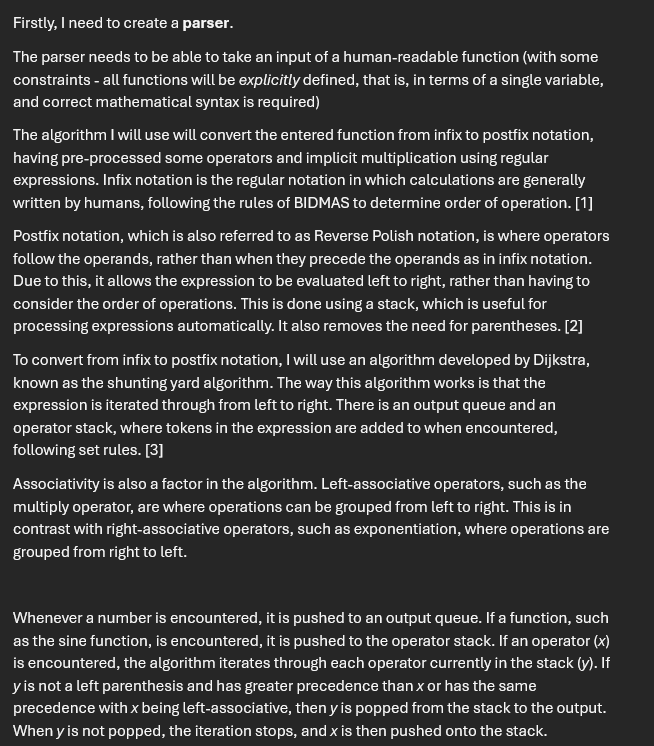
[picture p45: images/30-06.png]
Modelling


**Total time spent: 2h**

# July 2nd: Completed the modelling section for the project write-up

I completed my research into the algorithms needed for my project, and wrote them up into the modelling section, so I will be ready to write the code.

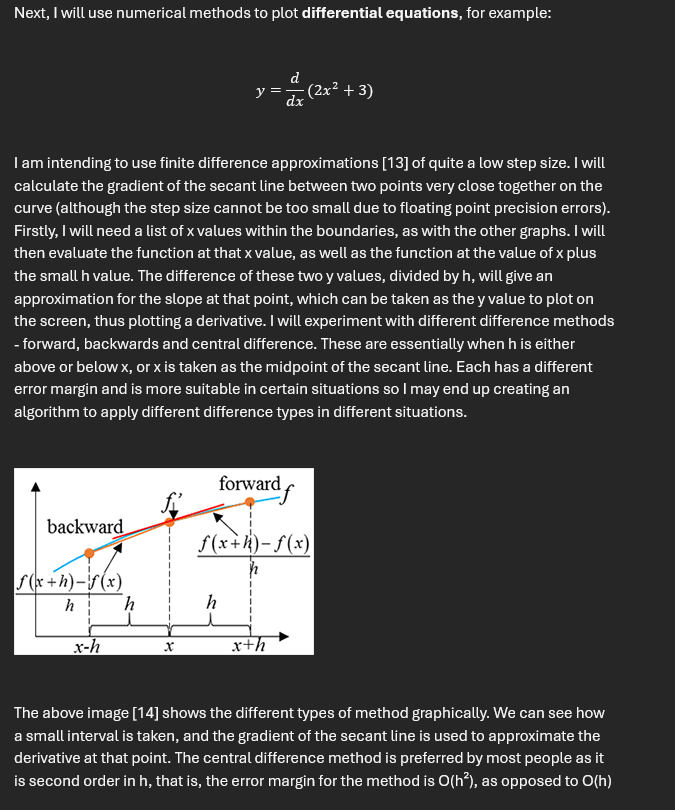
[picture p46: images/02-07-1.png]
Modelling 1

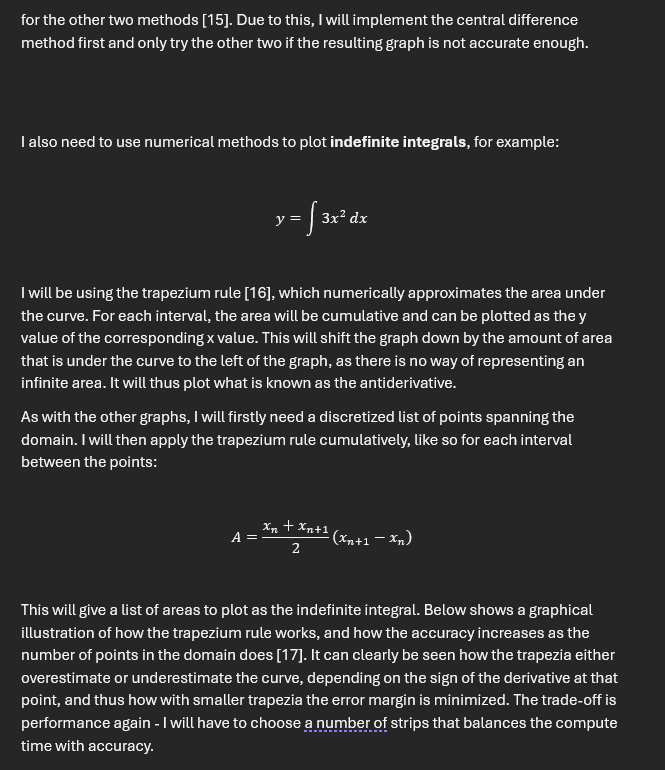
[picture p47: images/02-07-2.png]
Modelling 2


**Total time spent: 4h**

# July 3rd: Started doing some research into current systems

I began researching current systems, namely the Casio fx-9750GII and the Casio fx-CG50, and examined the pros and cons of their design.

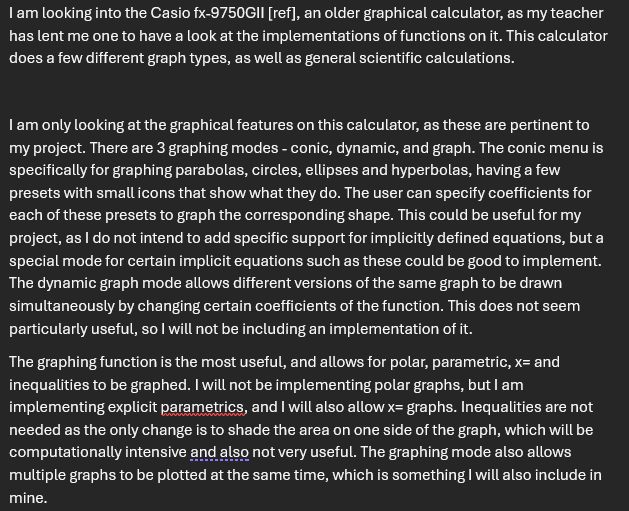
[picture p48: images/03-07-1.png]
Casio 1

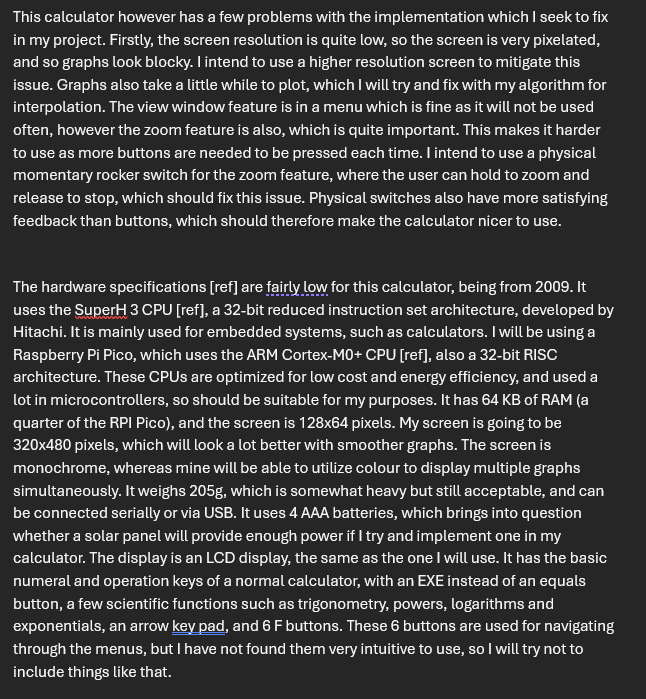
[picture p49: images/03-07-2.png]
Casio 2


**Total time spent: 2h**

# July 21st: Completed full analysis of the project

I completed the entire analysis, which comes to 49 pages and 7970 words. This includes the introduction, features list, end user identification, requirements gathering, research into current systems, modelling, SMART objectives list, hardware, and full bibliography.

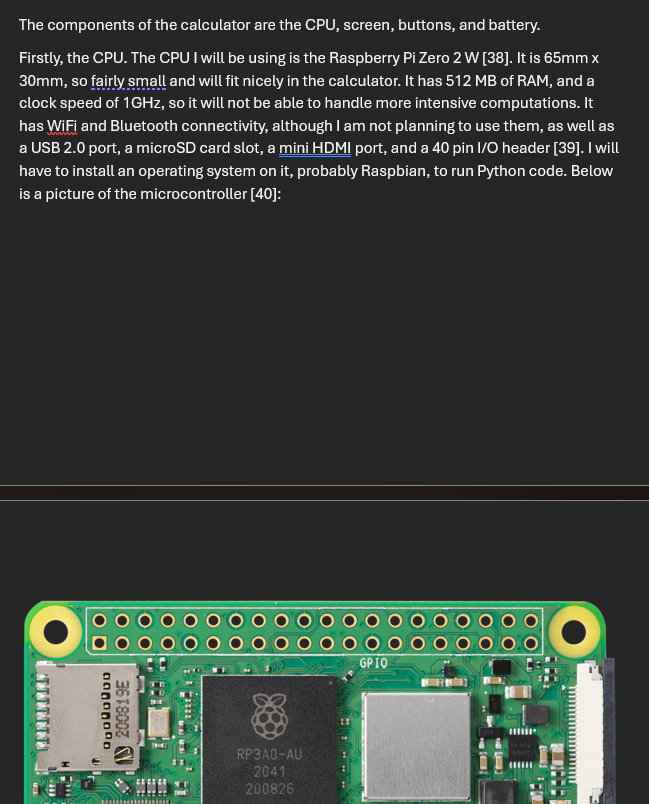
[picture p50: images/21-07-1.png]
Hardware

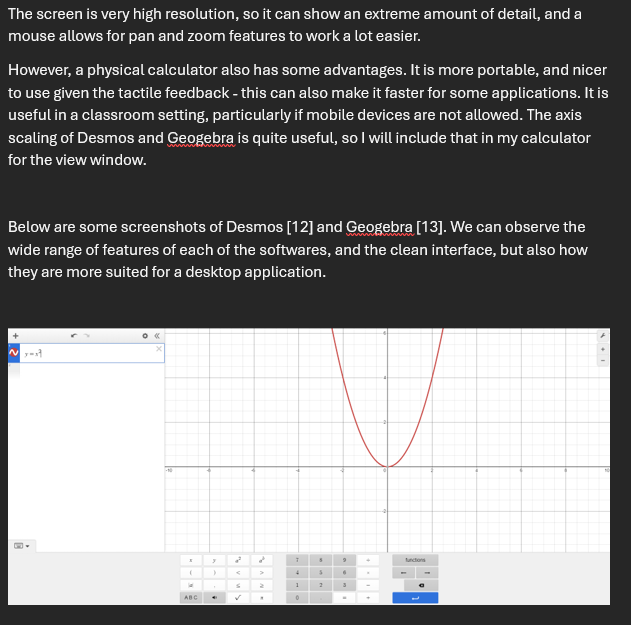
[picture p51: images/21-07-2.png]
Desmos


**Total time spent: 6h**

# July 22nd: Wrote parser, evaluator and basic Pygame display for arbitrary polynomials

I created a parser that pre-processes an equation entered in infix notation and then converts it to postfix. I then created an evaluator that evaluates the expression at a number of evenly spaced points. I then made a basic Pygame display that plots and interpolates the points to create a graph. Below is an image of a graph plotted with Desmos, then the user input for the graph, and finally the output of my code for the graph.

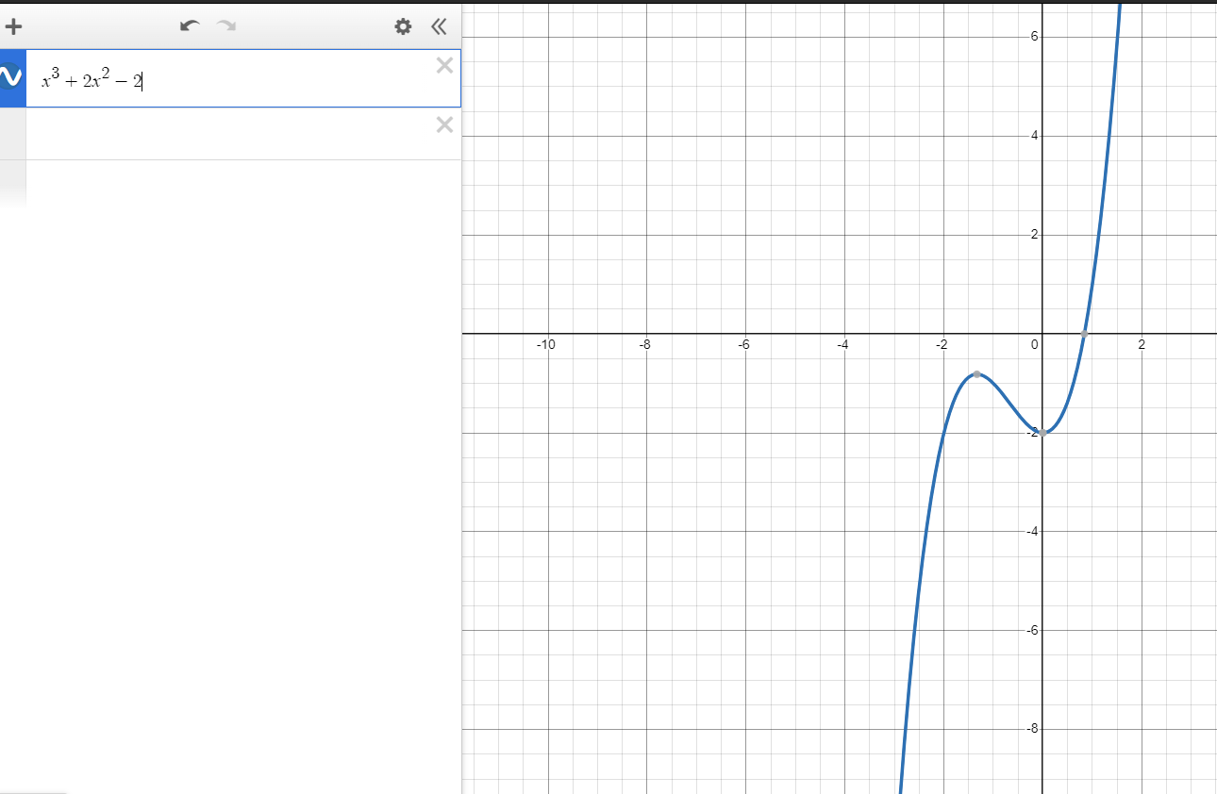
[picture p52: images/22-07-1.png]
Desmos graph

My input
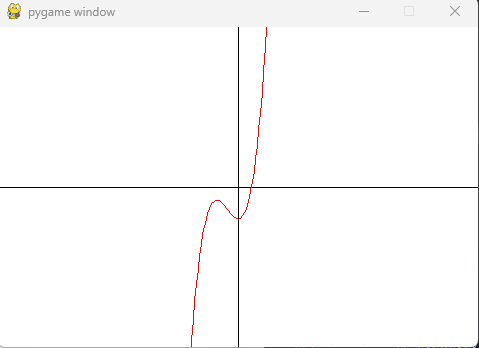
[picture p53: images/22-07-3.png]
Pygame output


**Total time spent: 3h**

# July 23rd: Added an input display screen, fleshed out the graph display screen, and brought it all together

I created a screen where inputs of graphs can be entered, up to 7, with different colours, and a placeholder view window at the top. You can navigate between the graphs with arrow keys and enter, and you can go to the graph screen which plots all the graphs with enter. I brought both screens together with the main function, keeping all the modules nicely integrated with each other.

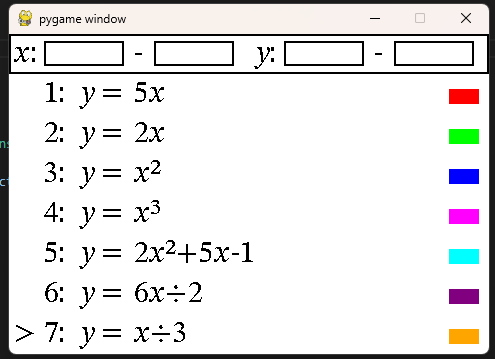
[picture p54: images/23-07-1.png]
Input screen

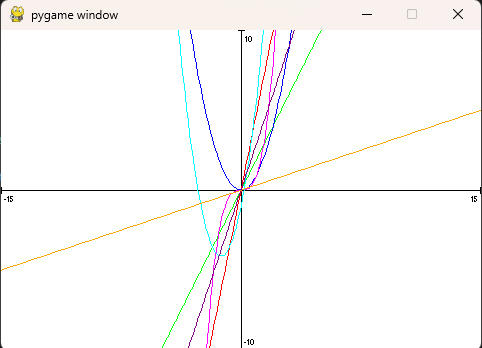
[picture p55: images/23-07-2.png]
Graph screen


**Total time spent: 3h**

# July 24th: Added features and changed design

I updated the design of the input display screen, and changed the parser to allow logarithmic and trigonometric graphs, negative numbers and decimals, graphs with asymptotes, and graphs with constants (pi, e). I also added move and zoom features to the graph, and added a view window feature to change the bounds of the graph.

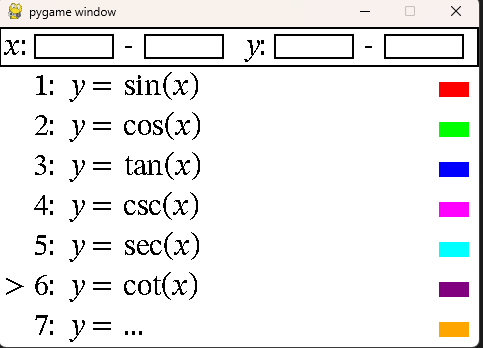
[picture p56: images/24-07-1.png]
Trig input

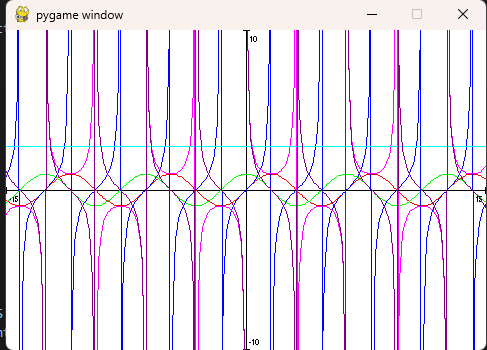
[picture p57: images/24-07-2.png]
Graph output

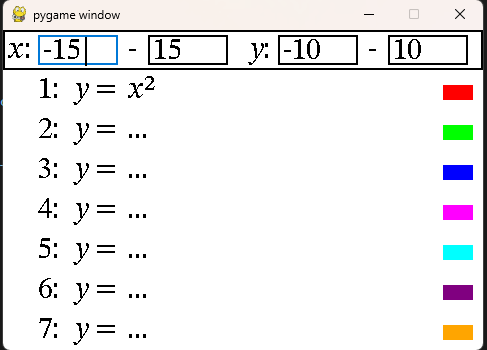
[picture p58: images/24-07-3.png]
View window


**Total time spent: 3h**

# July 27th: Created schematic and PCB

I created the schematic and PCB for the hardware in Kicad, and finalised the button layout.

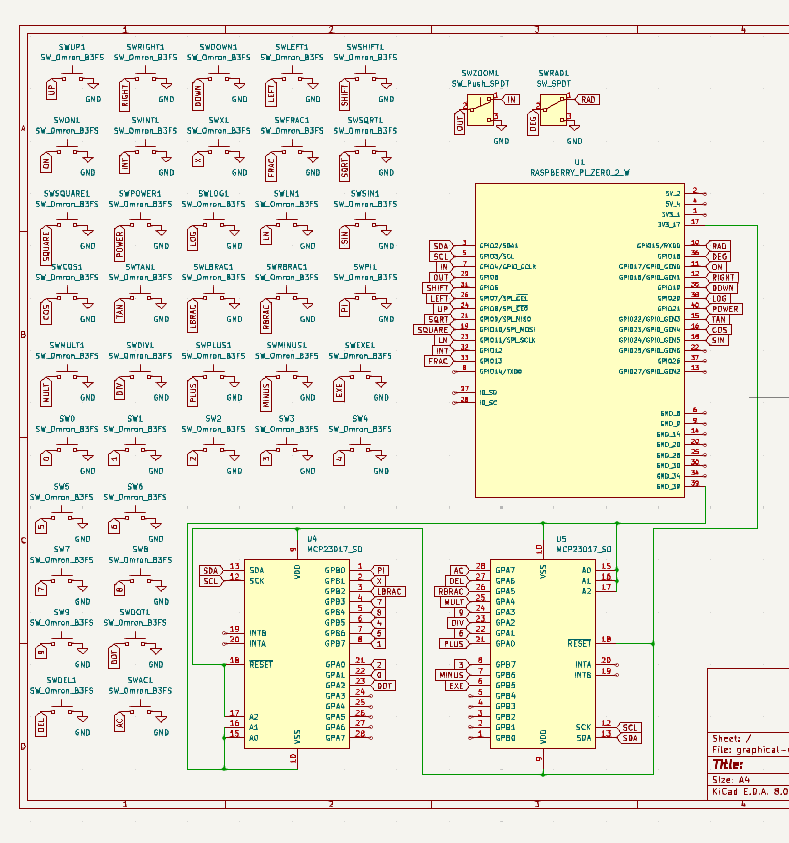
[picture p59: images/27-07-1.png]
Schematic

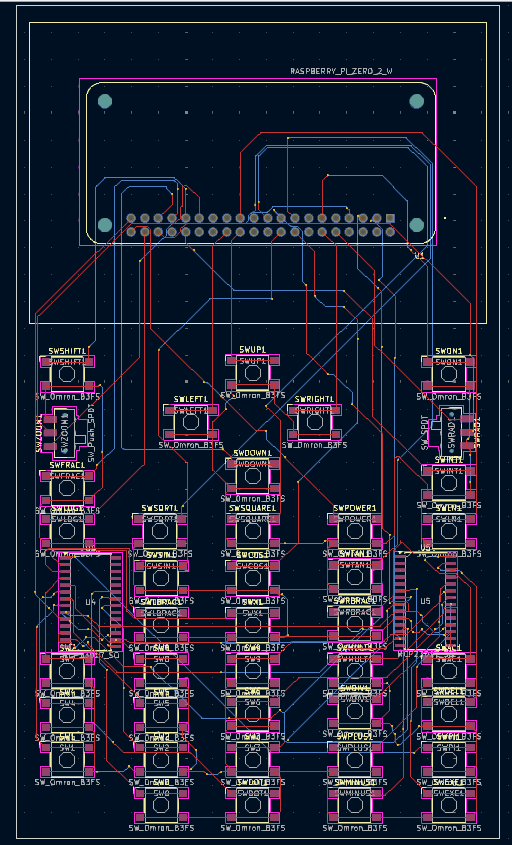
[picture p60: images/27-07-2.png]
PCB

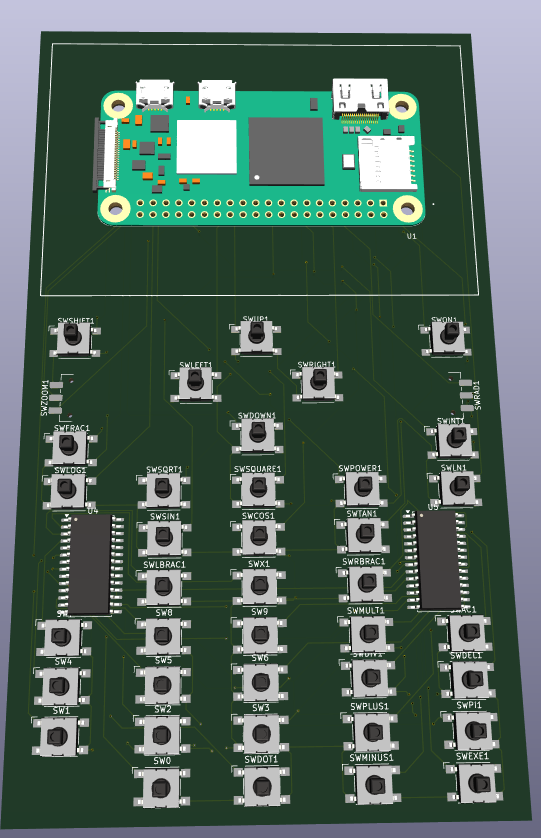
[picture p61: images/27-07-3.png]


**Total time spent: 4h**

# July 30th: Created 3D model, updated PCB

I created the 3D model for the case of the PCB, and updated the PCB multiple times with different parts to get parts that JLCPCB have in stock.

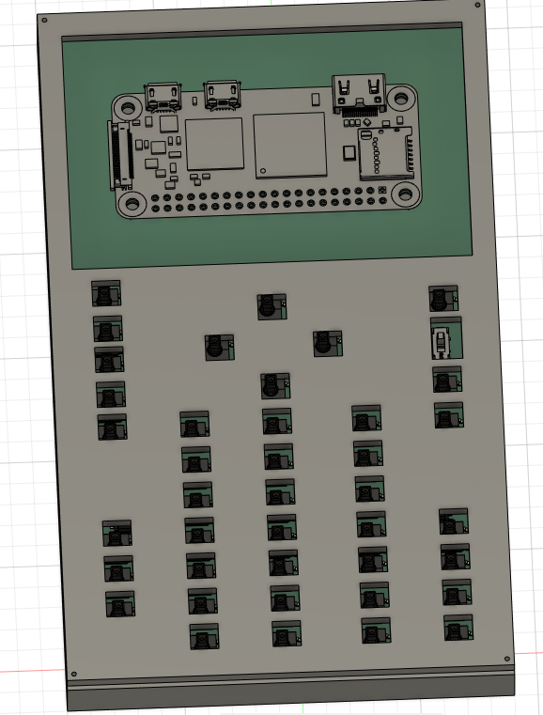
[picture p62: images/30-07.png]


**Total time spent: 6h**

# June 7th: Added button holes, keycaps and pins

I added button holes and keycaps to my 3D render, and I tidied up the render to remove pins sticking out.

3D model

**Total time spent: 4h**

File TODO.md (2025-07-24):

**High priority**
- ~~Graph screen~~
    - ~~Enter to access~~
    - ~~Parsing of input expression~~
- ~~Inputs allowed~~
    - ~~Negative numbers~~
    - ~~Decimals~~
- ~~Move function~~
- ~~Zoom function~~
- ~~Define constants~~
- ~~Asymptotes for reciprocal graphs~~
- ~~Logarithmic graphs~~
- ~~Trigonometric graphs~~
    - ~~Tan asymptote~~
    - ~~Reciprocal functions~~

**Medium priority**
- ~~View window~~
    - ~~Arrows to access~~
    - ~~Entry fields~~
- Parametric graphs
- Differential equations
- Indefinite integrals

**Low priority**
- Rendering engine
    - Exponents
    - Fractions
    - Radicals
- Mode selector
- Colour selector
- x = f(y)
- Types of implicits

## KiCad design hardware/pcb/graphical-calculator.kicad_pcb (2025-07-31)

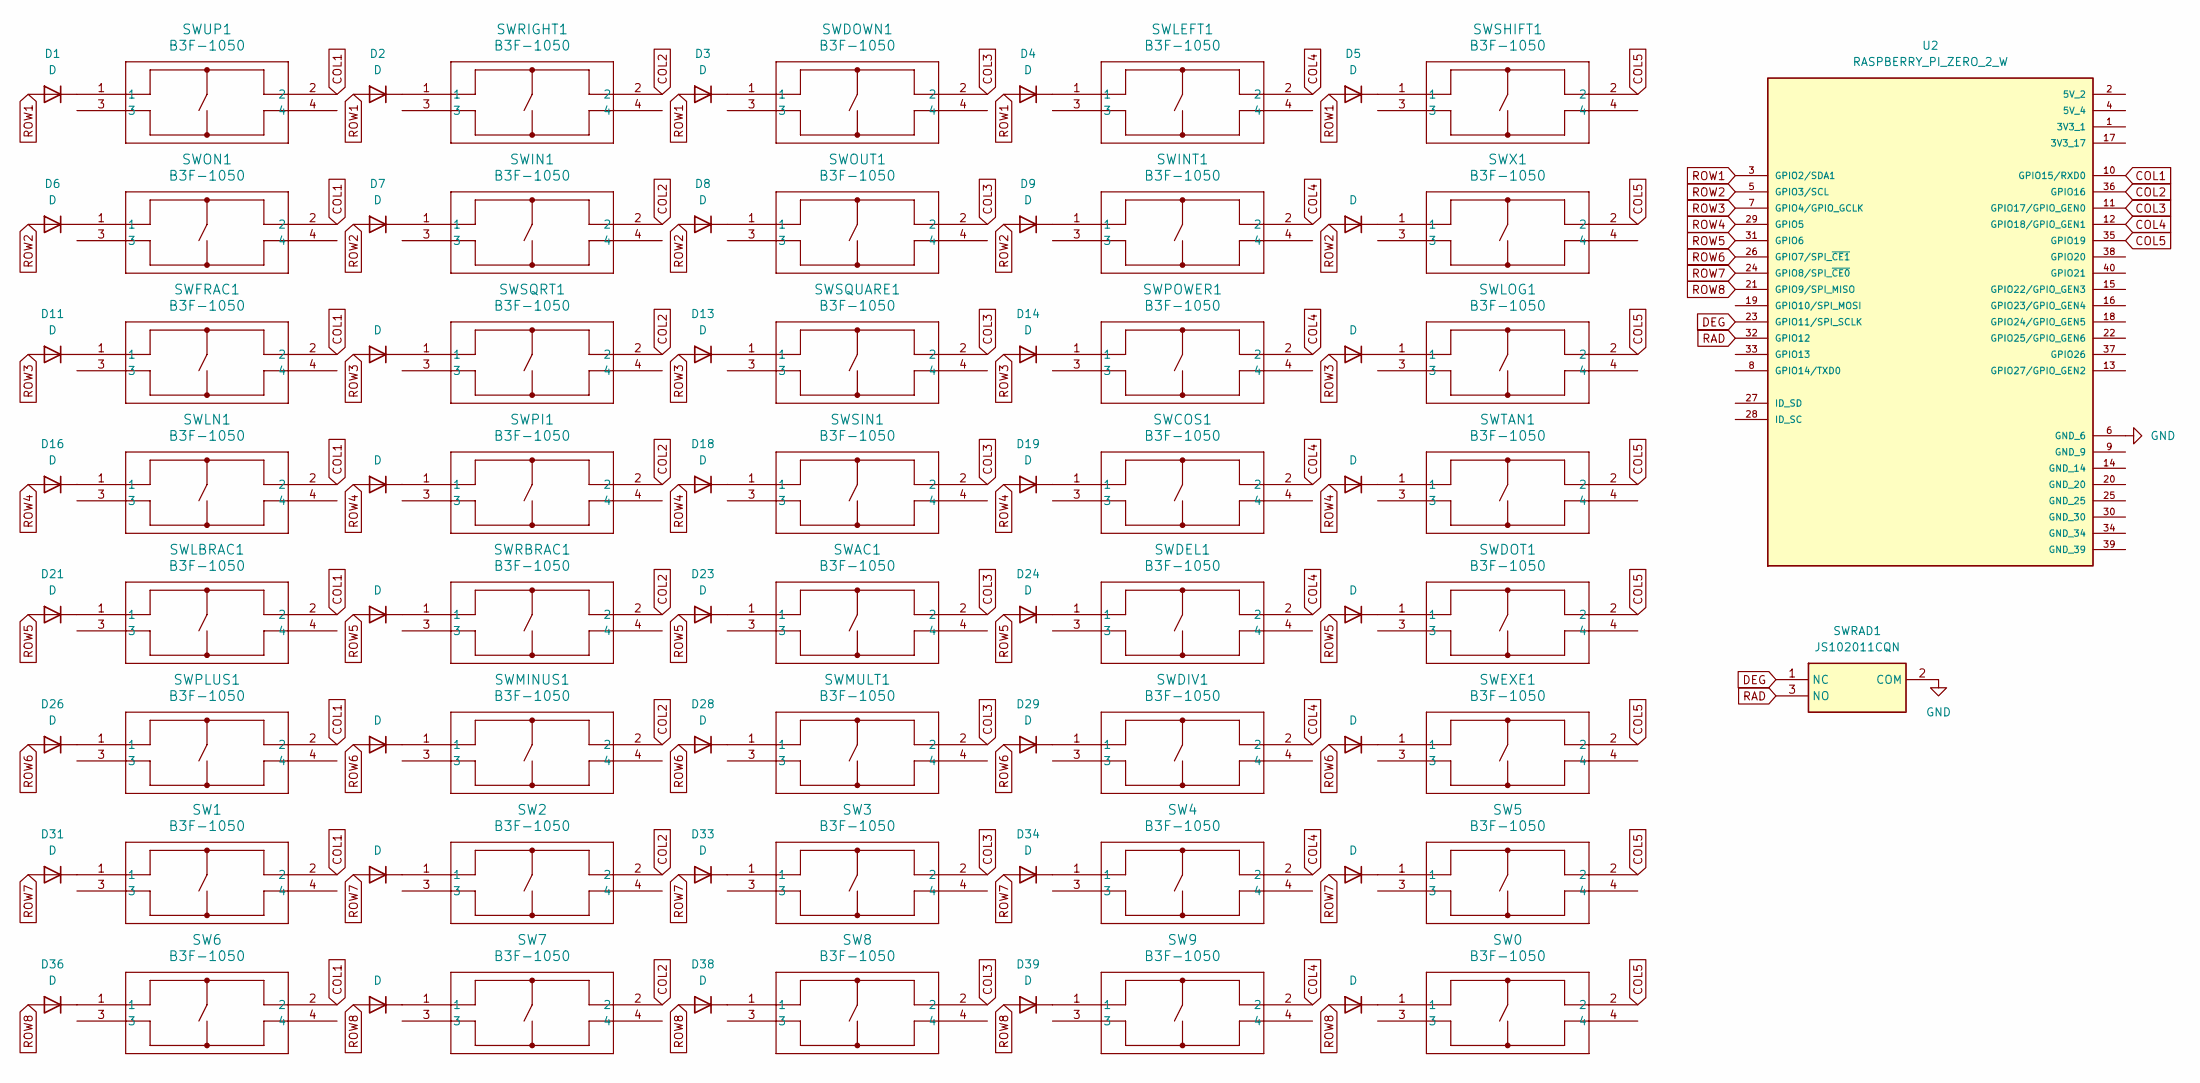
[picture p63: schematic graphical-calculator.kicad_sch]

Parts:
D1, D2, D3, D4, D5, D6, D7, D8, D9, D10, D11, D12, D13, D14, D15, D16, D17, D18, D19, D20, D21, D22, D23, D24, D25, D26, D27, D28, D29, D30, D31, D32, D33, D34, D35, D36, D37, D38, D39, D40: D; DIOAD1300W80L670D310
SW0, SW1, SW2, SW3, SW4, SW5, SW6, SW7, SW8, SW9: B3F-1050; SW_B3F-1050_OMR
SWAC1: B3F-1050; SW_B3F-1050_OMR
SWCOS1: B3F-1050; SW_B3F-1050_OMR
SWDEL1: B3F-1050; SW_B3F-1050_OMR
SWDIV1: B3F-1050; SW_B3F-1050_OMR
SWDOT1: B3F-1050; SW_B3F-1050_OMR
SWDOWN1: B3F-1050; SW_B3F-1050_OMR
SWEXE1: B3F-1050; SW_B3F-1050_OMR
SWFRAC1: B3F-1050; SW_B3F-1050_OMR
SWIN1: B3F-1050; SW_B3F-1050_OMR
SWINT1: B3F-1050; SW_B3F-1050_OMR
SWLBRAC1: B3F-1050; SW_B3F-1050_OMR
SWLEFT1: B3F-1050; SW_B3F-1050_OMR
SWLN1: B3F-1050; SW_B3F-1050_OMR
SWLOG1: B3F-1050; SW_B3F-1050_OMR
SWMINUS1: B3F-1050; SW_B3F-1050_OMR
SWMULT1: B3F-1050; SW_B3F-1050_OMR
SWON1: B3F-1050; SW_B3F-1050_OMR
SWOUT1: B3F-1050; SW_B3F-1050_OMR
SWPI1: B3F-1050; SW_B3F-1050_OMR
SWPLUS1: B3F-1050; SW_B3F-1050_OMR
SWPOWER1: B3F-1050; SW_B3F-1050_OMR
SWRAD1: JS102011CQN; Manufacturer_Part_Number JS102011CQN; Mouser Part Number 611-JS102011CQN
SWRBRAC1: B3F-1050; SW_B3F-1050_OMR
SWRIGHT1: B3F-1050; SW_B3F-1050_OMR
SWSHIFT1: B3F-1050; SW_B3F-1050_OMR
SWSIN1: B3F-1050; SW_B3F-1050_OMR
SWSQRT1: B3F-1050; SW_B3F-1050_OMR
SWSQUARE1: B3F-1050; SW_B3F-1050_OMR
SWTAN1: B3F-1050; SW_B3F-1050_OMR
SWUP1: B3F-1050; SW_B3F-1050_OMR
SWX1: B3F-1050; SW_B3F-1050_OMR
U2: RASPBERRY_PI_ZERO_2_W; MODULE_RASPBERRY_PI_ZERO_2_W; PARTREV April 2024

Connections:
COL1: SW1.2, SW6.2, SWFRAC1.2, SWLBRAC1.2, SWLN1.2, SWON1.2, SWPLUS1.2, SWUP1.2, U2.10 (GPIO15/RXD0)
COL2: SW2.2, SW7.2, SWIN1.2, SWMINUS1.2, SWPI1.2, SWRBRAC1.2, SWRIGHT1.2, SWSQRT1.2, U2.36 (GPIO16)
COL3: SW3.2, SW8.2, SWAC1.2, SWDOWN1.2, SWMULT1.2, SWOUT1.2, SWSIN1.2, SWSQUARE1.2, U2.11 (GPIO17/GPIO_GEN0)
COL4: SW4.2, SW9.2, SWCOS1.2, SWDEL1.2, SWDIV1.2, SWINT1.2, SWLEFT1.2, SWPOWER1.2, U2.12 (GPIO18/GPIO_GEN1)
COL5: SW0.2, SW5.2, SWDOT1.2, SWEXE1.2, SWLOG1.2, SWSHIFT1.2, SWTAN1.2, SWX1.2, U2.35 (GPIO19)
DEG: SWRAD1.1 (NC), U2.23 (GPIO11/SPI_SCLK)
GND: SWRAD1.2 (COM), U2.6 (GND_6)
unnamed: D1.1 (K), SWUP1.1
unnamed: D2.1 (K), SWRIGHT1.1
unnamed: D3.1 (K), SWDOWN1.1
unnamed: D4.1 (K), SWLEFT1.1
unnamed: D5.1 (K), SWSHIFT1.1
unnamed: D6.1 (K), SWON1.1
unnamed: D7.1 (K), SWIN1.1
unnamed: D8.1 (K), SWOUT1.1
unnamed: D9.1 (K), SWINT1.1
unnamed: D10.1 (K), SWX1.1
unnamed: D11.1 (K), SWFRAC1.1
unnamed: D12.1 (K), SWSQRT1.1
unnamed: D13.1 (K), SWSQUARE1.1
unnamed: D14.1 (K), SWPOWER1.1
unnamed: D15.1 (K), SWLOG1.1
unnamed: D16.1 (K), SWLN1.1
unnamed: D17.1 (K), SWPI1.1
unnamed: D18.1 (K), SWSIN1.1
unnamed: D19.1 (K), SWCOS1.1
unnamed: D20.1 (K), SWTAN1.1
unnamed: D21.1 (K), SWLBRAC1.1
unnamed: D22.1 (K), SWRBRAC1.1
unnamed: D23.1 (K), SWAC1.1
unnamed: D24.1 (K), SWDEL1.1
unnamed: D25.1 (K), SWDOT1.1
unnamed: D26.1 (K), SWPLUS1.1
unnamed: D27.1 (K), SWMINUS1.1
unnamed: D28.1 (K), SWMULT1.1
unnamed: D29.1 (K), SWDIV1.1
unnamed: D30.1 (K), SWEXE1.1
unnamed: D31.1 (K), SW1.1
unnamed: D32.1 (K), SW2.1
unnamed: D33.1 (K), SW3.1
unnamed: D34.1 (K), SW4.1
unnamed: D35.1 (K), SW5.1
unnamed: D36.1 (K), SW6.1
unnamed: D37.1 (K), SW7.1
unnamed: D38.1 (K), SW8.1
unnamed: D39.1 (K), SW9.1
unnamed: D40.1 (K), SW0.1
RAD: SWRAD1.3 (NO), U2.32 (GPIO12)
ROW1: D1.2 (A), D2.2 (A), D3.2 (A), D4.2 (A), D5.2 (A), U2.3 (GPIO2/SDA1)
ROW2: D6.2 (A), D7.2 (A), D8.2 (A), D9.2 (A), D10.2 (A), U2.5 (GPIO3/SCL)
ROW3: D11.2 (A), D12.2 (A), D13.2 (A), D14.2 (A), D15.2 (A), U2.7 (GPIO4/GPIO_GCLK)
ROW4: D16.2 (A), D17.2 (A), D18.2 (A), D19.2 (A), D20.2 (A), U2.29 (GPIO5)
ROW5: D21.2 (A), D22.2 (A), D23.2 (A), D24.2 (A), D25.2 (A), U2.31 (GPIO6)
ROW6: D26.2 (A), D27.2 (A), D28.2 (A), D29.2 (A), D30.2 (A), U2.26 (GPIO7/SPI_~CE1)
ROW7: D31.2 (A), D32.2 (A), D33.2 (A), D34.2 (A), D35.2 (A), U2.24 (GPIO8/SPI_~CE0)
ROW8: D36.2 (A), D37.2 (A), D38.2 (A), D39.2 (A), D40.2 (A), U2.21 (GPIO9/SPI_MISO)

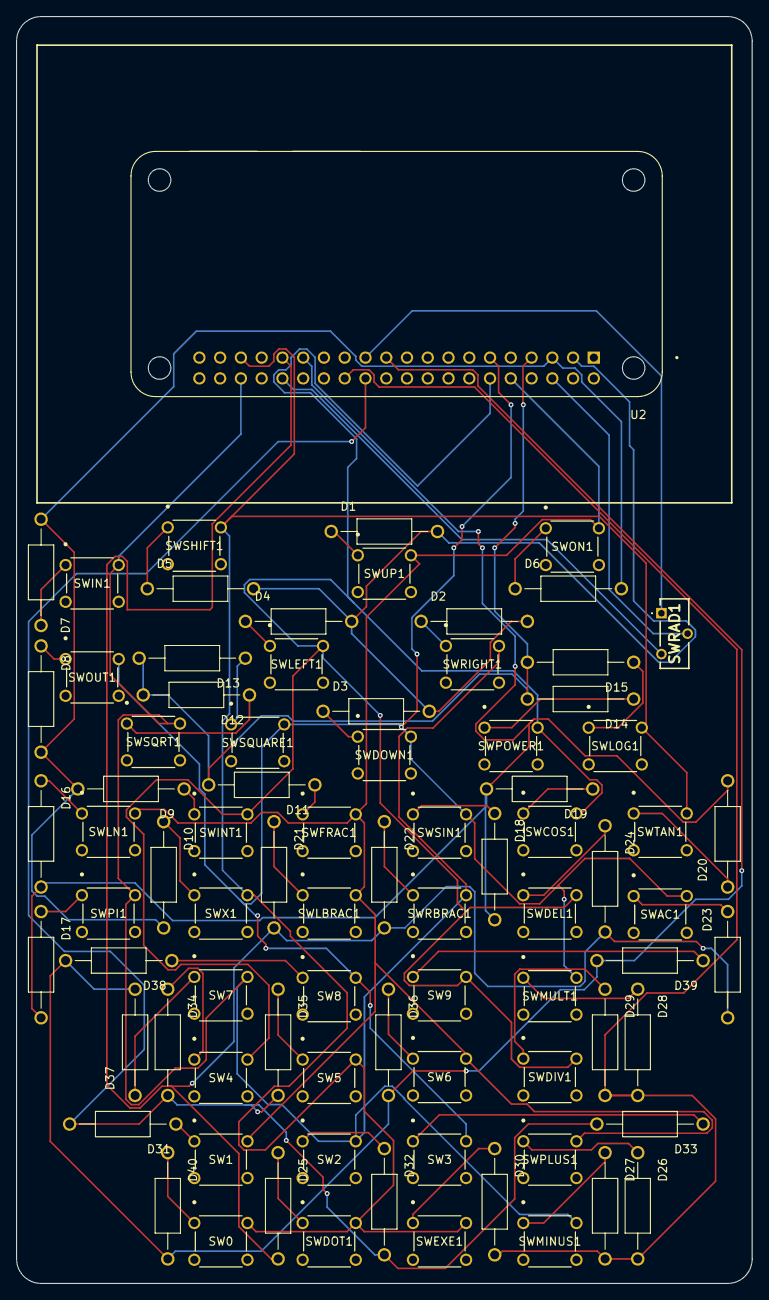
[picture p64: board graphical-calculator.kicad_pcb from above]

Board: 2 copper layers, 90.0 x 155.0 mm, 82 parts (0 on the bottom side), 56 nets.

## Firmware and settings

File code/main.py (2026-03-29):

import pygame

import constants
import evaluator
import expression_tree


constants.precedences_setup()

display_mode = "input"
functions = [expression_tree.Expression() for _ in range(7)]
for function in functions:
    function.parent = function
cursors = [expression_tree.Cursor(functions[_]) for _ in range(7)]
view_window = [str(i) for i in [constants.XMIN, constants.XMAX, constants.YMIN, constants.YMAX]]
selected = 0
cursor_active = True
shift_mode = False
angle_mode = "RAD"


pygame.init()
screen = pygame.display.set_mode((constants.WIDTH, constants.HEIGHT))
running = True

import input_display
import graph_display

def render_graphs(graphs):
    for index in range(len(graphs)):
        graph = graphs[index]
        if graph.objects:
            evaluated = graph.evaluate(angle_mode)
            points = evaluator.create_points(evaluated)
            graph_display.plot_graph(screen, points, constants.COLOURS[index])


input_display.update_screen(screen, functions, selected, view_window, cursors, cursor_active, shift_mode, angle_mode)
pygame.display.update()


while running:
    for event in pygame.event.get(): 
        if event.type == pygame.QUIT:
            running = False
            pygame.quit()

        elif event.type == pygame.KEYDOWN:
            key = pygame.key.name(event.key)
            token = constants.KEY_MAP[key]
            if type(token) == list:
                token = token[shift_mode]
            if token != "SHIFT":
                shift_mode = False

            if display_mode == "input":
                if cursor_active == True:
                    if selected < 7:
                        if token in constants.BINARY_OPERATORS:
                            if token == "RADICAL":
                                operator = expression_tree.Radical()
                            elif token == "FRACTION":
                                operator = expression_tree.Fraction()
                            elif token == "LOG":
                                operator = expression_tree.Log()
                            elif token == "EXPONENT":
                                operator = expression_tree.Exponent()
                                arg = cursors[selected].expression.objects.pop(-1)
                                operator.left.update(arg)
                                cursors[selected].position -= 1
                            cursors[selected].expression.update(operator, cursors[selected].position)
                            cursors[selected].expression = operator.left
                            if token == "EXPONENT":
                                cursors[selected].expression = operator.right
                            cursors[selected].position = 0
                        elif token in constants.UNARY_OPERATORS:
                            if token == "SQRT":
                                operator = expression_tree.SquareRoot()
                            elif token == "CBRT":
                                operator = expression_tree.CubeRoot()
                            elif token in constants.TRIG:
                                operator = expression_tree.Trig(token)
                            elif token == "LN":
                                operator = expression_tree.Ln()
                            elif token == "LOG10":
                                operator = expression_tree.Log10()
                            elif token == "SQUARED":
                                operator = expression_tree.Squared()
                                arg = cursors[selected].expression.objects.pop(-1)
                                operator.operand.update(arg)
                                cursors[selected].position -= 1
                            elif token == "CUBED":
                                operator = expression_tree.Cubed()
                                arg = cursors[selected].expression.objects.pop(-1)
                                operator.operand.update(arg)
                                cursors[selected].position -= 1
                            cursors[selected].expression.update(operator, cursors[selected].position)
                            cursors[selected].expression = operator.operand
                            cursors[selected].position = 0
                            if token == "SQUARED" or token == "CUBED":
                                cursors[selected].position = 1
                        elif token in constants.NUMBERS:
                            cursors[selected].expression.update(expression_tree.Number(token), cursors[selected].position)
                            cursors[selected].position += 1
                        elif token in constants.SYMBOLS:
                            cursors[selected].expression.update(expression_tree.Symbol(token), cursors[selected].position)
                            cursors[selected].position += 1
                        elif token in constants.VARIABLES:
                            if token == "x":
                                cursors[selected].expression.update(expression_tree.Variable(token), cursors[selected].position)
                            else:
                                cursors[selected].expression.update(expression_tree.Constant(token), cursors[selected].position)
                            cursors[selected].position += 1
                        elif token in constants.BRACKETS:
                            cursors[selected].expression.update(expression_tree.Bracket(token), cursors[selected].position)
                            cursors[selected].position += 1
                        elif token in constants.ARROWS:
                            if token == "LEFT":
                                cursors[selected].move_left()
                            elif token == "RIGHT":
                                cursors[selected].move_right()
                        elif token == "DEL":
                            if cursors[selected].position > 0:
                                cursors[selected].expression.update("DEL", cursors[selected].position)
                                cursors[selected].position -= 1
                        elif token == "EXE":
                            cursor_active = False
                        elif token == "AC":
                            function = expression_tree.Expression()
                            function.parent = function
                            functions[selected] = function
                            cursors[selected] = expression_tree.Cursor(function)

                    else:
                        if token in constants.NUMBERS or token == '-':
                            view_window[selected-7] = view_window[selected-7].replace('|',token+'|')
                        elif token == "DEL":
                            view_window[selected-7] = view_window[selected-7][0:-2]+'|'
                        elif token == "EXE":
                            view_window[selected-7] = view_window[selected-7][0:-1]
                            try:
                                constants.XMIN, constants.XMAX, constants.YMIN, constants.YMAX = [float(i) for i in view_window]
                            except:
                                constants.XMIN, constants.XMAX, constants.YMIN, constants.YMAX = -15, 15, -10, 10
                            constants.update_bounds()
                            view_window = [str(i) for i in [constants.XMIN, constants.XMAX, constants.YMIN, constants.YMAX]]
                            cursor_active = False
                        elif token == "AC":
                            view_window[selected-7] = '|'


                elif cursor_active == False:
                    if token in constants.ARROWS:
                        selected, cursor_active, view_window = input_display.move(token, functions, cursors, selected, cursor_active, view_window)
                    elif token == "EXE":
                        display_mode = "graph"

                if token == "SHIFT":
                    shift_mode = not shift_mode

                if token == "ANGLE":
                    if angle_mode == "RAD":
                        angle_mode = "DEG"
                    else:
                        angle_mode = "RAD"

                if display_mode == 'input':
                    input_display.update_screen(screen, functions, selected, view_window, cursors, cursor_active, shift_mode, angle_mode)
                    pygame.display.update()
                elif display_mode == 'graph':
                    graph_display.update_screen(screen)
                    render_graphs(functions)
                    pygame.display.update()

            elif display_mode == "graph":
                if token == "EXE":
                    display_mode = 'input'
                    input_display.update_screen(screen, functions, selected, view_window, cursors, cursor_active, shift_mode, angle_mode)
                    pygame.display.update()

                elif token in constants.ARROWS or token in constants.ZOOM:
                    if token in constants.ARROWS:
                        graph_display.move(token)
                    elif token == "ZOOM_IN":
                        graph_display.zoom('IN')
                    elif token == "ZOOM_OUT":
                        graph_display.zoom('OUT')

                    graph_display.update_screen(screen)
                    render_graphs(functions)
                    pygame.display.update()

            
            if token == "OFF":
                running = False
                pygame.quit()

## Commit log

2025-07-22 created parser for polynomials, currently implements +,-,/,*,(),^,x
2025-07-22 renamed numbers to operands because 🤓☝️
2025-07-27 created schematic and pcb
    [graphical-calculator.kicad_pcb, graphical-calculator.kicad_sch, key layout.xlsx]
2025-07-30 update pcb and 3d model
    [300SP1J1BLKM2QE.step, BOM.csv, JS102011CQN.stp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]
2025-07-30 update bom
    [BOM.csv]
2025-07-31 redo board with matrix, tht, cad with screen
    [1N4148 _DO-35_.step, 300SP1J1BLKM2QE.step, BOM.csv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]
2025-08-06 updated render, keycaps and pins
    [BOM.csv, graphical-calculator.kicad_pcb, graphical-calculator.kicad_sch]
2025-09-10 update pcb
2026-02-20 oop yay ig
    [0.1.step, 0.2.step, base-large.3mf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]
2026-02-22 fetched code from rpi with separate folder for code that goes directly to hardware
    [BOM.csv]
2026-02-22 added support for decimal points, unary negation, brackets, changed colours
2026-03-29 complete nea
    [case-new.3mf, case-top-plate-new-new-new.3mf, case-top-plate-new-new.step]
